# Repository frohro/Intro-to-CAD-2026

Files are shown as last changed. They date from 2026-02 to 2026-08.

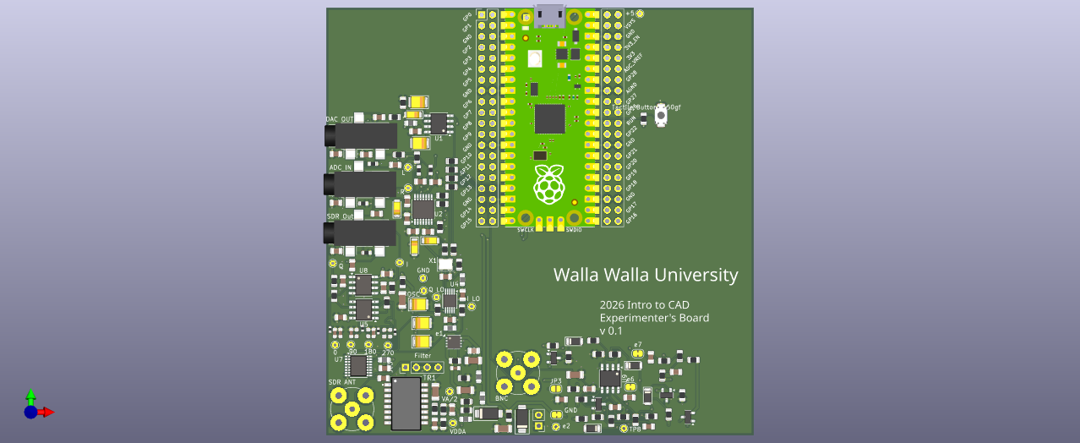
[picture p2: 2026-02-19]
v0.2/Hardware/Intro-to-CAD-2026_Feb_18.png

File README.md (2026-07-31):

# Intro-to-CAD-2026

QSD SDR receiver board (WWU Intro to CAD) with versioned hardware and software.

## Layout

```text
v0.1/                  # First board revision
  Hardware/            # KiCad project for v0.1
  Software/SDR/        # MicroPython, Soapy, firmware/
v0.2/                  # Second board revision (CJC5340 option, etc.)
  Hardware/            # KiCad project for v0.2
  Software/SDR/        # MicroPython, Soapy, firmware/
Docs/                  # Plans, credits, restore notes
```

Pick the **root folder that matches the PCB silkscreen / board revision** you have.

| Board | Open KiCad | Software |
|---|---|---|
| v0.1 | [v0.1/Hardware/Intro-to-CAD-2026.kicad_pro](v0.1/Hardware/Intro-to-CAD-2026.kicad_pro) | [v0.1/Software/SDR](v0.1/Software/SDR) |
| v0.2 | [v0.2/Hardware/Intro-to-CAD-2026.kicad_pro](v0.2/Hardware/Intro-to-CAD-2026.kicad_pro) | [v0.2/Software/SDR](v0.2/Software/SDR) |

Duplication between `v0.1` and `v0.2` is intentional so each board is self-contained.

## Firmware

Native Pico UAC1 projects live under each version's `Software/SDR/firmware/`.
Preferred v0.2 entry point: `v0.2/Software/SDR/firmware/2026_v0.2/`.
Re-sync notes: [Docs/FIRMWARE_RESTORE.md](Docs/FIRMWARE_RESTORE.md).

## History

- Tag `archive/pre-version-split` — layout before this reorg (student `Module_*` at repo root).
- Long-lived git branch `v0.2` held hardware work before the monorepo split; prefer paths under `v0.2/` on `master` going forward.
- Student module credits: [Docs/CREDITS.md](Docs/CREDITS.md).

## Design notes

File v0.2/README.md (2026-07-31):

# Board v0.2

## Hardware

Open [`Hardware/Intro-to-CAD-2026.kicad_pro`](Hardware/Intro-to-CAD-2026.kicad_pro).

Includes dual-ADC options (PCM1808 preferred; CJC5340 retained). Instructor
`Hardware/Frohne/` libs remain because the merged schematic references them.

## Software

| Path | Role |
|---|---|
| `Software/SDR/MicroPythonSDR/` | Pico MicroPython + Quisk helpers |
| `Software/SDR/Soapy-For-2026-Board/` | Soapy module |
| `Software/SDR/firmware/` | C UAC1 firmwares (PCM1808, CJC, Multi) — restore if empty |

Preferred firmware entry point once restored: `firmware/2026_v0.2/` (PCM1808 48/96).
CJC and Multi trees are kept for research even if PCM1808 is preferred on the bench.

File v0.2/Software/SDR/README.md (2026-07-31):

# v0.2 Software / SDR

- **MicroPythonSDR/** — board Python, Quisk configs/widgets (copy shared with v0.1 tree)
- **Soapy-For-2026-Board/** — SoapySDR support module
- **firmware/** — native Pico UAC1 projects

ADC preference: **PCM1808**. CJC5340 and Multi-ADC firmwares are retained under
`firmware/` for future investigation.

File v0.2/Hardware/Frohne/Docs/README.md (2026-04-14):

# Project Documentation: Parallel Summation QSD SDR 

## 1. System Architecture
This receiver is a high-performance Direct Conversion SDR utilizing a **Quadrature Sampling Detector (QSD)** architecture. The design is optimized for high conversion gain and low noise by prioritizing signal symmetry and high-impedance buffering.

## 2. RF Front-End & Mixer
*   **Parallel Summation Mixer:** A modified Tayloe mixer design using a center-tapped 1:1+1 transformer and a dual 1:4 bus switch (**SN74CBT3253**). 
*   **Sampling Logic:** Each I/Q channel samples the transformer secondary twice per LO cycle (I samples at 0° and 180°; Q samples at 90° and 270°). This architecture increases sampling efficiency compared to standard single-sample designs.
*   **Sampling Capacitors:** Utilizes **C0G/NP0** dielectrics (10nF) to ensure linear tracking of the RF signal and to minimize parasitic effects from the CMOS switches.

## 3. Analog Baseband (Instrumentation Amplifier)
*   **Topology:** Each channel (I and Q) utilizes one **OPA1612** dual op-amp package configured as a **2-Op-Amp Instrumentation Amplifier**.
*   **High-Z Buffering:** The sampling capacitors feed directly into non-inverting op-amp inputs. This high-impedance interface prevents "charge sharing" or coupling between phases, preserving the 90° quadrature relationship at high frequencies.
*   **Differential Summation:** The first op-amp acts as a buffer for the negative phase, while the second op-amp performs the subtraction and provides the primary system gain.
*   **Virtual Ground:** A 2.25V bias is provided to the transformer center-tap. Because of the balanced In-Amp design, current demand on this virtual ground is minimized, reducing crosstalk.

## 4. Clocking and Synchronization
*   **Synchronous Clocking:** A single **24.576 MHz CMOS oscillator** serves as the master reference for the entire system.
*   **Local Oscillator:** The clock drives an **MS5351M** (Si5351A) synthesizer to generate the quadrature LO signals.
*   **ADC Clocking:** The same 24.576 MHz source drives the **PCM1808 ADC** (SCKI). This frequency-locks the RF mixing to the digital sampling, eliminating relative frequency drift.

## 5. Power Management and Noise Isolation
*   **Dual Power Path:** A **PMOSFET-based "Ideal Diode"** circuit automatically switches between USB power and an external clean 12V supply. The PMOS prevents high-voltage back-feeding into the USB port while maintaining maximum headroom for the regulators when on USB power.
*   **Analog Regulation:** An **SGM2205** high-voltage LDO provides a quiet 4.5V rail. It features a large **Feed-Forward capacitor ($C_{ff}$)** and a **bulk tantalum reservoir** (isolated by 1$\Omega$) to suppress low-frequency supply noise.
*   **EMI Suppression:** Digital and analog zones are isolated using **ferrite beads** in a star configuration. I2C lines to the LO include series damping resistors to "soften" digital edges and reduce harmonic interference.

## 6. Digital Interface
*   **ADC:** **PCM1808** 24-bit Sigma-Delta converter operating in **Master Mode**.
*   **MCU:** **Raspberry Pi Pico** operating as an **I2S Slave**. Data is captured via PIO state machines and streamed over USB or WiFi (UDP) for processing.
*   **DAC:**  **CJC4334H** a 24 bit DAC with a line level output, and an amplified (suitable for headphones) output.

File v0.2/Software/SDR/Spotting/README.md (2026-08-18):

# WWU 2026 SDR Harvester and Spotting Pipeline

This directory contains a multi-radio receive pipeline for WWU 2026 SDR boards.

The C++ harvester opens one SoapySDR stream per configured radio, captures 96 kHz complex I/Q, translates each requested RF offset to a nonzero audio IF, removes DC, decimates to 12 kHz, and writes UTC-aligned mono WAV files.

The Python reporter watches completed WAV files, runs `jt9` or `wsprd`, parses spots, optionally submits them to PSKReporter, and removes processed or stale files from the capture directory.

The sample configuration enables FT8 and FT4. WSPR is supported but disabled in `config.json` because WSPR frames are 120 seconds long.

## Files

| File | Purpose |
|---|---|
| `config.json` | Capture directory, sample rates, radios, RF centers, mode offsets, and audio IFs |
| `harvester.cpp` | Capture, DSP, UTC framing, and WAV output |
| `CMakeLists.txt` | Builds the C++ harvester |
| `reporter.json` | Callsign/grid, decoder, cleanup, and PSKReporter settings |
| `reporter.py` | Decode, deduplicate, report, and cleanup daemon |
| `cleanup_capture.py` | Manual removal of old or abandoned capture files |
| `build/harvester` | Compiled executable produced by CMake |

The SoapySDR board driver is a separate project in `../Soapy-For-2026-Board` and must be installed first.

## Hardware prerequisites

Each board needs both interfaces available to Ubuntu:

1. USB CDC serial, normally `/dev/ttyACM0`, for firmware control and tuning.
2. USB ALSA capture audio for stereo I/Q.

Check the board with:

```sh
lsusb
ls -l /dev/ttyACM*
cat /proc/asound/cards
cat /proc/asound/cardN/stream0
SoapySDRUtil --find="driver=2026sdr"
```

The audio interface must list 96000 Hz. If it lists only 48000 Hz, set the board's MD1 jumper HIGH or install the 96 kHz firmware variant.

Verify the driver before running the harvester:

```sh
cd ../Soapy-For-2026-Board
python3 test_driver.py --rate 96000 --freq 14074000
```

The test should report `Actual rate: 96000 Hz` and `PASS`.

## Packages

On Ubuntu/Debian:

```sh
sudo apt update
sudo apt install \
  build-essential cmake pkg-config g++ \
  libsoapysdr-dev soapysdr-tools python3-soapysdr \
  libliquid-dev libsndfile1-dev nlohmann-json3-dev \
  libasound2-dev libusb-1.0-0-dev \
  wsjtx python3-watchdog
```

If `python3-watchdog` is unavailable:

```sh
python3 -m pip install --user watchdog
```

Check the required programs and Python import:

```sh
command -v cmake jt9 wsprd SoapySDRUtil
python3 -c 'import watchdog; print("watchdog OK")'
```

The current reporter uses Python's standard library plus `watchdog`. It does not require `requests`.

## Build

From this directory:

```sh
cmake -S . -B build
cmake --build build -j4
```

Re-run the build after changing `harvester.cpp` or `CMakeLists.txt`.

## Configure one radio

Example `config.json`:

```json
{
  "output_dir": "/home/frohro/Projects/Intro-to-CAD-2026/v0.2/Software/SDR/Spotting/captures",
  "sample_rate": 96000,
  "output_rate": 12000,
  "sdrs": [
    {
      "sdr_id": "Board_1",
      "serial_port": "/dev/ttyACM0",
      "audio_label": "S2026",
      "center_freq": 14074000,
      "modes": [
        { "mode": "FT8", "offset": 0, "audio_if": 1500 },
        { "mode": "FT4", "offset": 6000, "audio_if": 1500 }
      ]
    }
  ]
}
```

Meanings:

- `output_dir` is the directory used for temporary and completed WAV files. The current configuration uses persistent storage under the project directory.
- `sdr_id` is unique and becomes part of every WAV filename.
- `serial_port` selects the board's CDC port.
- `audio_label` is a case-insensitive ALSA-card search string.
- `center_freq` is the programmed RF center in Hz.
- A positive `offset` means the target RF signal is `center_freq + offset`.
- `audio_if` is the target frequency in the 12 kHz WAV. Use a nonzero value such as 1500 Hz to avoid DC and 1/f noise.
- The NCO frequency is `(audio_if - offset) / 96000`.

The current DSP chain includes a DC blocker, a 0.05 normalized anti-alias filter, decimation by 8, and monitoring gain in the WAV writer. Watch for clipping if changing gain.

Use `output_dir` in both JSON files whenever the capture location changes.

## Configure multiple radios

Add one object per board to the `sdrs` array. Each entry needs a unique `sdr_id`, serial port, and ALSA label:

```json
{
  "sdr_id": "Board_2",
  "serial_port": "/dev/ttyACM1",
  "audio_label": "S2026_1",
  "center_freq": 21107000,
  "modes": [
    { "mode": "FT8", "offset": -33000, "audio_if": 1500 },
    { "mode": "FT4", "offset": 33000, "audio_if": 1500 }
  ]
}
```

This example puts 15 m FT8 at 21.074 MHz and 15 m FT4 at 21.140 MHz in the same 96 kHz capture window. Use udev rules for stable serial names when possible. Inspect `/proc/asound/cards` after both boards are plugged in and replace `/dev/ttyACM1` and `S2026_1` with the actual second-board identifiers. Do not map two entries to the same serial device or ALSA card.

The harvester creates one thread and one SoapySDR stream per `sdrs` entry. Example output names:

```text
Board_1_FT8_20260813T001500Z.wav
Board_2_FT8_20260813T001500Z.wav
```

### Missing or mismatched radio behavior

Each radio worker is isolated. If a configured serial port, ALSA label, or Soapy stream cannot be opened, the harvester logs the radio ID and retries that radio every five seconds. Other radios continue capturing, and the missing radio can recover automatically when it is connected later. A failed or disconnected radio does not publish an incomplete WAV frame; any `.wav.part` file for that frame is discarded.

The `/dev/ttyACM0`, `/dev/ttyACM1`, and similar numbers are assigned by Ubuntu and can change when boards are unplugged or reconnected. A path that exists may still refer to the wrong physical board. For reliable multi-radio operation, create stable udev symlinks based on each board's USB identity and use those symlinks in `config.json`. Also verify that every board has a distinct ALSA `audio_label`.

## Manual Si5351 tuning

The planned JSON shape for manual PLL/register values is:

```json
"si5351": {
  "si5351_hz": 7074000,
  "N": 86,
  "a": 24,
  "b": 0,
  "c": 1,
  "p1": 2560,
  "p2": 0,
  "p3": 1
}
```

The current harvester does not yet pass this object to `setFrequency()`. Until the Soapy driver and harvester are updated together, the driver calculates Si5351 parameters automatically. Do not use the example values blindly.

## Configure reporter.json

Edit the receiver identity:

```json
{
  "output_dir": "/home/frohro/Projects/Intro-to-CAD-2026/v0.2/Software/SDR/Spotting/captures",
  "harvester_config": "config.json",
  "callsign": "KL7NA",
  "grid": "DN06",
  "decode_timeout": 180,
  "stale_file_seconds": 900,
  "cleanup_interval_seconds": 60,
  "pskreporter": {
    "enabled": true,
    "host": "report.pskreporter.info",
    "port": 4739,
    "identifier": 2026
  }
}
```

Keep PSKReporter disabled until local decoding works. When enabled, `reporter.py` sends UDP packets to `report.pskreporter.info:4739`.

The reporter reads `config.json` through `harvester_config`, so it can reconstruct RF frequency from each WAV:

```text
RF frequency = center_freq + offset + decoded_audio_frequency - audio_if
```

## Start the pipeline

Start the reporter first:

```sh
cd /home/frohro/Projects/Intro-to-CAD-2026/v0.2/Software/SDR/Spotting
python3 reporter.py --config reporter.json
```

In a second terminal, start the harvester:

```sh
cd /home/frohro/Projects/Intro-to-CAD-2026/v0.2/Software/SDR/Spotting
./build/harvester config.json
```

The harvester writes `.wav.part` while a frame is being written and atomically renames it to `.wav` when complete. The reporter handles both normal creation and atomic move events. It also processes existing WAV files when it starts.

Stop either daemon with `Ctrl-C`. The harvester does not publish incomplete frames.

## Capture storage

Each frame is a short, sequential 12 kHz WAV file, and the reporter normally deletes it immediately after decoding. A local SSD is the recommended default; an older spinning disk should also work because the data rate is low and decode latency is not critical.

The current configuration uses:

```text
/home/frohro/Projects/Intro-to-CAD-2026/v0.2/Software/SDR/Spotting/captures
```

Create it once if necessary:

```sh
mkdir -p /home/frohro/Projects/Intro-to-CAD-2026/v0.2/Software/SDR/Spotting/captures
```

If the storage location changes, update `output_dir` in both `config.json` and `reporter.json` to the same writable directory.

## Run automatically with systemd

The recommended setup uses per-user systemd services. This keeps the daemons running as your normal user, which is important for access to the USB serial and ALSA devices.

Create the user-service directory:

```sh
mkdir -p ~/.config/systemd/user
```

Create `~/.config/systemd/user/wwu2026-reporter.service`:

```ini
[Unit]
Description=WWU 2026 SDR spot reporter
After=network-online.target
Wants=network-online.target

[Service]
Type=simple
WorkingDirectory=/home/frohro/Projects/Intro-to-CAD-2026/v0.2/Software/SDR/Spotting
ExecStart=/usr/bin/python3 /home/frohro/Projects/Intro-to-CAD-2026/v0.2/Software/SDR/Spotting/reporter.py --config /home/frohro/Projects/Intro-to-CAD-2026/v0.2/Software/SDR/Spotting/reporter.json
Restart=on-failure
RestartSec=5

[Install]
WantedBy=default.target
```

Create `~/.config/systemd/user/wwu2026-harvester.service`:

```ini
[Unit]
Description=WWU 2026 SDR harvester
After=wwu2026-reporter.service
Wants=wwu2026-reporter.service

[Service]
Type=simple
WorkingDirectory=/home/frohro/Projects/Intro-to-CAD-2026/v0.2/Software/SDR/Spotting
ExecStart=/home/frohro/Projects/Intro-to-CAD-2026/v0.2/Software/SDR/Spotting/build/harvester /home/frohro/Projects/Intro-to-CAD-2026/v0.2/Software/SDR/Spotting/config.json
Restart=on-failure
RestartSec=5

[Install]
WantedBy=default.target
```

Reload, enable, and start both services:

```sh
systemctl --user daemon-reload
systemctl --user enable --now wwu2026-reporter.service
systemctl --user enable --now wwu2026-harvester.service
```

Check status and follow logs:

```sh
systemctl --user status wwu2026-reporter.service
systemctl --user status wwu2026-harvester.service
journalctl --user -u wwu2026-reporter.service -f
journalctl --user -u wwu2026-harvester.service -f
```

Stop or disable them:

```sh
systemctl --user disable --now wwu2026-harvester.service wwu2026-reporter.service
```

For services to start even when you are not logged into a graphical session, enable user lingering once:

```sh
sudo loginctl enable-linger frohro
```

If the harvester cannot open `/dev/ttyACM0` or the ALSA device under systemd, verify that your user has the required `dialout` and `audio` group membership, then log out and back in:

```sh
groups
sudo usermod -aG dialout,audio frohro
```

## What the scripts do

### `harvester.cpp`

For every configured radio it:

1. Creates a `2026sdr` Soapy device.
2. Sets 96 kHz capture and the configured RF center.
3. Creates an NCO and FIR decimator branch for every requested mode.
4. Removes DC and translates the requested RF offset to `audio_if`.
5. Decimates 96 kHz to 12 kHz.
6. Writes real-valued 16-bit mono WAV frames aligned to UTC boundaries.

FT8 frames are 15 seconds, FT4 frames are 7.5 seconds, and WSPR frames are 120 seconds.

### `reporter.py`

For each complete WAV it:

1. Identifies FT8, FT4, or WSPR from the filename.
2. Runs `jt9 -8`, `jt9 -5`, or `wsprd`.
3. Parses callsign, grid, SNR, and audio frequency.
4. Suppresses duplicate `(frame, mode, callsign, frequency)` spots.
5. Logs accepted spots.
6. Optionally sends them to PSKReporter.
7. Deletes the WAV after decoding.

If decoding fails or times out, the WAV remains until stale-file cleanup removes it.

### `cleanup_capture.py`

Remove only files older than 15 minutes:

```sh
python3 cleanup_capture.py --directory /home/frohro/Projects/Intro-to-CAD-2026/v0.2/Software/SDR/Spotting/captures --older-than 900
```

Remove all WAV and partial files after stopping both daemons:

```sh
python3 cleanup_capture.py --directory /home/frohro/Projects/Intro-to-CAD-2026/v0.2/Software/SDR/Spotting/captures --all
```

The reporter also performs automatic cleanup according to `stale_file_seconds` and `cleanup_interval_seconds`.

## Testing without an antenna

Do not run the reporter for this test if you want to keep the WAV files:

```sh
python3 cleanup_capture.py --directory /home/frohro/Projects/Intro-to-CAD-2026/v0.2/Software/SDR/Spotting/captures --all
timeout --signal=INT 40s ./build/harvester config.json
find /home/frohro/Projects/Intro-to-CAD-2026/v0.2/Software/SDR/Spotting/captures -maxdepth 1 -type f -name '*.wav' -printf '%f %s bytes\n' | sort
file /home/frohro/Projects/Intro-to-CAD-2026/v0.2/Software/SDR/Spotting/captures/*.wav
```

You can listen with:

```sh
aplay /home/frohro/Projects/Intro-to-CAD-2026/v0.2/Software/SDR/Spotting/captures/Board_1_FT8_*.wav
```

No antenna normally produces thermal noise and receiver artifacts rather than decodes.

## Troubleshooting

### No Soapy device

```sh
SoapySDRUtil --find="driver=2026sdr"
SoapySDRUtil --make="driver=2026sdr,serial_port=/dev/ttyACM0,audio_label=S2026"
```

Check udev permissions, `/dev/ttyACM*`, `/proc/asound/cards`, and `SoapySDRUtil --info`.

### 96 kHz fails

```sh
cat /proc/asound/cardN/stream0
```

The capture interface must list a 96000 Hz alternate setting. Check the MD1 jumper or board firmware.

### No WAV files

Run the harvester in the foreground and verify the capture directory:

```sh
mkdir -p /home/frohro/Projects/Intro-to-CAD-2026/v0.2/Software/SDR/Spotting/captures
test -w /home/frohro/Projects/Intro-to-CAD-2026/v0.2/Software/SDR/Spotting/captures && echo writable
```

### WAV files but no spots

Run a decoder manually:

```sh
jt9 -8 /home/frohro/Projects/Intro-to-CAD-2026/v0.2/Software/SDR/Spotting/captures/Board_1_FT8_YYYYMMDDTHHMMSSZ.wav
jt9 -5 /home/frohro/Projects/Intro-to-CAD-2026/v0.2/Software/SDR/Spotting/captures/Board_1_FT4_YYYYMMDDTHHMMSSZ.wav
```

Check mode duration, 12 kHz sample rate, UTC alignment, audio IF, antenna, and RF frequency.

### Local spots but no PSKReporter spots

Set `pskreporter.enabled` to `true`, verify callsign/grid, and check outbound UDP access to `report.pskreporter.info:4739`.

## Time alignment

Frame boundaries use the host system clock in UTC. Keep Ubuntu synchronized with chrony or systemd-timesyncd. The Soapy driver supplies no hardware timestamps, so host-clock timing cannot correct USB/audio-clock latency.

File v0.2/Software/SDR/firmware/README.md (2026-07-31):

# v0.2 SDR firmware

Sources imported from `cptr-480-2026-instructor/Research` (build trees excluded).

| Folder | Description |
|---|---|
| `2026_v0.2/` | PCM1808 48/96 kHz dual-rate UAC1 (**preferred starting point**) |
| `48_kHz_2026_v0.2/` | PCM1808 dual-rate / Johnson-mode variant |
| `96_kHz_2026_v0.2/` | PCM1808 96 kHz |
| `48_kHz_CJC_5340_2026_v0.2/` | CJC5340 48 kHz (research; PCM1808 preferred) |
| `96_kHz_CJC_5340_2026_v0.2/` | CJC5340 96 kHz |
| `192_kHz_CJC_5340_2026_v0.2/` | CJC5340 192 kHz (16-bit USB + dither) |
| `2026_v0.2_Multi/` | Multi-ADC experimental (PCM1808 + CJC5340) |

Build each project with the Pico SDK / CMake flow described in that folder's README.
Do not commit `build/` output.

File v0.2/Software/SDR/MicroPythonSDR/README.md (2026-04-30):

# MicroPythonSDR — Intro-to-CAD-2026 / Cadyn Pico SDR

MicroPython firmware that turns a Raspberry Pi Pico (RP2040) into the
local-oscillator (LO) controller for a Quadrature Sampling Detector (QSD)
SDR receiver.  The Pico tunes the Si5351/MS5351M clock generator to produce
two clocks 90° apart (CLK0 = I, CLK1 = Q) that drive the QSD mixer.  Analog
I/Q audio from the mixer goes to the left/right channels of an external
soundcard, and Quisk (or any compatible SDR program) demodulates it on the PC.

```
RF Antenna
    │
    ▼
H1102NLT (input balun)
    │
    ▼
QSD mixer ◄── CLK0 (0°)  ┐
          ◄── CLK1 (90°) ┘  MS5351M / Si5351A  ◄── I²C (SDA/SCL) ── Pico
    │
    ▼
OPA1612 (I/Q audio amp)
    │
    ▼
3.5 mm stereo jack  ──────► PC soundcard L (I) / R (Q)
                                │
                                ▼
                           Quisk SDR software
                                │
                         USB serial ──► Pico  (FREQ,<hz> commands)
```

---

## Hardware

### Intro-to-CAD-2026 board

| Item | Detail |
|---|---|
| MCU | Raspberry Pi Pico (RP2040) |
| Clock generator | MS5351M (Si5351A-compatible, LCSC C1509083), I²C addr `0x60` |
| I²C pins | **SDA = GPIO 12**, **SCL = GPIO 13** (I²C bus 0) |
| Reference oscillator | 24.576 MHz internal to MS5351M |
| Mixer / amp | OPA1612 dual op-amp in QSD configuration |
| RF input balun | H1102NLT Ethernet transformer |
| Audio output | 3.5 mm stereo jack → external soundcard |
| PCM1808 ADC | Present on board; *not used by this firmware* (future Phase 2) |
| 24.576 MHz CMOS osc | YC24.576MUBCE2O — feeds PCM1808 SCKI only |
| OLED display | SSD1306 on same I²C bus; displays frequency and PLL parameters when connected |

### Cadyn's Pico SDR (reference build)

| Item | Detail |
|---|---|
| Clock generator | Si5351A-B-GT, I²C addr `0x60` |
| I²C pins | **SDA = GPIO 4**, **SCL = GPIO 5** (I²C bus 0) |
| Reference oscillator | ~25 MHz internal crystal (calibrated value in `config.py`) |

---

## OLED Display

The firmware automatically detects and uses an SSD1306 OLED display (128x64 pixels) connected to the same I²C bus as the MS5351M clock generator. The display shows:

- Current frequency in MHz (e.g., "Freq: 7.074 MHz")
- PLL parameters: M (PLL multiplier) and N (output divider)

The display is only updated when the OLED is physically connected; if disconnected, the firmware continues to operate normally without errors.

---

## File layout

```
MicroPythonSDR/
├── 2026_Board/      MicroPython files for Intro-to-CAD-2026 board
│   ├── main.py      Entry point
│   ├── config.py    Board configuration (set to INTRO_CAD_2026)
│   ├── si5351.py    Si5351/MS5351M driver
│   └── radio.py     Radio class
├── Cadyn_Board/     MicroPython files for Cadyn's Pico SDR
│   ├── main.py      Entry point
│   ├── config.py    Board configuration (set to CADYN_PICO_SDR)
│   ├── si5351.py    Si5351/MS5351M driver
│   └── radio.py     Radio class
├── quisk_conf_2026.py     Quisk configuration for 2026 board
├── quisk_conf_cadyn.py    Quisk configuration for Cadyn's board
└── README.md              This file
```

---

## Deployment

### MicroPython Firmware for the Pico

#### 1. Install MicroPython on the Pico

Flash the latest MicroPython UF2 from <https://micropython.org/download/RPI_PICO/>.

#### 2. Choose your board version

- For the **Intro-to-CAD-2026 board**: Use files from `2026_Board/`
- For **Cadyn's Pico SDR**: Use files from `Cadyn_Board/`

#### 3. Copy MicroPython files to the Pico

Using **MicroPico** (VS Code extension) or **Thonny**:

Copy these four files from your chosen board directory to the root (`/`) of the Pico filesystem:

```
main.py
config.py
si5351.py
radio.py
```

The Pico runs `main.py` automatically on power-up.

### Quisk SDR Software Setup

#### 1. Install Quisk

Install Quisk on your computer (Linux recommended):

```bash
sudo apt install quisk  # Ubuntu/Debian
# or
pip install quisk       # from PyPI
```

#### 2. Install Quisk configurations

Copy the appropriate Quisk configuration file to your Quisk config directory:

```bash
# For 2026 board:
cp quisk_conf_2026.py ~/.quisk/

# For Cadyn's board:
cp quisk_conf_cadyn.py ~/.quisk/
```

#### 3. Run Quisk with hardware selection

Launch Quisk and select your radio from the menu:

```bash
quisk -a
```

This opens Quisk with a menu to choose between available hardware configurations. Select the appropriate one for your connected board.

The configurations are named to distinguish between the two radios, allowing you to switch between them easily.

### 4. Verify I²C connectivity

Before running the full firmware, run an I²C scan to confirm the MS5351M
responds at address `0x60`:

```python
from machine import I2C, Pin
i2c = I2C(0, freq=400_000, scl=Pin(13), sda=Pin(12))
print([hex(a) for a in i2c.scan()])   # should include 0x60
```

Paste this into the Pico REPL via Thonny or `mpremote`.

---

## Quisk setup (PC side)

1. Install Quisk: `pip install quisk` (or from <https://james.ahlstrom.name/quisk/>).

2. Run Quisk pointing at `quisk_conf_intro_cad.py` from this directory:
   ```
   quisk --conf /path/to/MicroPythonSDR/quisk_conf_intro_cad.py
   ```
   The file configures:
   - Serial port `/dev/ttyACM0` (or `ttyACM1`) at 115 200 baud
   - PulseAudio soundcard for I/Q capture at 48 kHz
   - `open()` queries `XTAL` to get the crystal reference frequency, sends `RATE,48000`
   - `ChangeFrequency()` searches for the best golden LO on the PC, sends `FREQ,<lo>` to the Pico

   If you change the soundcard sample rate, update `sample_rate` in
   `quisk_conf_intro_cad.py`.

3. Start Quisk.  It will open the serial port, confirm firmware version,
   read the crystal frequency, send the sample rate, and begin sending
   `FREQ,<lo>` commands as you tune.  The Pico responds with the frequency
   and an `OK,G/F/X,<value>` status line.

### Serial command reference

| Command | Response | Notes |
|---|---|---|
| `FREQ,<hz>\n` | `<hz>\nOK,G,<signed_offset>\n` | Tune; `G` = integer PLL, signed_offset = f_lo − f_requested (Hz) |
| `FREQ,<hz>\n` | `<hz>\nOK,F,0\n` | Tune; `F` = fractional PLL (exact frequency, score omitted) |
| `FREQ,<hz>\n` | `<hz>\nOK,X,0\n` | Tune; `X` = fallback, VCO out of spec |
| `FREQ,\n` | `<current hz>\nOK,...\n` | Query current frequency |
| `RATE,<hz>\n` | `OK\n` | Set soundcard sample rate (used for NeoPixel threshold) |
| `XTAL\n` | `<crystal_hz>\nOK\n` | Query reference crystal frequency (Hz, float) |
| `VER\n` | `SDR Pi Pico version 0.1\nOK\n` | Firmware identification |

**Signed offset** (`OK,G,<offset>`): positive means the LO is *above* the
requested frequency → the DC spike appears *below* the station in the audio
passband.  Negative means the LO is *below* → spike is *above* the station.
Quisk PC code uses this to track exactly where the DC spike lands.

---

## Frequency range

| Band segment | Output divider (N) | VCO range |
|---|---|---|
| 3.8 – 7.999 MHz | 100 | 380 – 800 MHz |
| 8.0 – 10.999 MHz | 80 | 640 – 880 MHz |
| 11.0 – 14.999 MHz | 50 | 550 – 750 MHz |
| 15.0 – 30.0 MHz | 30 | 450 – 900 MHz |

### Frequency selection algorithm

The firmware uses a two-priority ranked search over all valid output dividers N
to find the best LO setting for each requested frequency.

**Score metric**

For each candidate N, the PLL feedback multiplier is:

```
M_exact = freq × N / F_ref
```

Define `frac(M) = M_exact − floor(M_exact)`, then:

```
score = min(frac(M), 1 − frac(M))   # 0 = integer (best), 0.5 = worst
```

Score 0 means M is a pure integer → zero fractional spurs.  Score 0.5 means M
sits exactly halfway between integers → worst fractional spur energy.

**Search bounds**

- **N_min = ceil(600 MHz / freq)**, **N_max = min(127, floor(900 MHz / freq))**
  — keeps VCO in the Si5351 specified range of 600–900 MHz
- **N ≤ 127** — the PHOFF register is 7-bit; the 90° formula PHOFF = N only
  works when N fits in 7 bits

**LO selection is now on the Quisk PC side**

`quisk_conf_intro_cad.py::ChangeFrequency()` queries the crystal frequency
from the Pico on startup (`XTAL` command) and runs the full golden-search in
Python each time `tune` changes.  It then sends the exact LO frequency to the
Pico via `FREQ,<lo>`.  The Pico just programs what it is told.

**Sweet-spot placement (normal tune)**

Among all golden LOs within ±half_bw of `tune`, the Quisk code picks the one
where:
```
cost = | |lo_offset| − sample_rate/4 |
```
is minimised.  This places the DC spike near the passband *edge* (at ±12 kHz
for a 48 kHz card), away from both DC and the station of interest.

**Arrow-press hopping**

When an arrow button is pressed, the code detects the direction from
`sign(vfo_in − last_lo)` and hops to the nearest golden LO in that direction.
If none exists, a fractional ±quarter-bandwidth shift is used so the DC spike
always moves (it never stays on the station).

**Fallback (fractional PLL)**

When no golden LO exists within ±half_bw of `tune`, the Pico uses its
fractional PLL to hit the requested frequency exactly.  Score 0 = best (M is
very close to an integer), 0.5 = worst.  NeoPixel shows yellow (score < 0.10)
or red (score ≥ 0.10).

Example: 14.074 MHz (20 m FT8) — no golden within ±24 kHz → fractional,
N=49, M=28.061, score=0.061 (yellow).

This typically gives **10–50× better spur scores** vs. the original fixed four-N
scheme and provides a dense set of golden frequencies across the HF range.

### NeoPixel status LED

The YD-RP2040 V1.3 carries a WS2812B RGB NeoPixel on **GPIO 23**.  The
firmware updates its colour every time the LO frequency is set:

| Colour | Meaning |
|---|---|
| **Green** | Integer PLL — golden frequency, zero fractional spurs |
| **Yellow** | Fractional PLL, low spur score (score < 0.10) |
| **Red** | Fractional PLL, high spur score (score ≥ 0.10) |
| **Dim purple** | Fallback / VCO out of spec / initialising |

The Quisk status bar (bottom of the screen) also shows the same information
as text, updated via the `HeartBeat()` callback in `quisk_conf_intro_cad.py`.
Example messages:
- `GOLDEN  +3888 Hz  (integer PLL — no spurs)` — LO is 3888 Hz above tune
- `GOLDEN  -970 Hz  (integer PLL — no spurs)` — LO is 970 Hz below tune
- `frac  (exact freq)` — fractional PLL, LO = exact requested frequency
- `fallback  (VCO out of spec)` — below ~3.8 MHz or hardware limit hit

### Using the Quisk IF arrows for golden-frequency hopping

The two blue arrow buttons in Quisk (labelled **←** and **→** near the
passband display) now hop the LO to the *next* golden (integer-PLL) frequency
in the pressed direction, keeping the station you are listening to fixed
inside the audio passband:

- **→ (right arrow)**: hops to the next golden LO *above* the current one.
- **← (left arrow)**: hops to the next golden LO *below* the current one.
- If no golden exists in that direction within the passband, the LO shifts by
  `sample_rate / 4` (12 kHz for 48 kHz card) to push the DC spike away from
  centre.  NeoPixel shows yellow or red.
- The station's RF frequency (`tune`) never changes — only the LO moves.
  Quisk adjusts the audio IF offset automatically.

This lets you A/B compare integer-PLL (green, no spurs) against fractional
(yellow/red) while keeping the station centred in the passband.

### Key ham frequencies — PLL mode (F_ref = 24.576 MHz, half\_bw = 24 kHz)

Computed from the golden-search algorithm in `quisk_conf_intro_cad.py`.
INTEGER = pure integer PLL (NeoPixel green); fractional = best fractional PLL
(yellow or red).  **Signed offset** = f_lo − f_requested; positive means the
LO is above tune, raising the DC spike below the station in the audio passband.

| Frequency | Band / Mode | PLL | M | N | Signed LO offset | Score |
|---|---|---|---|---|---|---|
| 5.000 000 MHz | WWV 5 MHz | INTEGER | 25 | 123 | +4 878 Hz | — |
| 6.000 000 MHz | SW 6 MHz | INTEGER | 31 | 127 | +1 134 Hz | — |
| 7.074 000 MHz | 40 m FT8 | INTEGER | 36 | 125 | +3 888 Hz | — |
| 7.200 000 MHz | 40 m SSB | INTEGER | 29 | 99 | +970 Hz | — |
| 7.290 000 MHz | 40 m AM | INTEGER | 35 | 118 | +509 Hz | — |
| 9.500 000 MHz | SW 9.5 MHz | INTEGER | 29 | 75 | +2 720 Hz | — |
| 10.000 000 MHz | WWV 10 MHz | INTEGER | 35 | 86 | +1 861 Hz | — |
| 10.100 000 MHz | 30 m CW | INTEGER | 30 | 73 | +274 Hz | — |
| 10.140 000 MHz | 30 m FT8 | INTEGER | 33 | 80 | +2 400 Hz | — |
| 14.074 000 MHz | 20 m FT8 | fractional | 28.061 | 49 | 0 (exact) | 0.0610 |
| 14.225 000 MHz | 20 m SSB | INTEGER | 33 | 57 | +3 211 Hz | — |
| 15.000 000 MHz | WWV 15 MHz | INTEGER | 36 | 59 | +4 475 Hz | — |
| 18.100 000 MHz | 17 m FT8 | INTEGER | 28 | 38 | +8 632 Hz | — |
| 18.130 000 MHz | 17 m SSB | INTEGER | 31 | 42 | +9 429 Hz | — |
| 21.074 000 MHz | 15 m FT8 | INTEGER | 30 | 35 | +8 857 Hz | — |
| 21.300 000 MHz | 15 m SSB | INTEGER | 26 | 30 | +800 Hz | — |
| 24.915 000 MHz | 12 m FT8 | fractional | 25.345 | 25 | 0 (exact) | 0.3449 |
| 24.940 000 MHz | 12 m SSB | fractional | 25.370 | 25 | 0 (exact) | 0.3703 |
| 28.074 000 MHz | 10 m FT8 | INTEGER | 32 | 28 | +12 857 Hz | — |
| 28.400 000 MHz | 10 m SSB | fractional | 30.046 | 26 | 0 (exact) | 0.0456 |

**Note on 12 m (≈ 24.9 MHz):** With F_ref = 24.576 MHz, the available N range
for this band is very narrow (N = 25–36) and none produce an M close to an
integer.  The NeoPixel will show **red** on 12 m.

**Note on signed LO offsets:** The Quisk golden-search algorithm chooses the
golden LO closest to a \(|offset| = sample\_rate/4 = 12\,000\) Hz sweet spot.
The table above shows the best initial pick; arrow presses will hop to other
golden LOs in the same list.

---

## How quadrature generation works

The Si5351/MS5351M generates Fout using two stages:

```
Fout = F_ref × M / N
```

where  
**M** = PLL feedback multiplier (fractional: `a + b/c` encoded in p1/p2/p3)  
**N** = output Multisynth divider (**must be integer** for quadrature)

### Why N must be an integer

The PHOFF register (Reg 165/166) sets the phase delay in units of
¼ VCO period.  Setting `CLK1_PHOFF = N` produces:

```
delay = N × (1/4 VCO period) = 1/4 output period = 90°
```

This identity holds **only** when N is a whole number.
`radio.py` always passes an integer `mult` to `set_frequency()`, and
`si5351.py` uses `clock.configure_integer(pll, mult)` for the output stage,
so the quadrature condition is always satisfied.

### Why the PLL uses fractional M

With `F_ref = 24.576 MHz` and integer-only M, the minimum tuning step
would be `F_ref / N`.  With N = 100 that is **245.76 kHz per step** —
far larger than the ~48 kHz audio bandwidth of a soundcard SDR.
Fractional M lets the VCO be placed at any frequency with sub-Hz
resolution, which is what Quisk's `FREQ,<hz>` command requires.

---

## Crystal calibration

The MS5351M's internal oscillator frequency is not exactly 24.576 MHz.
To calibrate:

1. Tune to a known-accurate signal (WWV at 5, 10, or 15 MHz is convenient;
   a calibrated signal generator works too).

2. In Quisk, note the offset between the displayed frequency and the zero-beat
   or carrier tone.  At 10 MHz a 100 Hz error means the crystal is off by
   `100 / 10e6 = 10 ppm`.

3. Compute the corrected crystal frequency:
   ```
   crystal_corrected = 24_576_000 × (1 + error_Hz / nominal_Hz)
   ```

4. Update `CRYSTAL_FREQ` in `config.py` with the new value.

---

## Troubleshooting

| Symptom | Likely cause | Fix |
|---|---|---|
| I²C scan returns empty list | Wiring or pull-up resistors | Check SDA/SCL connections; the RP2040 has internal weak pull-ups but strong external pull-ups (4.7 kΩ) are recommended |
| `assert` error on startup | VCO out of range for requested frequency | Verify frequency is within 3.8 – 30 MHz |
| Quisk sees no serial port | Wrong `/dev/ttyACM*` | Check `quisk_conf_sdr_pi_pico.py`; try `ls /dev/ttyACM*` |
| Image rejection poor | Wrong phase offset | Confirm CLK0 and CLK1 are 90° apart with an oscilloscope |
| Frequency off by fixed amount | Crystal not calibrated | Follow crystal calibration procedure above |
| Startup hang (rare) | SYS_INIT poll | Power-cycle the board; if persistent, check 3.3 V rail |

---

## Future work (Phase 2)

The Intro-to-CAD-2026 board includes a **PCM1808 stereo I²S ADC** clocked
by the 24.576 MHz CMOS oscillator (48/96 kHz sample rates).  Once the LO
firmware is proven, a Phase 2 extension could:

- Read I²S data from the PCM1808 on the Pico's PIO state machines
- Stream audio over USB as a USB Audio Class device
- Eliminate the external soundcard entirely

---

## License

Driver code derived from the Adafruit CircuitPython Si5351 library
(Tony DiCola, MIT License).  All modifications and additions are also MIT.

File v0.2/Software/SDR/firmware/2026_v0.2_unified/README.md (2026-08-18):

# Unified Pico W SDR Firmware (v0.2)

High-performance, dual-mode SDR firmware for the **Intro-to-CAD-2026 v0.2 SDR Receiver** based on the **Raspberry Pi Pico W (RP2040 + CYW43439)**.

---

## 1. System Architecture

```
                       +-------------------------------------------------------------+
                       |                    Raspberry Pi Pico W                      |
                       |                                                             |
+-----------------+    |   +-------------------+              +------------------+   |    USB Type-C
| PCM1808 ADC     |--->|   | Core 1 (Audio VM) |              | Core 0 (Network) |   |===> UAC1 (24-bit 48/96k)
| (I2S Stereo 24b)|    |   | - PIO State Mach  |  FIFO Queue  | - lwIP / CYW43   |   |     USB CDC Control
+-----------------+    |   | - Ping-Pong DMA   |------------->| - TinyUSB UAC1   |   |
                       |   | - Dynamic 48k/96k |              | - On-Chip Si5351 |   |    WiFi (UDP 1024)
+-----------------+    |   +-------------------+              +------------------+   |~~~> OpenHPSDR Protocol 1
| Si5351a Synth   |<---|                                               |             |     (SDR++, Thetis, Quisk)
| (I2C QSD LO)    |----+-----------------------------------------------+             |
+-----------------+                                                                  |
                       +-------------------------------------------------------------+
```

### Dual-Core Threading Model
- **Core 1 (Real-Time Audio DSP)**:
  - Samples the **PCM1808 24-bit ADC** via custom RP2040 PIO microcode (`i2s_rx.pio`) on GPIO 9, 10, 11.
  - Alternates ping-pong DMA buffers with zero CPU jitter.
  - Pushes 32-bit aligned I/Q frames into the lock-free inter-core hardware FIFO.
- **Core 0 (Networking & Protocol Engine)**:
  - Runs the **CYW43439 WiFi driver** and **lwIP** network stack.
  - Encapsulates stereo I/Q frames into **OpenHPSDR Protocol 1** frames (1032 bytes, EP6).
  - Packs stereo `S24_3LE` audio frames into the TinyUSB isochronous audio endpoint (UAC1).
  - Listens on USB CDC (`/dev/ttyACM0`) and TCP port 5000 for frequency and mode commands.
  - Computes the **Golden Integer LO algorithm on-chip in ~8 µs** upon receiving any `FREQ,<hz>` command.

---

## 2. OpenHPSDR Protocol 1 Subset Implementation

The firmware implements the standard **OpenHPSDR Protocol 1** over UDP Port `1024`, allowing automatic detection and streaming with SDR++, LinHPSDR, Thetis, SparkSDR, and Quisk.

### A. Discovery Broadcast (`0xEFFE 0x02`)
The host broadcasts a 60-byte UDP packet to port `1024` with header `0xEF 0xFE 0x02`. The Pico W replies with:
- `payload[0..1] = 0xEF 0xFE`
- `payload[2] = 0x02` (Discovery reply)
- `payload[3..8] = [Pico W WiFi MAC Address]`
- `payload[9] = 0x21` (Firmware version v3.3)
- `payload[10] = 0x06` (Board ID: Hermes / Metis compatible)

### B. Stream Control (`0xEFFE 0x04`)
- **Start Stream**: Host sends `0xEF 0xFE 0x04 0x01` -> Pico W begins transmitting 1032-byte I/Q frames to host IP/port.
- **Stop Stream**: Host sends `0xEF 0xFE 0x04 0x00` -> Pico W halts UDP transmission.

### C. In-Band Command & Control (C&C Header `0x7F 0x7F 0x7F`)
Embedded within the 512-byte subframe sync headers:
- **Command 0x01 (Tune Frequency)**: `[0x02, (freq>>24), (freq>>16), (freq>>8), freq]`. When received, Core 0 invokes the on-chip Si5351 synthesizer engine immediately.
- **Command 0x00 (Sample Rate)**: Speed bits `0x00` = 48,000 SPS, `0x01` = 96,000 SPS.

### D. I/Q Frame Structure (EP6: 1032 Bytes)
Each packet contains a 4-byte big-endian sequence number and **two 512-byte subframes** (126 total stereo samples):
```
Byte 0..1:   0xEF 0xFE (Frame Sync)
Byte 2:      0x01 (EP6 I/Q Data identifier)
Byte 3..6:   Sequence Number (32-bit big endian)
Byte 7:      Reserved (0x00)

[Subframe 1: 512 Bytes]
Byte 8..10:  Sync (0x7F 0x7F 0x7F)
Byte 11..15: C&C Command / Control data
Byte 16..519: 63 stereo samples (8 bytes each):
              [I2, I1, I0] (24-bit Left/I, MSB first)
              [Q2, Q1, Q0] (24-bit Right/Q, MSB first)
              [Mic1, Mic0] (16-bit microphone/reserved)

[Subframe 2: 512 Bytes]
Byte 520..522: Sync (0x7F 0x7F 0x7F)
Byte 523..527: C&C Command / Control data
Byte 528..1031: 63 stereo samples (same format as Subframe 1)
```

---

## 3. Hardware Pinout (Intro-to-CAD-2026 v0.2)

| Signal | Pico W GPIO | Function |
| :--- | :--- | :--- |
| **I2S DATA** | GPIO 9 | PCM1808 SDOUT (PIO Input) |
| **I2S BCK** | GPIO 10 | PCM1808 Bit Clock (PIO Input) |
| **I2S WS** | GPIO 11 | PCM1808 Word Select / LRCK (PIO Input) |
| **I2C SDA** | GPIO 12 | Si5351a Synthesizer I2C Data |
| **I2C SCL** | GPIO 13 | Si5351a Synthesizer I2C Clock |
| **MODE M0** | GPIO 22 | PCM1808 MD0 (Held LOW for I2S format) |
| **MODE M1** | GPIO 26 | PCM1808 MD1 (0 = 48 kHz, 1 = 96 kHz) |
| **Si5351 CLK2** | SCKI | 24.576 MHz Master Clock to PCM1808 |
| **Si5351 CLK0/1** | LO I/Q | Direct Quadrature LO to QSD Mixer |

---

## 4. Configuring WiFi Credentials (`wifi_config.h`)

The Raspberry Pi Pico W uses the on-board CYW43439 radio to connect to your local 2.4 GHz WiFi network in Station (STA) mode and stream UDP I/Q data via OpenHPSDR Protocol 1.

### Setting Your Network Credentials
Open `firmware/wifi_config.h` in your editor before compiling:

```c
#ifndef WIFI_CONFIG_H
#define WIFI_CONFIG_H

// Replace with your 2.4 GHz WiFi network name and password:
#define DEFAULT_WIFI_SSID       "YourWiFiNetworkName"
#define DEFAULT_WIFI_PASSWORD   "YourWiFiPassword"

// Optional TCP headless control port (default: 5000)
#define TCP_CONTROL_PORT        5000

#endif // WIFI_CONFIG_H
```

> **Note on Open Networks (No Password)**: If connecting to an open / unencrypted network, leave `DEFAULT_WIFI_PASSWORD` as `""`.
>
> **Dynamic Fallback**: If WiFi is disconnected or credentials are not yet configured, the Pico W **still operates fully via USB** (UAC1 24-bit audio device + USB CDC serial port `/dev/ttyACM0`).

---

## 5. How to Build & Flash `.uf2`

### Prerequisites (Ubuntu/Debian)
```bash
sudo apt update
sudo apt install -y gcc-arm-none-eabi libnewlib-arm-none-eabi libstdc++-arm-none-eabi-newlib build-essential cmake git
```

### Build Commands
```bash
# 1. Clone TinyUSB if needed
if [ ! -d "$HOME/tinyusb" ]; then
    git clone https://github.com/hathach/tinyusb "$HOME/tinyusb"
fi

# 2. Edit WiFi credentials in firmware/wifi_config.h (see Section 4 above)

# 3. Build the UF2 binary
cd firmware
mkdir -p build && cd build
export PICO_SDK_PATH=/path/to/pico-sdk
export PICO_TINYUSB_PATH=$HOME/tinyusb

cmake -DPICO_BOARD=pico_w ..
make -j$(nproc)
```

Flash `sdr_pico_w_unified.uf2` by holding the **BOOTSEL** button on the Pico W while connecting the USB cable, then drag-and-drop the file into the `RPI-RP2` drive.

---

## 6. Verification Test Program (`test_pico_w_openhpsdr.py`)

A standalone Python verification script is included to test the network link without needing full SDR software open.

### Running the Test
```bash
# 1. Automatic network discovery and test:
python3 test_pico_w_openhpsdr.py

# 2. Or specify frequency and IP explicitly:
python3 test_pico_w_openhpsdr.py --ip 192.168.1.150 --freq 7050000 --rate 48000 --seconds 10
```

### Expected Output
```
[*] Sending OpenHPSDR discovery probe to 255.255.255.255:1024...
[+] Discovery Successful from 192.168.1.150:1024!
    - Board:    Hermes (Pico W)
    - MAC:      28:CD:C1:XX:XX:XX
    - Firmware: v3.3
[*] Sending C&C tune command: 7.050000 MHz (7050000 Hz, 48000 SPS)...
[*] Sending START streaming command (0xEFFE 0x04 0x01)...
[*] Streaming live 24-bit I/Q audio for 10.0 seconds...

  Elapsed |  Packets |  Lost | Rate (KB/s) |   Max Ampl | RMS (dBFS)
--------------------------------------------------------------------
    1.00s |      380 |     0 |     384.2 KB/s |     124800 |   -36.4 dB
    2.00s |      760 |     0 |     384.1 KB/s |     189200 |   -34.8 dB
    ...

==================================================
VERIFICATION TEST SUMMARY
==================================================
Target Pico W IP:      192.168.1.150
Tuned Frequency:       7.050000 MHz
Packets Received:      3800
Packets Dropped:       0 (0.00%)
Total Samples (I/Q):   478800
Throughput:            384.1 KB/s

[SUCCESS] OpenHPSDR Protocol 1 link on Pico W is verified and operational!
```

---

## 7. Using with Client Software

### SDR++ (WiFi)
1. Open **SDR++**.
2. Set **Source** to `OpenHPSDR`.
3. Click **Discover** (the Pico W appears).
4. Select `48000` or `96000` and click **Play**.

### Quisk (USB or WiFi)
- **USB Mode**: Set configuration file to `quisk_conf_unified.py` (captures ALSA `hw:S2026,0` and sends `FREQ,<hz>` commands over `/dev/ttyACM0`).
- **WiFi Mode**: Select the `OpenHPSDR` hardware module in Quisk.

---

## 8. Serial & TCP Command Reference

The firmware accepts ASCII commands over both the **USB CDC Serial Port** (`/dev/ttyACM0` at any baud rate) and the **Headless TCP Control Server** (Port 5000):

| Command | Response | Description |
| :--- | :--- | :--- |
| `WIFI?` | `WIFI,<STATUS>,IP:<ip>,SSID:<ssid>\r\nOK\r\n` | Queries WiFi link state (`CONNECTED`, `JOINING`, `NO_IP`, `DOWN`) and current IP |
| `WIFI,<ssid>,<pass>` | `WIFI,CONNECTING,<ssid>\r\nOK\r\n` | Dynamically updates WiFi credentials and initiates live connection |
| `FREQ,<hz>` | `<actual_hz>\r\nOK,<type>,<offset>\r\n` | Tunes LO using on-chip Golden Integer algorithm (e.g. `FREQ,7050000`) |
| `FREQ,` | `<last_hz>\r\nOK,<type>,0\r\n` | Queries the currently tuned LO frequency |
| `RATE,<48000\|96000>` | `RATE,<rate>\r\nOK\r\n` | Reconfigures PCM1808 hardware pins & PIO sample rate |
| `LOMODE,<BEST\|MID\|WORST\|FRAC>` | `OK\r\n` | Selects LO integer vs fractional spur-rejection tier |
| `VER` | `VER,SDR PCM1808 WiFi/USB 3.3\r\nOK\r\n` | Returns firmware identifier and version |
| `XTAL` | `XTAL,25000000\r\nOK\r\n` | Returns Si5351 reference crystal frequency (25 MHz) |
| `MODE` | `MODE,DIRECT\r\nOK\r\n` | Reports QSD direct quadrature vs Johnson counter mode |

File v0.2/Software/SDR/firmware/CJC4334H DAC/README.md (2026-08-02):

# CJC4334H DAC & PAM8908 Headphone Amplifier Firmware Test

Firmware test suite written with the Raspberry Pi Pico SDK for testing the **CJC4334H I2S Audio DAC** and **PAM8908 Headphone Amplifier** circuit on the Intro-to-CAD-2026 board (YD-RP2040).

---

## Hardware Configuration & Pinout

| Signal | RP2040 Pin | Hardware Connection / Notes |
| :--- | :--- | :--- |
| **I2S SCK (BCLK)** | `GP16` | Bit Clock input to CJC4334H (JP34 bridged) |
| **I2S WS (LRCK)** | `GP17` | Word Select / Frame Clock to CJC4334H (JP33 bridged) |
| **I2S SD (DOUT)** | `GP18` | Serial Data input to CJC4334H (JP32 bridged) |
| **MCLK** | `24.576 MHz` | **Default**: Onboard 24.576 MHz crystal oscillator via JP6 (Pins 1-2 bridged) |
| **Optional MCLK** | `GP15` | Software PWM MCLK generator if jumper swapped to `GP15` (JP6 Pins 2-3) |
| **Audio Output** | `J9 Jack` | 3.5mm Headphone Jack driven by PAM8908 stereo amplifier |

---

## Technical Features

1. **Strict 64fs I2S Timing (`i2s_tx.pio`)**:
   - Zero-overhead 128-cycle PIO state machine (64 cycles Left, 64 cycles Right).
   - 100% symmetric 50.0% duty cycle SCLK ($t_{\text{high}} = t_{\text{low}}$).
   - 1-bit I2S frame delay per standard I2S protocol.

2. **Continuous Zero-Gap Hardware DMA Ping-Pong Streaming**:
   - Dual-channel chained DMA buffers (`dma_chan_a` and `dma_chan_b`).
   - Hardware IRQ refilling background buffer during active playback (**0 nanoseconds gap**).
   - Continuous phase Direct Digital Synthesis (DDS) preventing pops, clicks, or 0.5ms buffer dropouts.

3. **Cubic Perceptual Volume Control**:
   - Master volume scaled via $(\text{Volume \%})^3$ to provide fine, comfortable listening levels on the capless PAM8908 headphone amplifier.
   - Default volume set to a clean, comfortable **5%**.

---

## Building the Firmware

Ensure the Raspberry Pi Pico SDK is installed and `PICO_SDK_PATH` is set in your environment.

```bash
cd "v0.2/Software/SDR/firmware/CJC4334H DAC"
mkdir -p build
cd build
cmake ..
make -j8
```

This generates `cjc4334h_dac_test.uf2` in the `build/` directory.

---

## Flashing to YD-RP2040

1. Hold down the **BOOTSEL** button on the YD-RP2040 board while connecting it via USB.
2. Copy `cjc4334h_dac_test.uf2` to the `RPI-RP2` drive.
3. The board will automatically reboot and execute the firmware (onboard LED will blink a 500ms heartbeat).

---

## Interactive USB Terminal Controls

Open a serial terminal connected to the YD-RP2040 USB port (e.g. `minicom -D /dev/ttyACM0` or VSCode Serial Monitor at 115200 baud).

### Interactive Menu Commands:
- `1` : Select **1 kHz Stereo Sine Wave** (Default test tone).
- `2` : Select **Stereo L/R Channel Separation Test** (440 Hz Left / 880 Hz Right alternating every second).
- `3` : Select **Logarithmic Frequency Sweep** (20 Hz to 20 kHz continuous sweep).
- `4` : Select **Polyphonic A-Major Chord** (440 Hz + 554.37 Hz + 659.25 Hz triad).
- `5` : **Mute / Silence** output.
- `+` / `-` : Fine volume adjustment (**+1% / -1%**).
- `*` / `/` : Coarse volume adjustment (**+5% / -5%**).
- `f` / `F` : Increase / Decrease base sine wave frequency (**+50 Hz / -50 Hz**).
- `m` : Toggle GP15 MCLK PWM output ON / OFF.
- `h` : Redisplay interactive menu.

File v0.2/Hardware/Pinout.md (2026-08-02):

### Intro-to-CAD-2026 (v0.2) - Pico/YD-RP2040 Pinout

| Pin | RP2040 Pin Name | Signal (Net Name) | Target Peripheral (Deduced) |
|:---:|:---|:---|:---|
| **1** | GP0 | `/MISO` | MicroSD Card Slot (SPI MISO) |
| **2** | GP1 | `/CS` | MicroSD Card Slot (SPI Chip Select) |
| **3** | GND | `GND` | Ground |
| **4** | GP2 | `/SPI_CK` | MicroSD Card Slot (SPI Clock) |
| **5** | GP3 | `/MOSI` | MicroSD Card Slot (SPI MOSI) |
| **6** | GP4 | `/SD_CD` | MicroSD Card Slot (Card Detect) |
| **7** | GP5 | `/SW_C` | Rotary Encoder (Push Button Switch) |
| **8** | GND | `GND` | Ground |
| **9** | GP6 | `/SD2` | Audio ADC/DAC (I2S Data 2) |
| **10** | GP7 | `/BCK2` | Audio ADC/DAC (I2S Bit Clock 2) |
| **11** | GP8 | `/WS2` | Audio ADC/DAC (I2S Word Select 2) |
| **12** | GP9 | `/DATA` | Audio ADC/DAC (I2S Data) |
| **13** | GND | `GND` | Ground |
| **14** | GP10 | `/BCK` | Audio ADC/DAC (I2S Bit Clock) |
| **15** | GP11 | `/WS` | Audio ADC/DAC (I2S Word Select) |
| **16** | GP12 | `/OSC_SDA` | Si5351a Clock Generator (I2C SDA) |
| **17** | GP13 | `/OSC_SCL` | Si5351a Clock Generator (I2C SCL) |
| **18** | GND | `GND` | Ground |
| **19** | GP14 | `/BTN` | Tactile Push Button (S2) |
| **20** | GP15 | `/PICO_MCLK` | Master Clock (I2S/Audio Clock) |
| **21** | GP16 | `/SCLK` | Audio DAC U1 (I2S Serial Clock) |
| **22** | GP17 | `/LRCK` | Audio DAC U1 (I2S Left/Right Clock) |
| **23** | GND | `GND` | Ground |
| **24** | GP18 | `/SDIN` | Audio DAC U1 (I2S Data In) |
| **25** | GP19 | `/RGB_DIN` | WS2812/SK6812 RGB LEDs (Data In) |
| **26** | GP20 | `/ANG_B` | Rotary Encoder (Channel B) |
| **27** | GP21 | `/ANG_A` | Rotary Encoder (Channel A) |
| **28** | GND | `GND` | Ground |
| **29** | GP22 | `/TRIG` | Ultrasonic Sensor J6 (Trigger) |
| **30** | RUN | `/Raspberry_Pi_Pico/RST` | Reset Switch (S1) |
| **31** | GP26 (A0) | `/ECHO` | Ultrasonic Sensor J6 (Echo) |
| **32** | GP27 (A1) | `/INA` | Motor Driver U10 (Input A) |
| **33** | GND (AGND)| `GND` | Ground |
| **34** | GP28 (A2) | `/INB` | Motor Driver U10 (Input B) |
| **35** | ADC_VREF | *Unconnected (NC)* | *(Routed to header J3 but no active signal)* |
| **36** | 3V3_OUT | `+3.3V` | 3.3V Board Power Bus |
| **37** | 3V3_EN | *Unconnected (NC)* | *(Routed to header J3 but no active signal)* |
| **38** | GND | `GND` | Ground |
| **39** | VSYS | `+4.7V` | Main Input / VSYS Power Bus |
| **40** | VBUS | `+4.7V` | Tied to 4.7V Bus |

### A Few Notes For Your Code:
* **MicroSD SPI Bus**: Uses `SPI0` on the Pico (GP0, GP2, GP3) with GP1 as the CS pin.
* **I2C Bus**: The Si5351a generator sits on `I2C0` (GP12 = SDA, GP13 = SCL).
* **Audio (I2S)**: You have a few different I2S devices split across the pins. A main I2S DAC uses pins GP16 (SCK), GP17 (WS/LRCK), and GP18 (SD). Other ADCs/DACs use the GP6-GP11 block. 
* **Rotary Encoder**: Make sure to enable internal pull-ups in your code for `/SW_C` (GP5), `/ANG_A` (GP21), and `/ANG_B` (GP20) unless they are hardwired on the board.

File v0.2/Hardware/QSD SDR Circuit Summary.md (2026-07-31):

# Technical Design Summary: High-Sensitivity Parallel Summation QSD SDR

## 1. Project Overview
This design is a high-performance Direct Conversion Software Defined Radio (SDR) front-end optimized for the HF spectrum (3.5 MHz – 30 MHz). The primary design goal was to achieve a sensitivity of **0.1 µV** while maintaining superior image rejection and a ultra-low noise floor, suitable for weak-signal reception in crowded amateur radio bands.

## 2. RF Front-End & Mixing
### Architecture: Balanced Parallel Summation
*   **Transformer:** A center-tapped 1:1+1 (or 1:2 depending on jumper configurations) transformer (**H1102NLT**) provides galvanic isolation and produces balanced anti-phase signals ($0^\circ$ and $180^\circ$).
*   **Mixer:** The **SN74CBT3253** high-speed bus switch acts as a Tayloe Mixer. Unlike standard designs that use *separate* capacitors, this design employs a **Parallel Current Summation** technique. Each I/Q channel samples the transformer twice per cycle, effectively doubling the sampling duty cycle to 50%. This increases the conversion gain and energy collection efficiency.
*   **Sampling Capacitors:** **10 nF C0G (NP0)** capacitors were selected. While simulation showed 1 nF allowed for faster tracking, 10 nF was chosen for the final design to provide:
    1.  **Superior Image Rejection:** 10 nF "swamps" out tiny parasitic PCB and switch capacitances.
    2.  **Built-in Anti-Aliasing:** In combination with the $100\Omega$ effective source resistance, it creates a hardware cutoff at **159 kHz**, perfectly protecting the 96 kHz sample rate.
    3.  **Linearity:** C0G material is mandatory to prevent the voltage-coefficient distortion inherent in X7R types, which would otherwise destroy quadrature balance.

## 3. Analog Baseband (The "Buffer-First" Strategy)
### Topology: 2-Op-Amp Instrumentation Amplifier
To solve the "coupling" issue found in standard inverting-amplifier SDRs (where sampling capacitors drain into the gain resistors), this design uses two **OPA1612** dual packages.
*   **High-Impedance Buffering:** Each of the four mixer outputs ($0^\circ, 90^\circ, 180^\circ, 270^\circ$) feeds directly into a non-inverting op-amp input. This ensures the sampling capacitors "hold" their peak voltage without being loaded, preserving perfect 90° phase separation even at 30 MHz.
*   **Symmetry:** Signal Path A is buffered at unity gain, while Path B performs the subtraction and provides the primary system gain (**~ 430x**). This gain was intentionally reduced from the original 1300x to provide an extra **10 dB of dynamic range headroom**, preventing the ADC from clipping on strong nearby signals.
*   **Stability:** $10\Omega$ resistors are placed at the op-amp inputs to prevent parasitic VHF oscillations, while $100\text{ pF}$ feedback capacitors provide a secondary $150\text{ kHz}$ low-pass filter.

## 4. Clocking and Frequency Control
*   **Unified Reference:** A single **24.576 MHz CMOS Oscillator** drives the entire system.
*   **Synchronization:** The oscillator feeds both the **MS5351M** Local Oscillator and the **PCM1808 ADC** (Master Mode). This ensures that the RF mixing and digital sampling are frequency-locked, eliminating the "frequency crawl" seen in dual-clock designs.
*   **Signal Integrity:** **33$\Omega$ star-termination resistors** are used at the oscillator and the Si5351 outputs. These resistors dampen reflections and "soften" square-wave edges, reducing harmonic RFI that could desensitize the 0.1 µV front-end.

## 5. Power and Grounding
*   **Dual-Rail Supply:** The system runs on a bipolar **+/- 2.25V** rail. This allows the signal path to be centered at **0V (GNDA)**, maximizing headroom and simplifying the interface between the mixer and the ADC.
*   **SGM2205 Analog Regulator:** A 20V-rated LDO steps down the input to a clean 4.5V. It utilizes a **100 nF Feed-Forward capacitor ($C_{ff}$)** to achieve a near-silent noise floor at audio frequencies.
*   **Filtering Bank:** The analog supply features a **1$\Omega$ series resistor** followed by **300 µF to 500 µF of Tantalum capacitance**. This "Brute Force" filter acts as a local battery, swallowing switching noise from the Pi Pico.
*   **Power Protection:** A **PMOSFET-based "Ideal Diode"** circuit automatically detects the external 12V supply. It prioritizes the clean 12V rail when plugged in but falls back to USB power with **zero voltage drop**, ensuring the 4.5V regulator always has enough headroom to function.

## 6. Layout Philosophy
*   **Star Grounding:** Analog and Digital grounds are kept distinct on the schematic, but the PCB (a 4-layer stackup) is a solid plane on layer two, as was advised by the AI, where is said this was the most recent best practice.
*   **RF Isolation:** The high-speed 24 MHz clock traces are kept strictly on the top layer, away from the OPA1612 inputs, and are routed with matched lengths for the I and Q paths to preserve quadrature.
*   **DC Blocking:** 100 nF input capacitors protect the mixer, while **1 µF - 10 µF Tantalum** capacitors provide snappy DC-settling times at the output, preventing the "waterfall thump" during frequency changes.
*   The I and Q channels are kept as symmetrical and identical as possible, with trace length matching on the PCB.

## Further Information
* There are LTSpice simulations in the Frohne/Docs/ folder, and a README.md with a different description of this receiver.

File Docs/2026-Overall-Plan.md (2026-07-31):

# Overall Plan for the Intro-to-CAD-2026 Board
The 2026 board is a prototype receiver and we would like this to enable a new version of the SDR-TRX.
## Things We Have Now
* USB Commands
* SDR appears as a sound card for 48 kHz and 96 kHz
* A good hardware design
* A platform that allows us to figure out what frequencies for the Si5351a have spurs, noise, etc.

## Possible Things to Add and Figure Out
* What to do when?
* Does it make sense to have them all available at once?
* Commands to switch between different modes 
* WiFi Connection so we don't need a USB connection but we are using a PC SDR software
	- What protocol for WiFi?
	- What SDR Software?
		- Quisk
		- SDR++
		- Soapy
		- OpenWebRX+
			+ Does OpenWebRX+ allow transmitting?
	* What new commands are needed for WiFi?
	* We need to make WiFi work and run it on clean DC and compare spurs to USB.
* Local Only
	* OLED interference
	* DSP
	* What to display
	* Digital Decoding
		- FT8
		- FT4
		- WSPR
		- etc.
	* Use the DAC?
+ Phasing Multiple Receivers using one Si5351a
	* Using the JLCPCB 5 board order
	* All on one board
+ Creating a receiver that could monitor multiple bands at once
	* Using the JLCPCB 5 board order
	* All on one board

## Specific Questions to Answer
* Does SoapySDR have a Protocol for UDP transfer we could easily use for WiFi?
* What are the advantages and disadvantages of using a SoapySDR protocol for WiFi as opposed to a custom one or whatever our other options are?
	- What are our other options for the I/Q protocol?
* What embedded software is there:
	* For DSP?
	* Which would allow sending and sending/receiving FT8 and other digital protocols?
	* Should we use the DAC?

## Paper on the Image Rejection and Spur Reduction of the QSD SDR
* What theories can we come up with to explain the image rejection improvements?
	* It seems that it is a second order effect caused by the non-ideal op amps and the low impedance of the inverting inputs.  It seems that matched components does not guarantee us perfect image rejection without ideal op amps.
		- Why?
	* What simulations can we do to verify the theories?
* Do we do one or two papers?
* Where do we publish them
## Assymmetry with the Softrock Tayloe Detector
When the impedance is low, the second switch (90 degrees late) has an unsymmetry that ruins the image rejection when you only use two of the four outputs (regardless of the transformer recharging the capacitors).  If the switches were perfect this would be okay, but they probably are not.  If I change Vt to 0.5 the results are bad.  If I change it to 0.99 it looks pretty good.  If I change the amplifiers to high input impedance all is okay too.  Look at the softrock to see what it looks like.  Then look at the switches to see if the switch model is realistic.  Using both sides of the transformer and high Z gives 2.99 mV vs using only one side of the tronsformer and inverting inputs gives 1.16 mV peak to peak.

## Ideas for QSD SDR Receiver Hints Paper
* Use buffer amplifiers for good sampling voltage waveforms and image rejection.
* Be careful of cutoff frequencies anywhere in your passband.  The high frequencies near the cutoff will show more disturbance to the image rejection.
* Program the Si5351a using integer dividers.
* Use 1% components (probably less important)
* Use low noise op amps
* Don't use large resistors that add noise
* Make sure your switches can switch quickly enough
* Match the length of I_LO and Q_LO
* How to calculate cutoff frequencies
* Design filter for high Z output impedance and 50 Ohm input impedance
* Could you figure out a way to sum voltages on the sampling capacitors?
	- Maybe use transformers on the outputs?  Check this out in LTspice.
* Use 4:1 switches for BPF.
* Use PCM1808 instead of cheap sound card or CJC5340
	- Measure R-L vs R+L to characterize sound card
	- Look at the noise output of the sound card or ADC as a function of frequency to make sure spectral display looks good.
* Be careful to eliminate ground loops.
* Be very careful to make sure USB power is well filtered for both 4.5V and 3.3 clean voltage.
	- Put an option for running on a clean 12V power supply.
* Bypass all ICs and VA/2 well.
* Use a switched 3.5 mm jack so when you connect to it, you disconnect the SDR.
* Use a separate 24.576 MHz crystal for the PCM1808 and Si5351a.
* Use AI to review your design and to discuss it with an "expert"
* Think about the mechanical issues.  
* Include datasheets in Kicad schematic.
* Use CDFER JLCPCB library if you are getting it built.
* Put in the 3D parts and make the silkscreen perfect.
* If in doubt, make it so you can try both ways using jumpers.

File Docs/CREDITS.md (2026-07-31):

# Credits — Intro to CAD 2026 board modules

The final board was assembled by merging student (and instructor) KiCad modules
from the Intro to CAD course. Those module projects are **historical**; the
merged design lives under `v0.1/Hardware` and `v0.2/Hardware`.

Full module trees are preserved in git history at tag `archive/pre-version-split`
(paths `Module_*` and `Frohne/` at the repository root on that tag).

| Module folder | Notes |
|---|---|
| `Module_Andre` | Student module (Andre) |
| `Module_Andre_old` | Earlier revision of Andre's module |
| `Module_JaronGarbi` | Student module (Jaron Garbi) |
| `Module_Joshua` | Student module (Joshua) |
| `Module_KyleS` | Student module (Kyle S); SD-card footprints retained under `Hardware/libs/Sd-card` |
| `Module_Micah` | Student module (Micah) |
| `Module_Template` | Starter template for student modules |
| `Frohne` | Instructor module (Rob Frohne); library pieces remain under each version's `Hardware/Frohne/` because the merged board still references those symbols/footprints |

To restore a full historical module tree:

```bash
git checkout archive/pre-version-split -- Module_Andre
```

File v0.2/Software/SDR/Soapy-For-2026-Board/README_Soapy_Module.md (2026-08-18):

# WWU 2026 SDR - SoapySDR Module

This repository contains the SoapySDR driver for the **WWU 2026 SDR Board** (v0.1 and v0.2). 

The WWU 2026 SDR is a custom hardware design utilizing an RP2040 (Raspberry Pi Pico) for control, a Si5351a for the Local Oscillator (LO), and a PCM1808 stereo 24-bit ADC for I/Q audio capture.

This driver bridges the USB CDC (Serial) control protocol and the UAC1 (USB Audio Class 1) data stream into a unified `SoapySDR::Device`, allowing the hardware to be used with standard SDR applications like SDR++, GNU Radio, and custom C++/Python scripts.

## Features

* **Si5351a Phase Noise Optimization:** The driver automatically searches for Integer (Golden) PLL multipliers to ensure the cleanest possible LO signal with minimal spurious emissions (see below).
* **Direct ALSA Capture:** Uses `miniaudio` to bypass the Linux PipeWire/PulseAudio servers, ensuring direct access to the `hw:` ALSA device. This prevents unauthorized OS-level resampling and guarantees a bit-perfect 24-bit stream.
* **Dual Mixer Modes:** Supports both `DIRECT` (1x LO) and `JOHNSON` (4x LO) mixer modes, with auto-switching based on frequency (v0.2 firmware).
* **Multi-Platform:** Built-in serial port enumeration supports Linux (`ttyACM*`), macOS (`cu.usbmodem*`), and Windows (`COM*`).
* **High-Speed Ring Buffer:** Internal thread-safe float32 ring buffer prevents sample drops during heavy CPU loads.
* **Optional Manual Si5351 Tuning:** Applications can pass a complete PLL/register solution through `setFrequency()` keyword arguments. This enables a higher-level frequency plan to select known-good integer or low-spur solutions while preserving automatic tuning as the fallback.

## Si5351a Phase Noise Optimization (Integer vs. Fractional)

The Si5351a clock generator uses a PLL multiplier ($M = a + b/c$) to generate the VCO frequency. Using a fractional multiplier ($b > 0$) introduces phase noise and spurious emissions (spurs) into the radio spectrum. Using a pure integer multiplier ($b = 0$) results in a vastly superior, cleaner signal.

When you tune the SDR, the C++ driver host-side performs a mathematical search:
1. **The Integer Search:** It sweeps through all valid output dividers ($N$) to see if the requested frequency can be achieved using a pure integer multiplier ($M = a$). 
2. **The Fractional Fallback:** If an integer match is impossible for the exact requested frequency, the driver calculates the closest rational approximation using a fractional multiplier to guarantee tuning accuracy.

The driver sends the calculated parameters to the RP2040, which configures the Si5351a and responds with a status code indicating which mode was achieved:
* `OK,G,<offset>`: **Golden (Integer)** mode achieved. The LO is operating with minimum phase noise.
* `OK,F,<offset>`: **Fractional** mode used. 

The `offset` indicates any microscopic rounding error (in Hz) between the requested frequency and the actual hardware output.

## Manual Si5351 parameters from applications

The normal path remains automatic: `_computeSi5351()` selects a valid solution for the requested RF frequency. For hardware characterization or a coordinated multi-mode frequency plan, callers may pass all of these keyword arguments to `setFrequency()`:

| Key | Meaning |
|---|---|
| `si5351_hz` | Si5351 output frequency sent to firmware, in Hz |
| `N` | Output divider |
| `a` | Integer PLL multiplier component |
| `b` | Fractional PLL numerator |
| `c` | Fractional PLL denominator |
| `p1`, `p2`, `p3` | Calculated Si5351 register values |

The override is all-or-nothing. If any field is missing, the driver ignores the partial override and uses `_computeSi5351()`. The driver must validate ranges before sending the command: `N`, `a`, `b`, `c`, and the register values must be valid for the active DIRECT or JOHNSON mode, and the resulting VCO must remain within the Si5351 operating range. Invalid values should produce a clear error rather than programming the board.

The Soapy driver implementation requires the following interface change:

```cpp
void _programSi5351(double rfHz, const SoapySDR::Kwargs &args);
```

`setFrequency()` passes its `args` parameter to `_programSi5351()`. `_programSi5351()` checks for the complete key set, converts values with checked integer parsing, and either constructs the `FREQ,...` command from the supplied values or calls `_computeSi5351(rfHz)`.

The harvester's JSON-to-Soapy mapping should be:

```cpp
SoapySDR::Kwargs tuneArgs;
for (const auto &[key, value] : sdr.si5351.items())
    tuneArgs[key] = value.dump();
device->setFrequency(SOAPY_SDR_RX, 0, sdr.centerFreq, tuneArgs);
```

This keeps the JSON frequency plan independent of the driver while allowing the driver to remain the final authority on safety validation. A future frequency-planning tool can populate this block by searching for integer-multiplier (`b = 0`) solutions, checking mixer-mode constraints, and selecting the solution that leaves every requested mode inside the 96 kHz capture window.

## Prerequisites

To compile this driver, you will need the SoapySDR development libraries and a standard C++ build chain.

**On Ubuntu / Debian:**
```bash
sudo apt update
sudo apt install cmake g++ libsoapysdr-dev python3-soapysdr
```

## Building and Installing

1. Clone the repository and navigate to the module directory.
2. Create a build directory and compile using CMake:
```bash
mkdir build
cd build
cmake ..
make -j4
sudo make install
```
3. Update the system library cache (Linux only):
```bash
sudo ldconfig
```

## Verifying the Installation

Plug in your WWU 2026 SDR board. Run the SoapySDR utility command to probe the USB bus:

```bash
SoapySDRUtil --find="driver=2026sdr"
```
You should see output similar to this:
```
Found device 0
  driver = 2026sdr
  label = WWU 2026 SDR (/dev/ttyACM0)
  serial_port = /dev/ttyACM0
  version = 0.2
```

## Running the Test Script

A Python test script is included to verify both the serial LO tuning and the audio data stream. From the root directory, run:

```bash
python3 test_driver.py --freq 7100000 --rate 48000
```
This script will configure the board to 7.1 MHz, capture 0.2 seconds of I/Q data, and calculate the mean power (dBFS) and DC offset. It will also print the `PLL status` so you can verify if the Si5351a achieved a Golden (Integer) lock. A `PASS ✓` at the end indicates the driver is fully functional.

## Advanced Usage (Device Arguments)

When instantiating the device in code (or via applications like SDR++), you can pass optional key-value arguments (`Kwargs`) to override default behaviors. This is particularly useful when using **multiple boards simultaneously**.

| Argument | Description | Default |
| :--- | :--- | :--- |
| `serial_port` | Forces the driver to use a specific serial port (e.g., `/dev/ttyACM1`), skipping auto-discovery. | Auto-discovered |
| `audio_label` | The ALSA card label used to select the correct audio card in `/proc/asound/cards`. Crucial when running multiple boards to ensure the audio stream matches the serial port. When supplied explicitly, a missing label is an error; the driver will not silently fall back to another board. | `"WWU SDR"` |

**Example of explicitly mapping a specific board:**
```cpp
SoapySDR::Kwargs args;
args["driver"] = "2026sdr";
args["serial_port"] = "/dev/ttyACM1";
args["audio_label"] = "S2026_1"; // Maps to ALSA hw:CARD=S2026_1,DEV=0
SoapySDR::Device *sdr = SoapySDR::Device::make(args);
```

## Under the Hood: Firmware Protocol

The driver communicates with the RP2040 firmware via a simple human-readable CDC serial protocol (115200 baud, 8N1):
* `VER` -> returns `VER,<version>`
* `XTAL` -> returns `XTAL,<hz>`
* `RATE,<48000|96000>` -> returns `OK`
* `MODE,<DIRECT|JOHNSON>` -> returns `OK`
* `FREQ,<si5351_hz>,<N>,<a>,<b>,<c>,<P1>,<P2>,<P3>` -> returns `OK,[G|F],<offset>`

The complex Si5351a register math (rational approximation) is handled entirely by the C++ driver host-side, keeping the microcontroller firmware lightweight and highly responsive.
```

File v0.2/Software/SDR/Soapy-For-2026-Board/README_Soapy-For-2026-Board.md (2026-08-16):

# Soapy2026SDR

A native [SoapySDR](https://github.com/pothosware/SoapySDR) module and hardware driver for the **WWU 2026 SDR** (RP2040 / Pico-based Software Defined Radio board).

This driver exposes the board as a standard SoapySDR receiver device, making it compatible with SDR software such as **SDR++**, **GQRX**, **GNU Radio**, and **CubicSDR**.

---

## Hardware Architecture & How It Works

```
                       ┌────────────────────────────────────────┐
                       │           WWU 2026 SDR Board           │
                       │                                        │
[ Antenna ] ──> [ Front End / Mixer ] <── [ Si5351a Clock Gen ] │
                        │                         ▲             │
                     I / Q                        │ I2C         │
                        ▼                         │             │
                [ PCM1808 ADC ]           [ RP2040 MCU ]        │
                        │ (I2S)                   │             │
                        └────────────┬────────────┘             │
                                     │ USB                      │
                       ┌─────────────┴────────────┐             │
                       │  USB Audio   │  USB CDC  │             │
                       └──────┬───────┴─────┬─────┘             │
                              │             │                   │
══════════════════════════════╪═════════════╪═══════════════════╪══════════════════
 HOST COMPUTER                │             │
                              ▼             ▼
                       [ miniaudio ]   [ SerialPort ]
                        (Direct ALSA)   (115200 baud)
                              │             │
                              └──────┬──────┘
                                     ▼
                              [ Soapy2026SDR ]
                                     │
                                     ▼
                              [ SDR++ / GQRX ]
```

### 1. Control Protocol (USB CDC Serial)
* **Discovery:** Scans available serial ports for the RP2040 USB Vendor/Product ID (`0xCAFE:0x4011` or `0xCAFE:0x4010`) and queries the firmware version via `VER`.
* **LO Tuning:** When you change frequency in your SDR software, the driver computes exact PLL MultiSynth parameters ($N, a, b, c, P_1, P_2, P_3$) using rational approximations to match the reference crystal frequency (`XTAL`).
* **Mixer Modes:**
  * **DIRECT Mode (3.8 MHz – 30 MHz):** Si5351a outputs $f_{LO} = f_{RF}$ ($N$ is even, $6 \le N \le 126$).
  * **JOHNSON Counter Mode (500 kHz – 30 MHz, v0.2 firmware):** Si5351a outputs $f_{LO} = 4 \times f_{RF}$ to drive a quadrature Johnson counter ($4 \le N \le 127$). The driver automatically selects this mode below 3.8 MHz.

### 2. Audio & I/Q Baseband Capture (USB Audio)
* **ADC:** The onboard Texas Instruments **PCM1808** captures quadrature baseband signals (Left = I, Right = Q) at 24-bit resolution (`S24_3LE`).
* **ALSA Direct Bypass:** On Linux systems running PipeWire or PulseAudio, standard audio capture can be unintentionally resampled to 48 kHz. `Soapy2026SDR` scans `/proc/asound/cards` to find the hardware card ID (`hw:CARD=...`) and binds directly using `miniaudio` with `noAutoResample = true`.
* **Buffering & Format Conversion:** Unpacks 24-bit PCM samples, normalizes them to float32 values in $[-1.0, +1.0]$, and places them into an internal lock-protected ring buffer (`RING_FRAMES = 131072`) ready for SoapySDR consumption (`SOAPY_SDR_CF32` or `SOAPY_SDR_CS16`).

---

## Dependencies & Prerequisites

### Linux (Ubuntu / Debian / Raspberry Pi OS)
```bash
sudo apt update
sudo apt install -y \
    build-essential \
    cmake \
    git \
    libsoapysdr-dev \
    soapysdr-tools \
    libasound2-dev \
    libudev-dev \
    python3-soapysdr \
    python3-numpy
```

### macOS
```bash
brew install cmake soapysdr
```

---

## Building and Installing

0.  **You can just run the build script, but here is how you do it by hand if you prefer.**

1. **Clone the repository:**
   ```bash
   git clone https://github.com/frohro/Intro-to-CAD-2026
   cd Intro-to-CAD-2026/v0.2/Software/SDR/Soapy-For-2026-Board
   ```

2. **Create a build directory and compile:**
   ```bash
   mkdir build && cd build
   cmake .. -DCMAKE_BUILD_TYPE=Release
   make -j$(nproc)
   ```

3. **Install the SoapySDR module:**
   ```bash
   sudo make install
   sudo ldconfig
   ```

4. **Verify the installation:**
   Ensure the board is plugged into USB, then run:
   ```bash
   SoapySDRUtil --find="driver=2026sdr"
   ```
   You should see output similar to:
   ```text
   ######################################################
   ## Soapy SDR -- Device probe
   ######################################################
   Found WWU 2026 SDR on /dev/ttyACM0 (fw: v0.2-2026)
   ```

5. **Run the functional test:**
   From the project root directory:
   ```bash
   python3 test_driver.py --freq 7100000 --rate 48000
   ```

---

## Using with SDR++

[SDR++](https://github.com/AlexandreRouma/SDRPlusPlus) is a cross-platform SDR receiver application that natively supports SoapySDR input sources.

### Step-by-Step Setup

1. **Launch SDR++:**
   ```bash
   sdrpp
   ```

2. **Select Source:**
   * In the top-left **Source** panel, open the source drop-down menu and select **SoapySDR**.

3. **Select the Device:**
   * In the **Device** drop-down, select **WWU 2026 SDR** (or choose `2026sdr` if manually entering arguments).
   * If it doesn't appear, click the **Refresh** button next to the device list.

4. **Configure Parameters:**
   * **Sample Rate:** Select `48000` (48 kHz) or `96000` (96 kHz).
   * **Antenna:** Keep at `RX`.
   * **Gain:** Fixed (the PCM1808 ADC uses a hardware analog front-end).

5. **Start Receiving:**
   * Click the **Play (▶)** button in the top left.
   * Tune to your desired HF frequency (e.g., `7.100 MHz` for 40m amateur radio band).
   * Choose demodulation (AM, LSB, USB, CW, etc.) and adjust the bandwidth filter in the Radio panel.

---

## Device Settings Reference

The driver exposes hardware parameters accessible through SoapySDR APIs or settings panels:

| Setting Key | Description | Values / Examples |
| :--- | :--- | :--- |
| `firmware_version` | Firmware revision reported by Pico | `v0.1`, `v0.2-2026` |
| `crystal_freq_hz` | Si5351a reference crystal frequency | `24576000.0` |
| `mixer_mode` | Active RF mixing mode | `DIRECT`, `JOHNSON` |
| `pll_status` | Return code of last frequency change | `OK,G,0` (Integer/Golden), `OK,F,0` (Fractional) |

---

## Troubleshooting

* **Permission denied on `/dev/ttyACM*`:**
  Add your Linux user to the `dialout` (or `uucp`) group:
  ```bash
  sudo usermod -a -G dialout $USER
  ```
  *(Log out and back in for changes to apply).*

* **Device not detected by `SoapySDRUtil`:**
  * Check USB connection: `lsusb` should list `16c0:05dc` or `cafe:4011`/`cafe:4010`.
  * Make sure the module was installed to the correct SoapySDR directory (usually `/usr/local/lib/SoapySDR/modules0.8/` or `/usr/lib/x86_64-linux-gnu/SoapySDR/modules0.8/`). You can inspect module search paths using `SoapySDRUtil --info`.

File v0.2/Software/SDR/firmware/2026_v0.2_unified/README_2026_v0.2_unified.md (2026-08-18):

# Intro-to-CAD-2026 v0.2 Unified Pico W SDR Receiver

**Repository**: `Intro-to-CAD-2026`  
**Target Hardware**: Raspberry Pi Pico W (RP2040 + CYW43439), PCM1808 24-bit I2S Stereo ADC, Si5351A Clock Generator / Quadrature LO Synthesizer, Tayloe QSD Mixer.

---

## 1. Project Overview

The **Intro-to-CAD-2026 v0.2 Unified Firmware** is a high-performance, dual-mode Software Defined Radio (SDR) receiver firmware and companion software suite. It supports simultaneous or selectable operation over **High-Speed USB** and **2.4 GHz 802.11n Wi-Fi**:

1. **Wi-Fi Mode (OpenHPSDR Protocol 1 / Hermes)**:
   - Connects to your local Wi-Fi network in Station (STA) mode.
   - Streams 24-bit stereo I/Q audio via standard **OpenHPSDR Protocol 1** over UDP port `1024` at **48,000 SPS** or **96,000 SPS** (1032-byte EP6 frames).
   - Compatible out-of-the-box with **Quisk**, **SDR++**, **Thetis**, **LinHPSDR**, **SparkSDR**, and **GNU Radio**.
   - Supports network Discovery (`0xEFFE 0x02`), Run/Stop (`0xEFFE 0x04`), and In-Band Command & Control (C&C) for RX 0 frequency tuning (Command `0x02`), VFO tuning (Command `0x01`), and sample rate switching (Command `0x00`).
   - Dedicated TCP headless command server on port `5000`.

2. **USB Mode (UAC1 24-bit Audio + CDC Serial Control)**:
   - Enumerates as a standard USB Audio Class 1.0 (UAC1) 24-bit stereo capture device (`S24_3LE`, 48 kHz / 96 kHz).
   - Exposes a USB CDC serial port (`/dev/ttyACM0` on Linux, `COMx` on Windows) for interactive frequency tuning (`FREQ,<hz>`), sample rate control (`RATE,<48000|96000>`), and hardware diagnostics.

---

## 2. System Architecture

```
                       +-------------------------------------------------------------+
                       |                    Raspberry Pi Pico W                      |
                       |                                                             |
+-----------------+    |   +-------------------+              +------------------+   |    USB Type-C
| PCM1808 ADC     |--->|   | Core 1 (Audio VM) |              | Core 0 (Network) |   |===> UAC1 (24-bit 48/96k)
| (I2S Stereo 24b)|    |   | - PIO State Mach  |  FIFO Queue  | - lwIP / CYW43   |   |     USB CDC Control
+-----------------+    |   | - Ping-Pong DMA   |------------->| - TinyUSB UAC1   |   |
                       |   | - Dynamic 48k/96k |              | - On-Chip Si5351 |   |    WiFi (UDP 1024)
+-----------------+    |   +-------------------+              +------------------+   |~~~> OpenHPSDR Protocol 1
| Si5351a Synth   |<---|                                               |             |     (SDR++, Quisk, Thetis)
| (I2C QSD LO)    |----+-----------------------------------------------+             |
+-----------------+                                                                  |
                       +-------------------------------------------------------------+
```

### Dual-Core Allocation
- **Core 1 (Real-Time Audio DSP Pipeline)**:
  - Samples the PCM1808 24-bit ADC via custom RP2040 PIO microcode (`i2s_rx.pio`) on GPIO 9, 10, and 11.
  - Alternates ping-pong DMA buffers with zero CPU jitter.
  - Pushes 32-bit aligned I/Q frames into the lock-free inter-core hardware FIFO.
- **Core 0 (Networking & Protocol Engine)**:
  - Runs the CYW43439 Wi-Fi driver and lwIP network stack in non-blocking event-driven mode.
  - Encapsulates stereo I/Q frames into OpenHPSDR Protocol 1 frames (1032 bytes, EP6).
  - Packs stereo `S24_3LE` audio frames into the TinyUSB isochronous audio endpoint (UAC1).
  - Listens on USB CDC (`/dev/ttyACM0`) and TCP port 5000 for frequency and mode commands.
  - Computes the Golden Integer LO synthesizer algorithm on-chip in ~8 µs upon receiving any frequency command.

---

## 3. Hardware Pinout (Intro-to-CAD-2026 v0.2)

| Signal | Pico W GPIO | Function | Description |
| :--- | :--- | :--- | :--- |
| **I2S DATA** | GPIO 9 | PCM1808 SDOUT (PIO RX) | 24-bit I2S audio stream from ADC |
| **I2S BCK** | GPIO 10 | PCM1808 Bit Clock (PIO Input) | 64 × $F_s$ I2S Bit Clock |
| **I2S WS** | GPIO 11 | PCM1808 Word Select (PIO Input) | $F_s$ Left/Right Frame Clock |
| **I2C SDA** | GPIO 12 | Si5351A I2C Data | Frequency synthesizer control |
| **I2C SCL** | GPIO 13 | Si5351A I2C Clock | Frequency synthesizer control |
| **MODE M0** | GPIO 22 | PCM1808 MD0 | Held LOW for standard I2S format |
| **MODE M1** | GPIO 26 | PCM1808 MD1 | 0 = 48 kHz (256 $F_s$), 1 = 96 kHz (256 $F_s$) |
| **Si5351 CLK2** | SCKI Pin | Master Clock (24.576 MHz) | Master clock fed to PCM1808 ADC |
| **Si5351 CLK0/1** | LO I/Q | Direct Quadrature LO | 0° / 90° LO clocks to QSD mixer |

---

## 4. Directory & File Structure

```
2026_v0.2_unified/
├── CMakeLists.txt              # Pico SDK CMake build configuration
├── pico_sdk_import.cmake       # Pico SDK import helper
├── lwipopts.h                  # lwIP TCP/IP stack configuration for Pico W
├── tusb_config.h               # TinyUSB configuration (UAC1 + CDC)
├── wifi_config.h               # Default Wi-Fi SSID, password, and port settings
├── i2s_rx.pio                  # RP2040 PIO microcode for 24-bit I2S stereo capture
├── main.c                      # Dual-core firmware entry point & system orchestration
├── openhpsdr.c / .h            # OpenHPSDR Protocol 1 network engine (UDP 1024)
├── si5351.c / .h               # Si5351A synthesizer driver & Golden Integer LO engine
├── usb_descriptors.c           # USB descriptors (UAC1 24-bit stereo audio + CDC serial)
├── test_pico_w_openhpsdr.py    # Standalone command-line Wi-Fi OpenHPSDR tester & benchmark
├── debug_hpsdr_tap.py          # Real-time UDP network traffic & C&C packet sniffer
├── quisk_conf_openhpsdr.py     # Quisk configuration for Wi-Fi OpenHPSDR operation
├── quisk_conf_unified.py       # Quisk configuration for USB UAC1 + CDC operation
├── quisk_widgets.py            # Custom Quisk toolbar widgets & band-switch buttons
├── quisk_widgets_picow.py      # Extended Quisk toolbar widgets with status display
└── README_v0.2_unified.md      # Comprehensive technical documentation & user guide
```

---

## 5. Wi-Fi Configuration (`wifi_config.h`)

Edit `wifi_config.h` before building if you want to hardcode your network:

```c
#ifndef WIFI_CONFIG_H
#define WIFI_CONFIG_H

#define DEFAULT_WIFI_SSID       "YourNetworkSSID"
#define DEFAULT_WIFI_PASSWORD   "YourPassword"   // Leave as "" for open networks
#define TCP_CONTROL_PORT        5000

#endif // WIFI_CONFIG_H
```

> **Dynamic Configuration**: Wi-Fi credentials can also be changed dynamically without reflashing by sending `WIFI,<ssid>,<pass>` over the USB CDC serial terminal (`/dev/ttyACM0`) or TCP port 5000.

---

## 6. How to Build and Flash

### Build Requirements
- Raspberry Pi Pico SDK (v1.5.0 or later)
- ARM GNU Toolchain (`arm-none-eabi-gcc`, `arm-none-eabi-newlib`)
- CMake (>= 3.13) & Make
- Hathach TinyUSB submodule

### Compilation
```bash
# Set environment paths
export PICO_SDK_PATH=/path/to/pico-sdk
export PICO_TINYUSB_PATH=/path/to/tinyusb

# Build UF2 binary
mkdir -p build && cd build
cmake -DPICO_BOARD=pico_w ..
make -j$(nproc)
```

### Flashing
1. Hold down the **BOOTSEL** button on the Pico W while plugging it into USB.
2. The board will mount as a mass-storage drive named `RPI-RP2`.
3. Copy `pico_w_sdr.uf2` into `RPI-RP2`.
4. The Pico W will reboot automatically and begin operation.

---

## 7. Client Software Setup & Quick Start

### A. Wi-Fi Mode with Quisk
Run Quisk using the included OpenHPSDR configuration:
```bash
quisk -c quisk_conf_openhpsdr.py
```
- In Quisk, the radio will connect automatically to the Pico W IP address.
- Click the ham band buttons on the custom toolbar to tune directly to 160m, 80m, 40m, 30m, 20m, 17m, 15m, 12m, or 10m.

### B. USB Mode with Quisk
Run Quisk using the unified USB configuration:
```bash
quisk -c quisk_conf_unified.py
```
- Quisk captures 24-bit audio directly from the Pico W ALSA sound card (`hw:S2026,0`) and controls the hardware LO over USB CDC (`/dev/ttyACM0`).

### C. Wi-Fi Mode with SDR++
1. Open **SDR++**.
2. Select **Source** -> `OpenHPSDR / Hermes`.
3. Click **Discover** (the Pico W will appear with its IP address and Hermes board ID).
4. Select `48000` or `96000` sample rate and click **Play**.

### D. Standalone Command-Line Verification (`test_pico_w_openhpsdr.py`)
To test network discovery, LO tuning, packet reception, throughput, and RMS signal levels without opening full SDR software:
```bash
python3 test_pico_w_openhpsdr.py --ip 192.168.1.186 --freq 7050000 --rate 48000 --seconds 10
```

---

## 8. Serial & TCP Command Reference

Commands can be sent via USB CDC (`/dev/ttyACM0`) or TCP port `5000`:

| Command | Response | Description |
| :--- | :--- | :--- |
| `FREQ,<hz>` | `<actual_hz>\r\nOK,DIRECT,0\r\n` | Tunes Si5351 LO (e.g. `FREQ,7050000`) |
| `FREQ,` | `<last_hz>\r\nOK,DIRECT,0\r\n` | Returns current tuned frequency in Hz |
| `RATE,<48000\|96000>` | `RATE,<rate>\r\nOK\r\n` | Switches PCM1808 hardware pins & PIO sample rate |
| `WIFI?` | `WIFI,<STATUS>,IP:<ip>,SSID:<ssid>\r\nOK\r\n` | Queries Wi-Fi connection status and IP address |
| `WIFI,<ssid>,<pass>` | `WIFI,CONNECTING,<ssid>\r\nOK\r\n` | Connects dynamically to specified Wi-Fi network |
| `VER` | `VER,SDR PCM1808 WiFi/USB 3.3\r\nOK\r\n` | Returns firmware identifier and version |
| `XTAL` | `XTAL,24576000\r\nOK\r\n` | Returns nominal Si5351 master crystal frequency |
| `MODE` | `MODE,DIRECT\r\nOK\r\n` | Reports QSD direct quadrature mode |

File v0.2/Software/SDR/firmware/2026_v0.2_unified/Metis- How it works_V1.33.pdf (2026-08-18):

Metis - How it works

Revisions

Rev | Date | Changes | By
1.0 | 23 Aug 2010 | First draft | VK6APH
1.1 | 13 Sep 2010 | Added Boot loader text | VK6APH
1.2 | 3 Nov 2010 | Changed to current discovery data format | VK6APH
1.3 | 14 Nov 2010 | Added data Start/Stop commands. Replaced ‘Ozy’ with ‘Metis’. | VK6APH
1.4 | 16 Nov 2010 | Added new Discovery data format | VK6APH
1.5 | 18 Nov 2010 | Added DHCP retries | VK6APH
1.6 | 19 Nov 2010 | Added Assign IP data format | VK6APH
1.7 | 22 Nov 2010 | Moved Assign IP to Bootloader. Added read MAC and IP to Bootloader. Updated Bootloader menu. Added static IP indication to LED[6]. | VK6APH
1.8 | 30 Nov 2010 | Added LED[x] to PCB silkscreen layout | VK6APH
1.9 | 6 Dec 2010 | Added Destination Unreachable function. Documented DHCP IP lease renewal process. Added fast/slow flash of LED[0] if not full duplex. | VK6APH
1.10 | 9 Dec 2010 | Added description of inline FPGA code update | VK6APH
1.11 | 12 Dec 2010 | Updated description of LED[6] | VK6APH
1.12 | 13 Dec 2010 | Updated description of inline FPGA code update | VK6APH
1.13 | 14 Dec 2010 | More updated to inline FPGA code update | VK6APH
1.14 | 18 Dec 2010 | Added draft description of JTAG loader | VK6APH
1.15 | 2 Jan 2011 | Added description of JTAG load of HPSDR boards | VK6APH
1.16 | 12 Jan 2011 | Replaced *.pof with *.rbf when programming Metis flash or flash on Penelope, PennyLane or Mercury boards. Updated JTAG file format to *.rbf and operations on file needed before file is sent. Changed protocol so that Metis responds to ‘from port’ of originating PC. | VK6APH
1.17 | 16 Jan 2011 | Metis now always listens on port 1024. Updated protocol. | VK6APH
1.18 | 16 Jan 2011 | Added LED[11] -indicates EPCS16 being erased or programmed. Added warning not to have USB Blaster connected whilst programming. | VK6APH
1.19 | 24 Jan 2011 | Added Bootloader and Metis file merge instructions. | VK6APH
1.20 | 25 Jan 2011 | Corrections to JTAG protocol | VK6APH
1.21 | 1 Feb 2011 | Corrected SVN URL | VK6APH
1.22 | 10 Mar 2011 | Replaced programmer.exe reference with HPSDRProgrammer | VK6APH
1.23 | 26 Mar 2011 | Corrected data format for Bootloader. Clarified that LEDs refer to Mercury board in Bootloader programming example and corrected LED 4 not 7 flashes. | VK6APH
1.24 | 9 April 2011 | Reset sequence number sent by Metis if board idle or Stop received. Do not reset sequence number if a Discovery received. IP address of PC that is to receive data is preserved during Discovery – this enables multiple Metis boards on the same network to be used. Discovery reply indicates if Metis board is running and current software version loaded. Added IP address of DHCP server that provides IP address to DHCP_request. Added raw ADC data for wide bandscope and on/off control. | VK6APH
1.25 | 13 May 2011 | Added independent sequence number to wide bandscope data | VK6APH
1.26 | 1 June 2011 | Added support for Hermes and other hardware to Discovery response. | VK6APH
1.27 | 17 Mar 2012 | Added select EEPROM when combining Bootloader and Metis files | VK6APH
1.28 | 3 Dec 2012 | Corrected starting address of Metis code in EEPROM | VK6APH
1.29 | 31 Dec 2012 | From Metis V2.3 - Added set/read IP address in other than Bootloader mode and wide bandscope data is now 16k words. Added ID for Angelia hardware. | VK6APH
1.30 | 27 Sep 2013 | Corrected set/read IP address protocol in normal mode. | VK6PH
1.31 | 24 May 2014 | Added ID for Orion hardware. | VK6PH
1.32 | 31 Jan 2015 | Corrected broadcast requirements | VK6PH

1.33 | 28 Feb 2015 | Added Hermes Lite hardware designation | VK6PH

LEDS

LED[0] is located at the top of the board and LED[12] at the bottom

D14 = LED[0] - Displays state of PHY negotiations - fast flash if no Ethernet connection, slow flash if 100T, on if 1000T and swap between fast and slow flash if not full duplex
D15 = LED[1] | - Lights when the PHY receives Ethernet traffic
D16 = LED[2] | - Lights when the PHY transmits Ethernet traffic
D17 = LED[3] | - Lights when an Ethernet broadcast is detected
D22 = LED[4] | - Lights when traffic to the boards MAC address is detected
D12 = LED[5] | - Lights when an ARP request is received
LED[6] | - Displays state of DHCP negotiations or static IP - on if DHCP ACK, slow
flash if DHCP NAK, fast flash if DHCP time out and long then short flash if static IP. If DHCP NAK, or time, out an IPIPA IP address will be used.
D13 = LED[7] | - Lights when a ping request is received
D21 = LED[8] | - Lights when an Metis discovery packet is received
D20 = LED[9] | - Lights when an Metis discovery packet reply is sent
D19 = LED[10] | - Lights when 0x7F7F7F received from PC
D18 = LED[11] | - Lights when a receive sequence error is detected or the EPCS16 flash
memory is being erased or programmed. D23 = LED[12] - HEART_BEAT - Flashes once per second

FPGA loaded successfully indicator

A Heartbeat counter, running off the 125MHz clock from the PHY, continually flashes the HEART_BEAT LED once per second. This indicates that the FPGA has code loaded and that the PHY is providing the necessary master clock.

Master Reset

At power on, Tx reset signal (Tx_reset) is set high. This prevents all other code from running other than the Reset and Initialization code. The MAC address of the board is then read from its EEPROM.

The EEPROM is then read to see if a valid IP address is available. If the IP address is 0.0.0.0 or 255.255.255.255 then the Valid_IP flag is not set.

The reset code then reads from PHY Register 31, via the MDIO module, and looks for a 100/1000T, full duplex, connection to a PC or Ethernet Switch. Once found, LED[0] indicates the connect speed and status as follows:

1000T | Steady
100T | Slow flash
Error or no connection | Fast flash
Half duplex connection | Alternate between Fast & Slow flash

Once a valid network connection has been found a delay of one second is applied to allow the network to stabilize.

Main Code

If the Valid_IP flag is set then the board will use this IP address and is ready for further commands. LED[6] will give a long flash followed by a short flash to indicate a static IP address is in use.

If the Valid_IP flag is not set the code then attempts to obtain an IP address via DHCP.

Once an IP address is obtained LED[6] is steady on. If an NAK occurs whilst trying to obtain an IP address then LED[6] flashes slowly.

If a DHCP request is not responded to within 2 second then LED[6] flashes rapidly.

Metis will attempt to obtain an IP address via DHCP for four more times with a two second delay between retries.

If a DHCP provided IP address is successfully received then Metis will use this.

Metis will attempt to renew its DHCP assigned IP address at time equal to the DHCP provided lease time/2. Metis will request a lease renewal directly to the IP address of the DHCP server that issued the original IP address.

If a lease renewal is not received then Metis will try again at lease time * 0.75. The request is sent to the IP address of the original DHCP server. If unsuccessful Metis will broadcast a DHCP Discovery request in an attempt to locate an alternative DHCP server.

At power on, if an IP address is not obtained using DHCP then an APIPA address in the range 169.254.x.x will be assigned. At present the last two bytes are obtained from the last two bytes of the boards MAC address.

ToDo: Change this to a random address in the future and check it’s unique via ARP.

Note: the APIPA IP address is not stored in Flash Memory.

Once an IP address has been obtained, either static, via DHCP or an APIPA address assigned, then the board will respond to Discovery, ARP and ping packets etc.

Metis Discover Packet format

A Metis Discovery packet is sent from a PC in order to determine if Metis boards are present on the network, and if so, how many.

The Discovery packet is a UDP/IP frame sent to MAC address FF:FF:FF:FF:FF:FF and port 1024 of the broadcast address of the local subnets¹
with the following payload:

<0xEFFE><0x02><60 bytes of 0x00>

1
See http://en.wikipedia.org/wiki/Broadcast_address for an explanation as to how to calculate broadcast addresses.

IMPORTANT: This has not currently been implemented. For now Discovery should be sent to an IP address of 255.255.255.255 and port 1024.

Metis Discovery reply format

Upon receipt of this broadcast a Metis board will reply with a UDP/IP frame sent to the ‘from port’ on the IP Address and MAC Address of the PC originating the Discovery broadcast.

The payload of the UDP/IP reply frame is as follows:

<0xEFFE><Status>< Metis MAC Address><Code Version><Board_ID><49 bytes of 0x00>

where

Status | = 1 byte, 0x02 if Metis is not sending data and 0x03 if it is
Metis MAC Address = 6 bytes (MAC Address of the Metis responding to the Discovery Broadcast)
Code Version | = 1 byte, version number of code currently loaded into Metis
Board_ID | = 1 byte, 0x00 = Metis, 0x01 = Hermes, 0x02 = Griffin, 0x04 = Angelia,
| 0x05 = Orion, 0x6 = Hermes_Lite
Note1: The IP address of the Metis board(s) responding can be obtained from the IP header.

Note2: A Metis board will NOT respond to UDP/IP data from a PC SDR program until a valid response to a Discovery Broadcast has been sent to the PC by the Metis board AND a Start command has been received by Metis.

Note3: Metis will respond to the ‘from port’ of the PC that does the Discovery request.

Note4: A Discovery request will be received by multiple Metis boards on the same network. All Metis boards will respond. The Discovery reply Status byte can be read to determine if a Metis board is already sending data to a PC.

Metis will use port 1024 as it’s ‘from port’.

Once a Discovery exchange has taken place the PC may communicate with the Metis board(s) using Start and Stop commands as follows.

Start Command

Metis will start sending UDP/IP data to the ‘from port’, IP address and MAC address of a PC that sends a Start Command. The Start Command is a UDP/IP frame sent to the Ethernet address assigned to the Metis card and port 1024. The command has the following format:

<0xEFFE><0x04><Command>< 60 bytes of 0x00>

where

Command = 1 byte (bit [0] set starts I&Q + Mic data and bit [1] set starts the wide bandscope data)

The ‘from port’, IP address and MAC address of the PC sending the Start Command may be different to that of the PC that sent the Discovery request.

Stop Command

Metis will continue sending data following a Start Command until a Stop Command is received. The Stop Command is a UDP/IP frame sent to the Ethernet address assigned to the Metis card and port 1024. The command has the following format:

<0xEFFE><0x04><Command>< 60 bytes of 0x00>

where

Command = 1 byte (bit [0] clear stops I&Q + Mic data and bit [1] clear stops the wide bandscope data)

Sequence Numbers will be set to zero upon receipt of a Stop Command.
Note: Metis will stop sending if it receives a ‘Destination Unreachable’ packet.

Set IP address

The IP address may be set as follows. First use Discovery to determine the MAC address of the Metis you wish to set the IP address.

Send a Broadcast UDP/IP frame to Port 1024 containing the following:

<0xEFFE>< 0x03>< MAC Address><IP Address to set><60 bytes of 0x00>

Where <MAC Address > is the address of the Metis you wish to set the IP Address, 6 bytes and <IP Address> is the IP address to store in the EEPROM, 4 bytes.

After the Address has been written to EEPROM, which may take a few seconds, Metis will respond to the IP address of the PC that set the IP address and using the set IP address as follows:
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

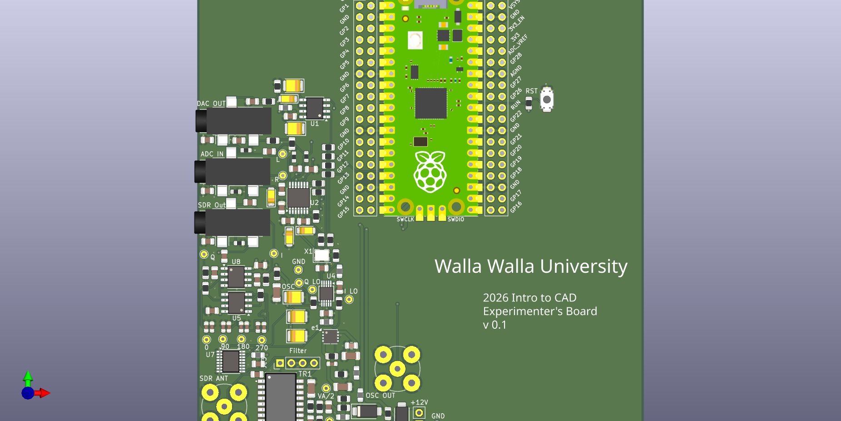
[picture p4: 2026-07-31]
v0.2/Hardware/Intro-to-CAD-2026_floorplan_start.png

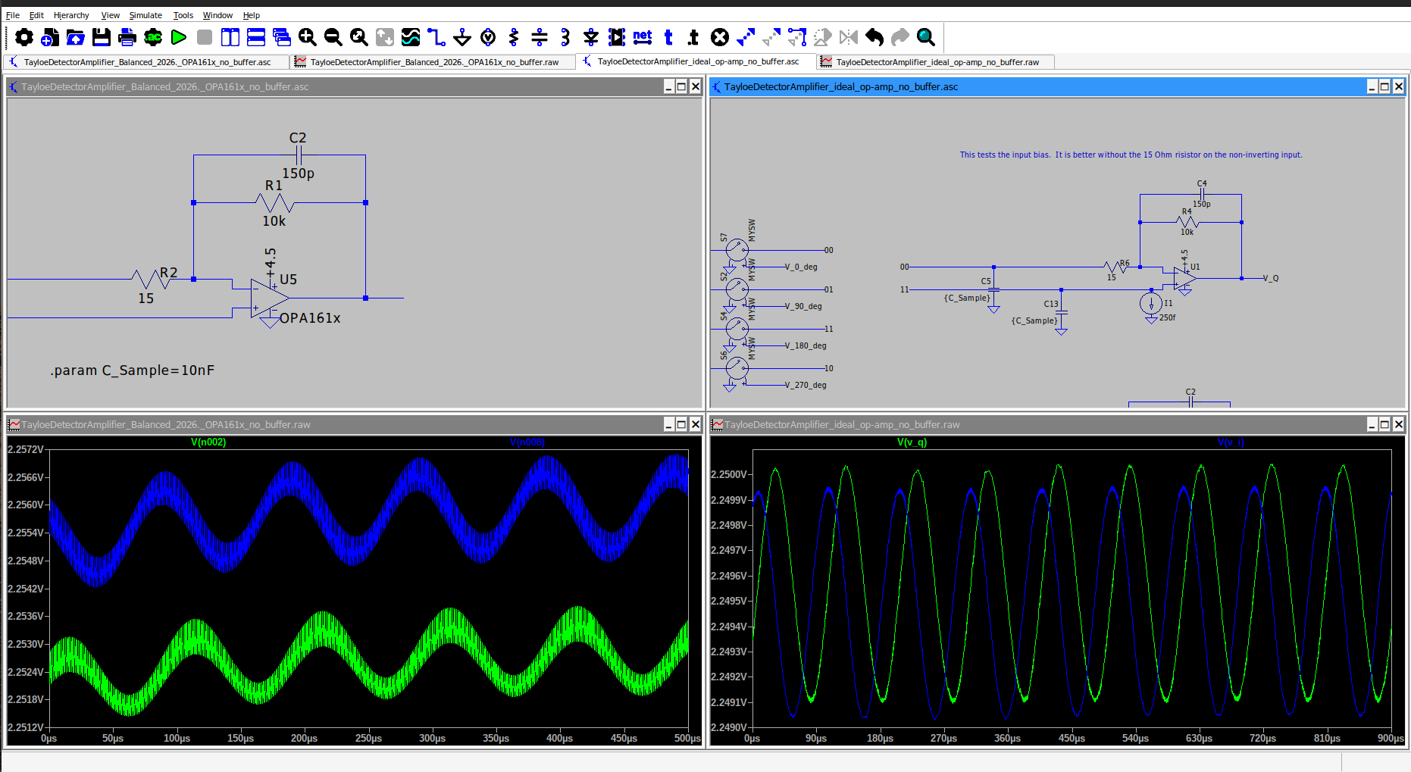
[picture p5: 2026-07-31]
Docs/Ideal-vs-non-ideal_op-amp9.png

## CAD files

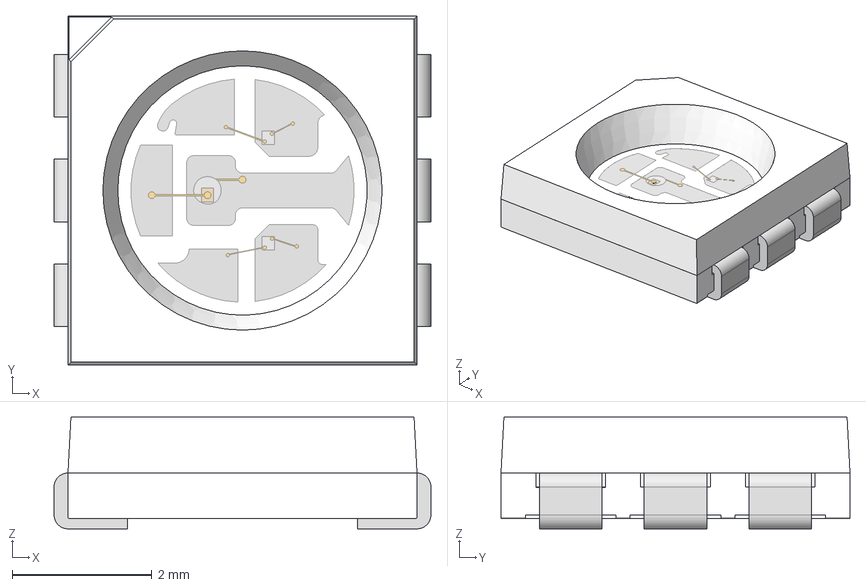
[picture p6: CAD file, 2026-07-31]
v0.2/Hardware/Download_STEP_150505M173300_rev1.stp
5.40 x 5.00 x 1.60 mm
cover
housing
base x 2

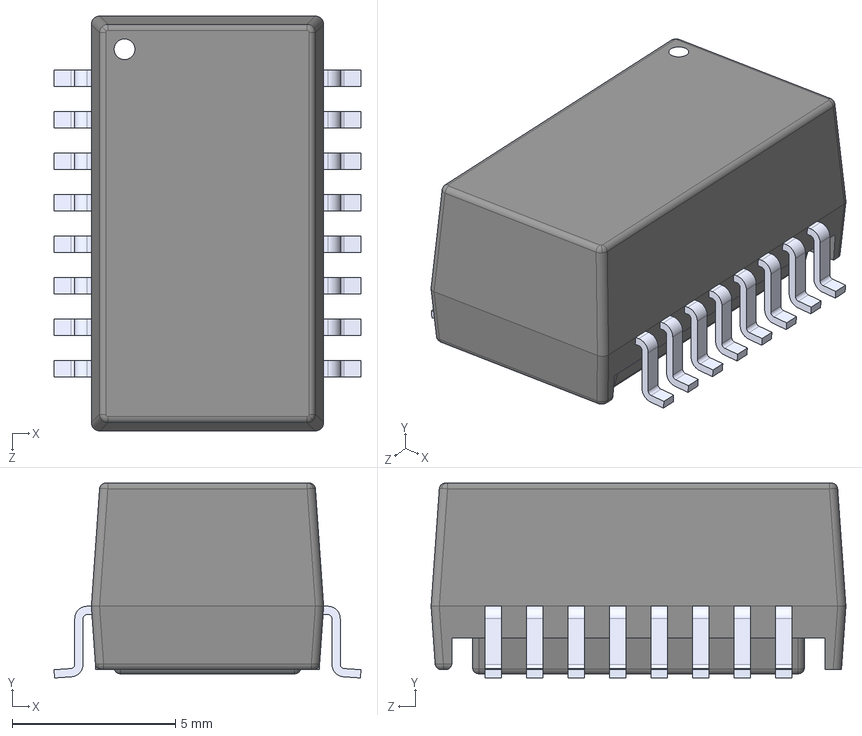
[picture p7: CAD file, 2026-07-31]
v0.2/Hardware/H1102NLT.step
9.40 x 5.97 x 12.7 mm

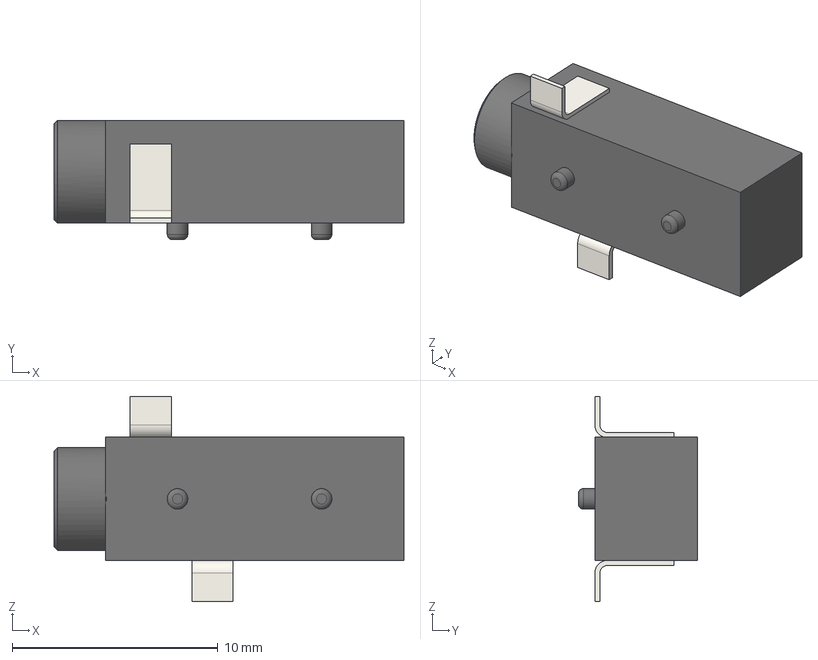
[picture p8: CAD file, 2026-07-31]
v0.2/Hardware/SJ-3523-sj-3524-smt-tr-pi v005.step
17.0 x 5.80 x 9.96 mm
sj-3524-smt-tr-pi v1
sj-3524-smt-tr-pi v002
sj-3524-smt-tr-pi v004

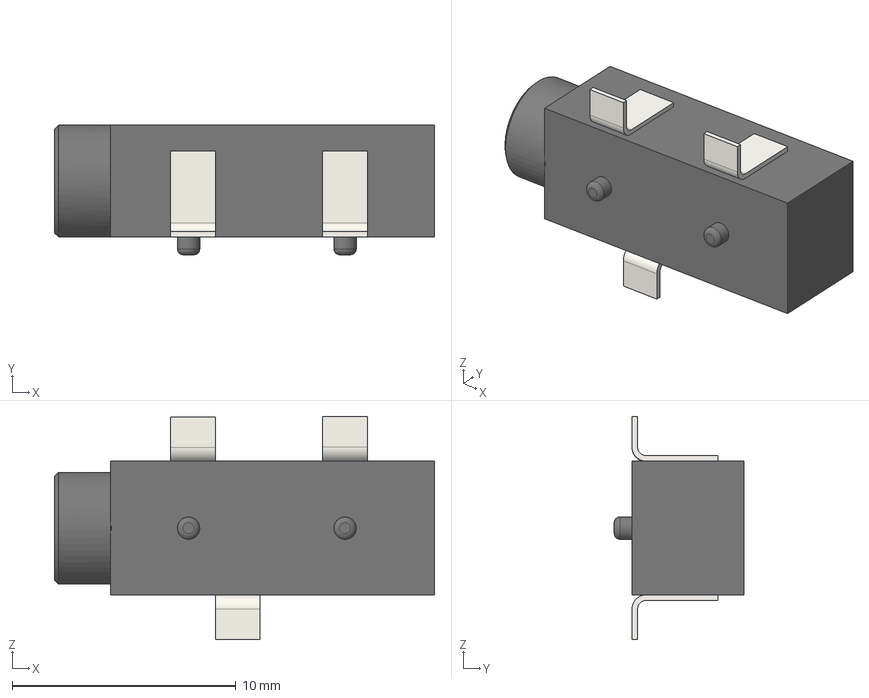
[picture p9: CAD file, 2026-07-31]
v0.2/Hardware/audio_jack.step
17.0 x 5.80 x 9.98 mm
sj-3524-smt-tr-pi v1 x 2
BB x 2
sj-3524-smt-tr-pi v003
sj-3524-smt-tr-pi v004 x 2

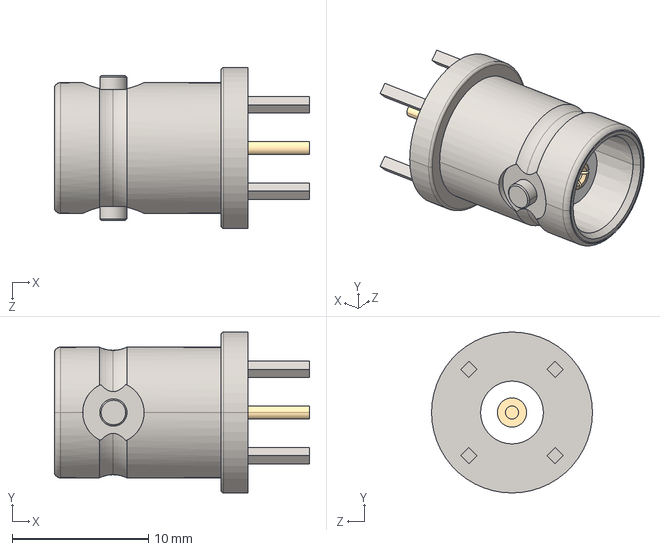
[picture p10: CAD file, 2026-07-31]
v0.2/Hardware/Amphenol RF 122404.STEP
18.7 x 11.8 x 11.8 mm

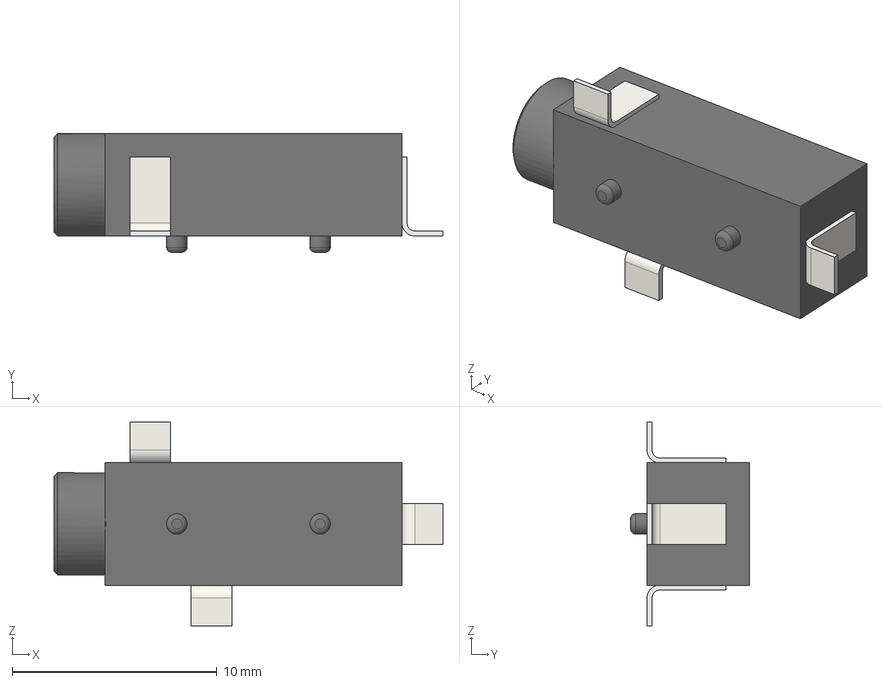
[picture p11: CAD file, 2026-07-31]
v0.2/Hardware/PJ-326.step
19.0 x 5.80 x 9.96 mm

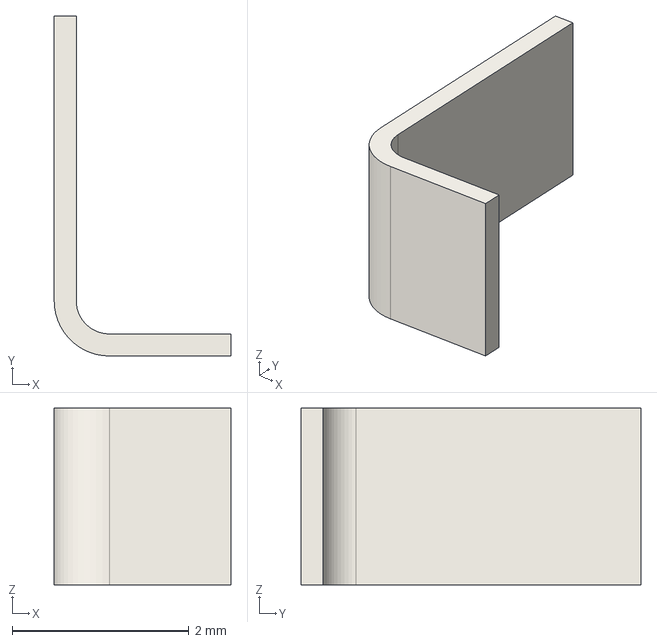
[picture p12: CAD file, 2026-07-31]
v0.2/Hardware/SJ-3523-sj-3524-smt-tr-pi v005sj-3524-smt-tr-pi v003.step
2.00 x 3.85 x 2.00 mm

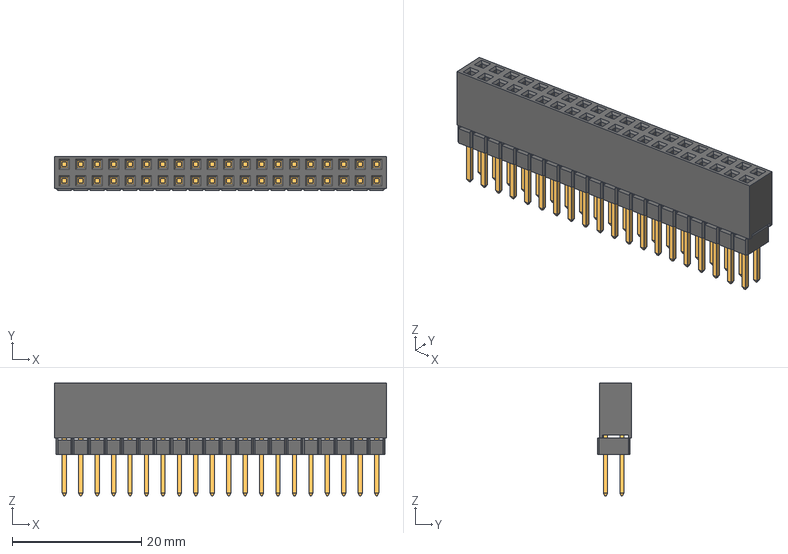
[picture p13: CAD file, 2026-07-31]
v0.2/Hardware/Pin Header - RaspberryPi - Stacking - 2.54mm_V2.step
51.3 x 5.33 x 17.4 mm

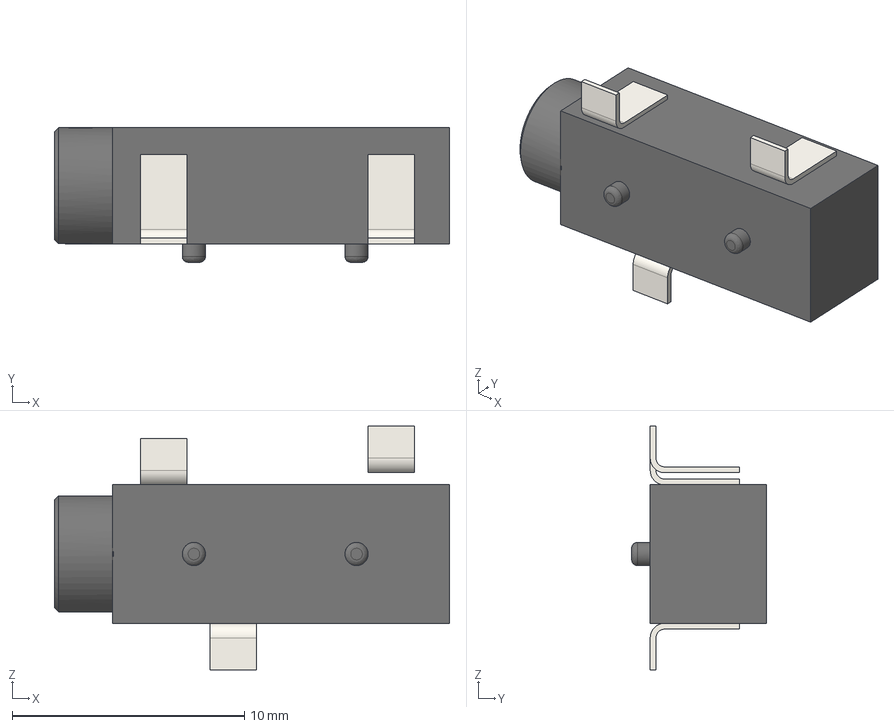
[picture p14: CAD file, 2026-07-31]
v0.2/Hardware/SJ-3523.step
17.0 x 5.80 x 10.5 mm
sj-3524-smt-tr-pi v1 x 2
sj-3524-smt-tr-pi v002 x 2
sj-3524-smt-tr-pi v003 x 2
sj-3524-smt-tr-pi v004 x 2

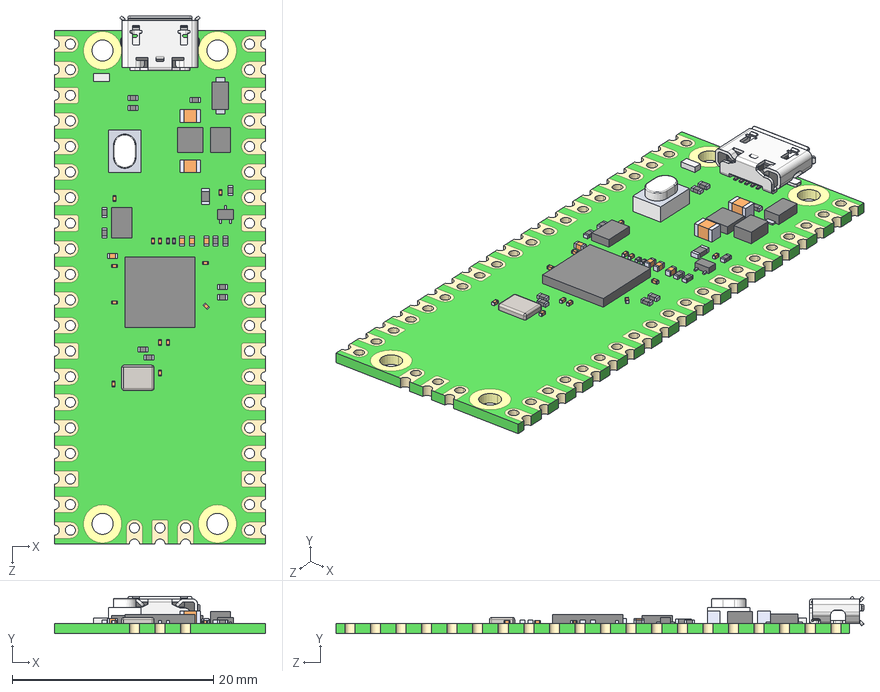
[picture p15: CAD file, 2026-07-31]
v0.2/Hardware/Raspberry Pi Pico-R3.STEP
21.0 x 3.69 x 52.4 mm
PCB, Raspberry Pi Pico-R3
MicroUSB Port, Raspberry Pi Pico-R3
RP2040 Microcontroller, Raspberry Pi Pico-R3
SW1, Tact Switch, Raspberry Pi Pico-R3
D1, Diode, Schottky, Raspberry Pi Pico-R3
D2, QSME-C194, LED, Raspberry Pi Pico-R3
L1, Inductor, Raspberry Pi Pico-R3
U2, RT6150B-33GQW, Buck Boost Converter, Raspberry Pi Pico-R3
U3, W25Q16JVUXIQ, Serial NOR Flash 16 Mbit, Raspberry Pi Pico-R3
Q1, MOSFET, DMG1012T, Raspberry Pi Pico-R3
X1, X12M000000S096, 12 Mhz Crystal Resonator, Raspberry Pi Pico-R3
SMD Resistor, Configurable, Raspberry Pi Pico-R3_R1
SMD Resistor, Configurable, Raspberry Pi Pico-R3_R2
SMD Resistor, Configurable, Raspberry Pi Pico-R3_R3
SMD Resistor, Configurable, Raspberry Pi Pico-R3_R4
SMD Resistor, Configurable, Raspberry Pi Pico-R3_R5
SMD Resistor, Configurable, Raspberry Pi Pico-R3_R6
SMD Resistor, Configurable, Raspberry Pi Pico-R3_R7
SMD Resistor, Configurable, Raspberry Pi Pico-R3_R8
SMD Resistor, Configurable, Raspberry Pi Pico-R3_R9
SMD Resistor, Configurable, Raspberry Pi Pico-R3_R10
SMD Resistor, Configurable, Raspberry Pi Pico-R3_R11
SMD Resistor, Configurable, Raspberry Pi Pico-R3_R12
SMD Resistor, Configurable, Raspberry Pi Pico-R3_R13
SMD Resistor, Configurable, Raspberry Pi Pico-R3_R14
SMD Resistor, Configurable, Raspberry Pi Pico-R3_R15
SMD Capacitor, Configurable, Raspberry Pi Pico-R3_C1
SMD Capacitor, Configurable, Raspberry Pi Pico-R3_C2
SMD Capacitor, Configurable, Raspberry Pi Pico-R3_C3
SMD Capacitor, Configurable, Raspberry Pi Pico-R3_C4
SMD Capacitor, Configurable, Raspberry Pi Pico-R3_C5
SMD Capacitor, Configurable, Raspberry Pi Pico-R3_C6
SMD Capacitor, Configurable, Raspberry Pi Pico-R3_C7
SMD Capacitor, Configurable, Raspberry Pi Pico-R3_C8
SMD Capacitor, Configurable, Raspberry Pi Pico-R3_C9
SMD Capacitor, Configurable, Raspberry Pi Pico-R3_C10
SMD Capacitor, Configurable, Raspberry Pi Pico-R3_C11
SMD Capacitor, Configurable, Raspberry Pi Pico-R3_C12
SMD Capacitor, Configurable, Raspberry Pi Pico-R3_C13
SMD Capacitor, Configurable, Raspberry Pi Pico-R3_C14
SMD Capacitor, Configurable, Raspberry Pi Pico-R3_C15
SMD Capacitor, Configurable, Raspberry Pi Pico-R3_C16
SMD Capacitor, Configurable, Raspberry Pi Pico-R3_C17
SMD Capacitor, Configurable, Raspberry Pi Pico-R3_C18

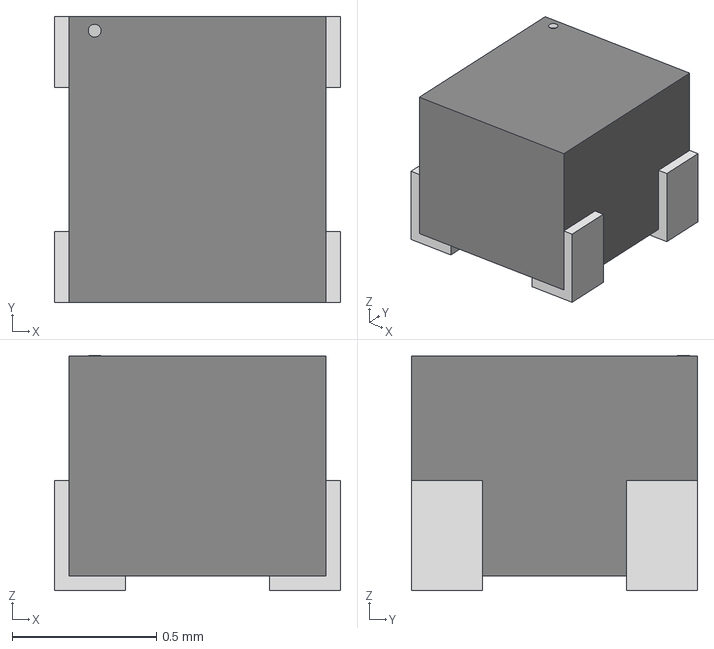
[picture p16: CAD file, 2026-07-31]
v0.2/Hardware/XL-0807RGBC-WS2812B_XLG.step
0.99 x 0.99 x 0.815 mm

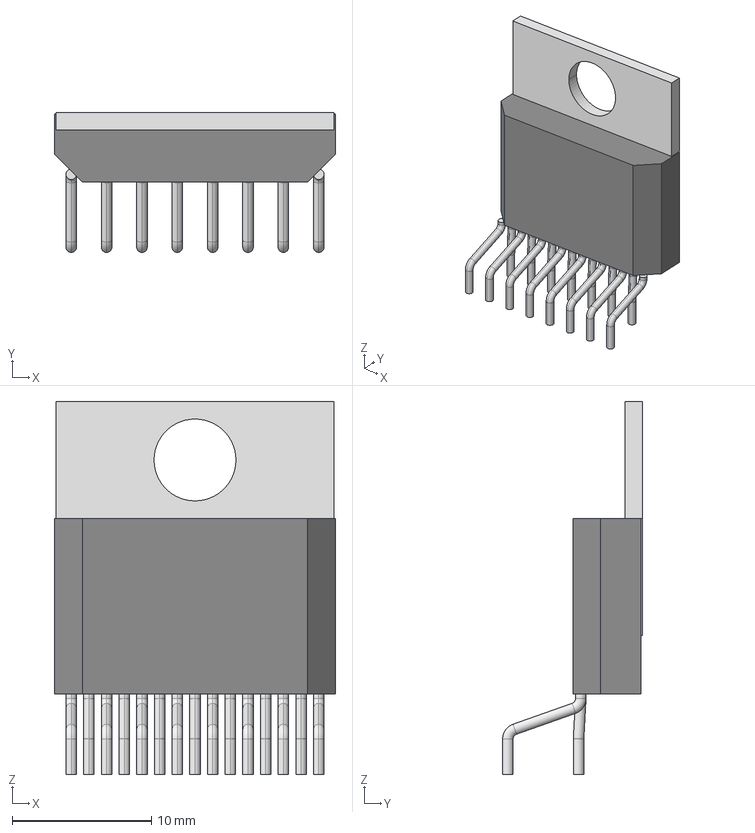
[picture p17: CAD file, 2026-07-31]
v0.2/Hardware/Multiwatt15_V_STM.step
20.2 x 10.1 x 26.8 mm

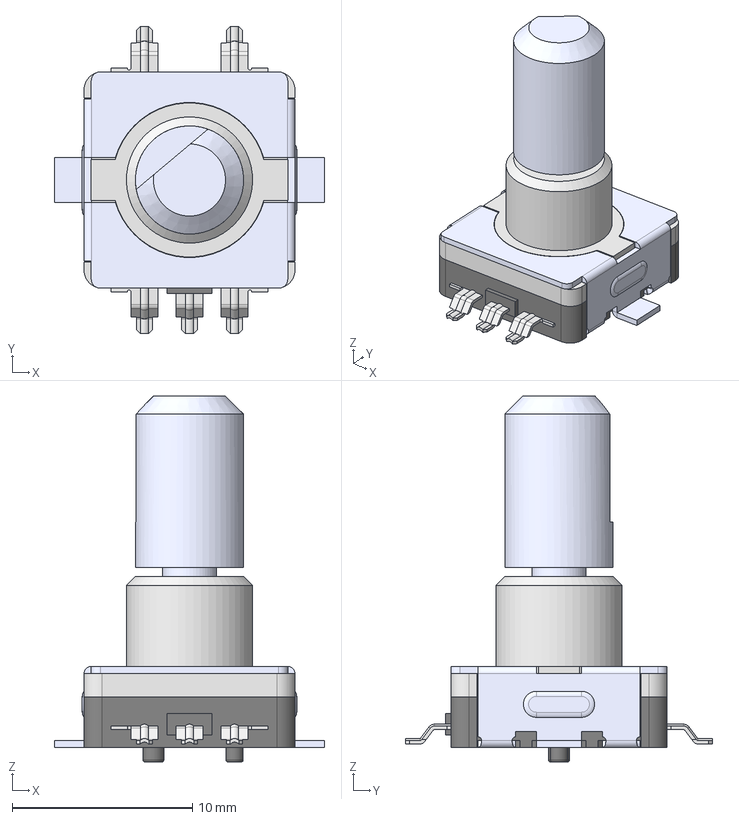
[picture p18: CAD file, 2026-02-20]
v0.2/Hardware/EC11-SMD-15F-black.step
15.0 x 17.0 x 20.3 mm
Lb5
15F
EC11-Housing-SMD

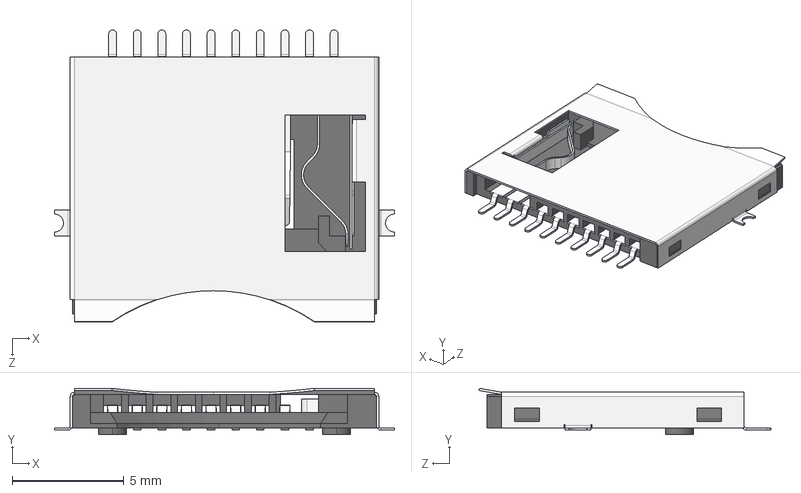
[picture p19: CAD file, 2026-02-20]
v0.2/Hardware/Socket Micro SD.STEP
15.2 x 2.07 x 13.1 mm
Base
Terminal 01 x 8
Terminal 02
Terminal 03
Socket Cover

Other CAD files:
v0.2/Hardware/C18594.step
v0.1/Hardware/EC11-SMD-15F-black.step
v0.1/Hardware/C18594.step
v0.1/Hardware/H1102NLT.step
v0.1/Hardware/Socket Micro SD.STEP

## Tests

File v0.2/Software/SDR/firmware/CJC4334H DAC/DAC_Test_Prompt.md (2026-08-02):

# Test the CJC4334H DAC
I want to use the Raspberry Pi Pico SDK to test the CJC4334H DAC.  It is connected tho the YD-RP2040 I2S using the following pins:

 GP16 (SCK), GP17 (WS/LRCK), and GP18 (SD).
 The MCLK can be connected to a 24.576 MHz oscillator or GP15 (selected by jumper).

 I need to test the DAC by outputing a sine wave to the audio output jack, or something more interesting if you like.  The output of the DAC feeds a PAM8908 headphone amplifier.  I need to test this too, because I have another board that I wish to use this circuit on, and it has not yet been tested.  The DAC has been tested, but to drive the PAM8908 I need it to work, and it has not been tested using the Pico SDK.

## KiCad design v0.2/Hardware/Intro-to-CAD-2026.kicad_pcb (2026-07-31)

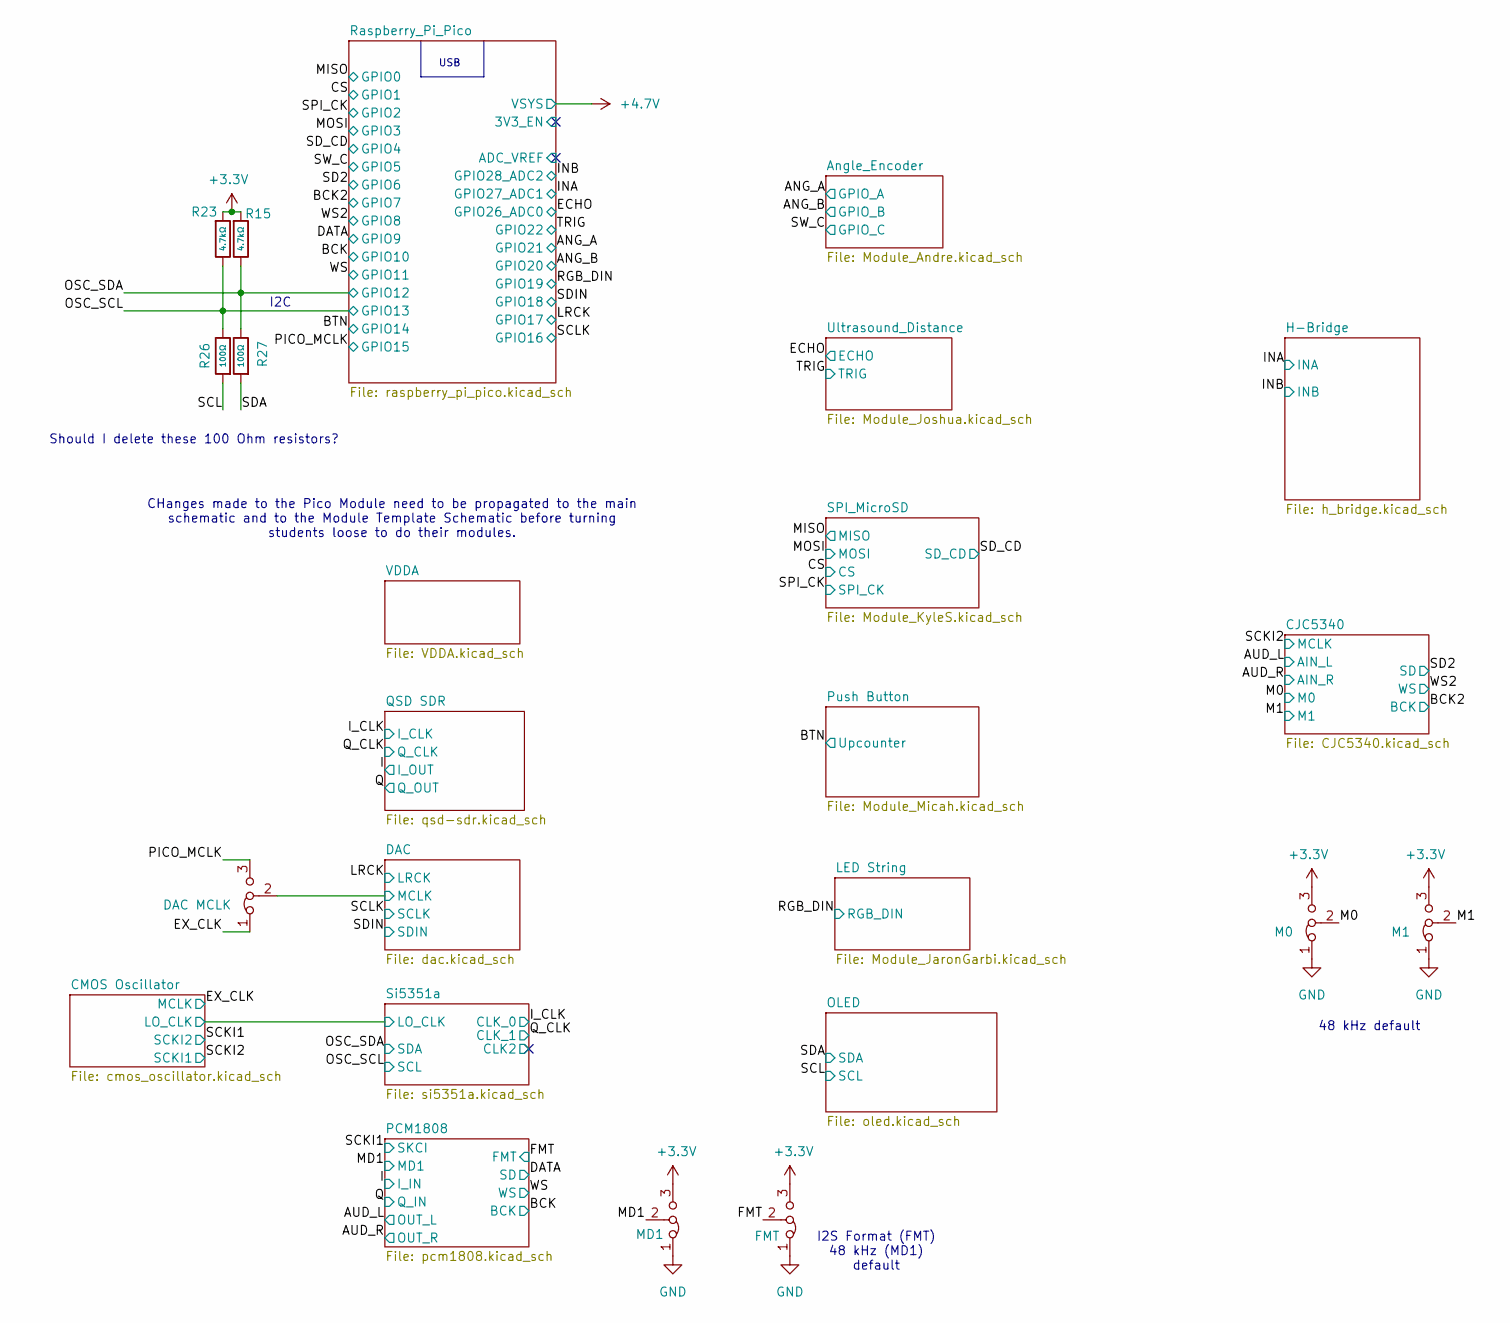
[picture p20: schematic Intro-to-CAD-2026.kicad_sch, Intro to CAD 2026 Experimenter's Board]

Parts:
JP6: DAC MCLK; SolderJumper-3_P1.3mm_Bridged12_RoundedPad1.0x1.5mm_NumberL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
JP11: M0; SolderJumper-3_P1.3mm_Bridged12_RoundedPad1.0x1.5mm_NumberL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
JP12: M1; SolderJumper-3_P1.3mm_Bridged12_RoundedPad1.0x1.5mm_NumberL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
JP13: FMT; SolderJumper-3_P1.3mm_Bridged12_RoundedPad1.0x1.5mm_NumberL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
JP14: MD1; SolderJumper-3_P1.3mm_Bridged12_RoundedPad1.0x1.5mm_NumberL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
R15, R23: 4.7kΩ; R_0805; Overload Voltage (Max) 150V; Tolerance ±1%; Part 0805W8F4701T5E; LCSC C17673
R26, R27: 100Ω; R_0805; Overload Voltage (Max) 150V; Tolerance ±1%; Part 0805W8F1000T5E; LCSC C17408

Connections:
+3.3V: JP11.3 (B), JP12.3 (B), JP13.3 (B), JP14.3 (B), R15.1, R23.1; also elsewhere on the board
/DAC/MCLK: JP6.2 (C); also elsewhere on the board
/EX_CLK: JP6.1 (A); also elsewhere on the board
/FMT: JP13.2 (C); also elsewhere on the board
/M0: JP11.2 (C); also elsewhere on the board
/M1: JP12.2 (C); also elsewhere on the board
/MD1: JP14.2 (C); also elsewhere on the board
/OSC_SCL: R23.2, R26.2; also elsewhere on the board
/OSC_SDA: R15.2, R27.2; also elsewhere on the board
/PICO_MCLK: JP6.3 (B); also elsewhere on the board
/SCL: R26.1; also elsewhere on the board
/SDA: R27.1; also elsewhere on the board
GND: JP11.1 (A), JP12.1 (A), JP13.1 (A), JP14.1 (A); also elsewhere on the board

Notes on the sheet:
CHanges made to the Pico Module need to be propagated to the main schematic and to the Module Template Schematic before turning students loose to do their modules.
Should I delete these 100 Ohm resistors?
I2S Format (FMT) 48 kHz (MD1) default
I2C
USB
48 kHz default

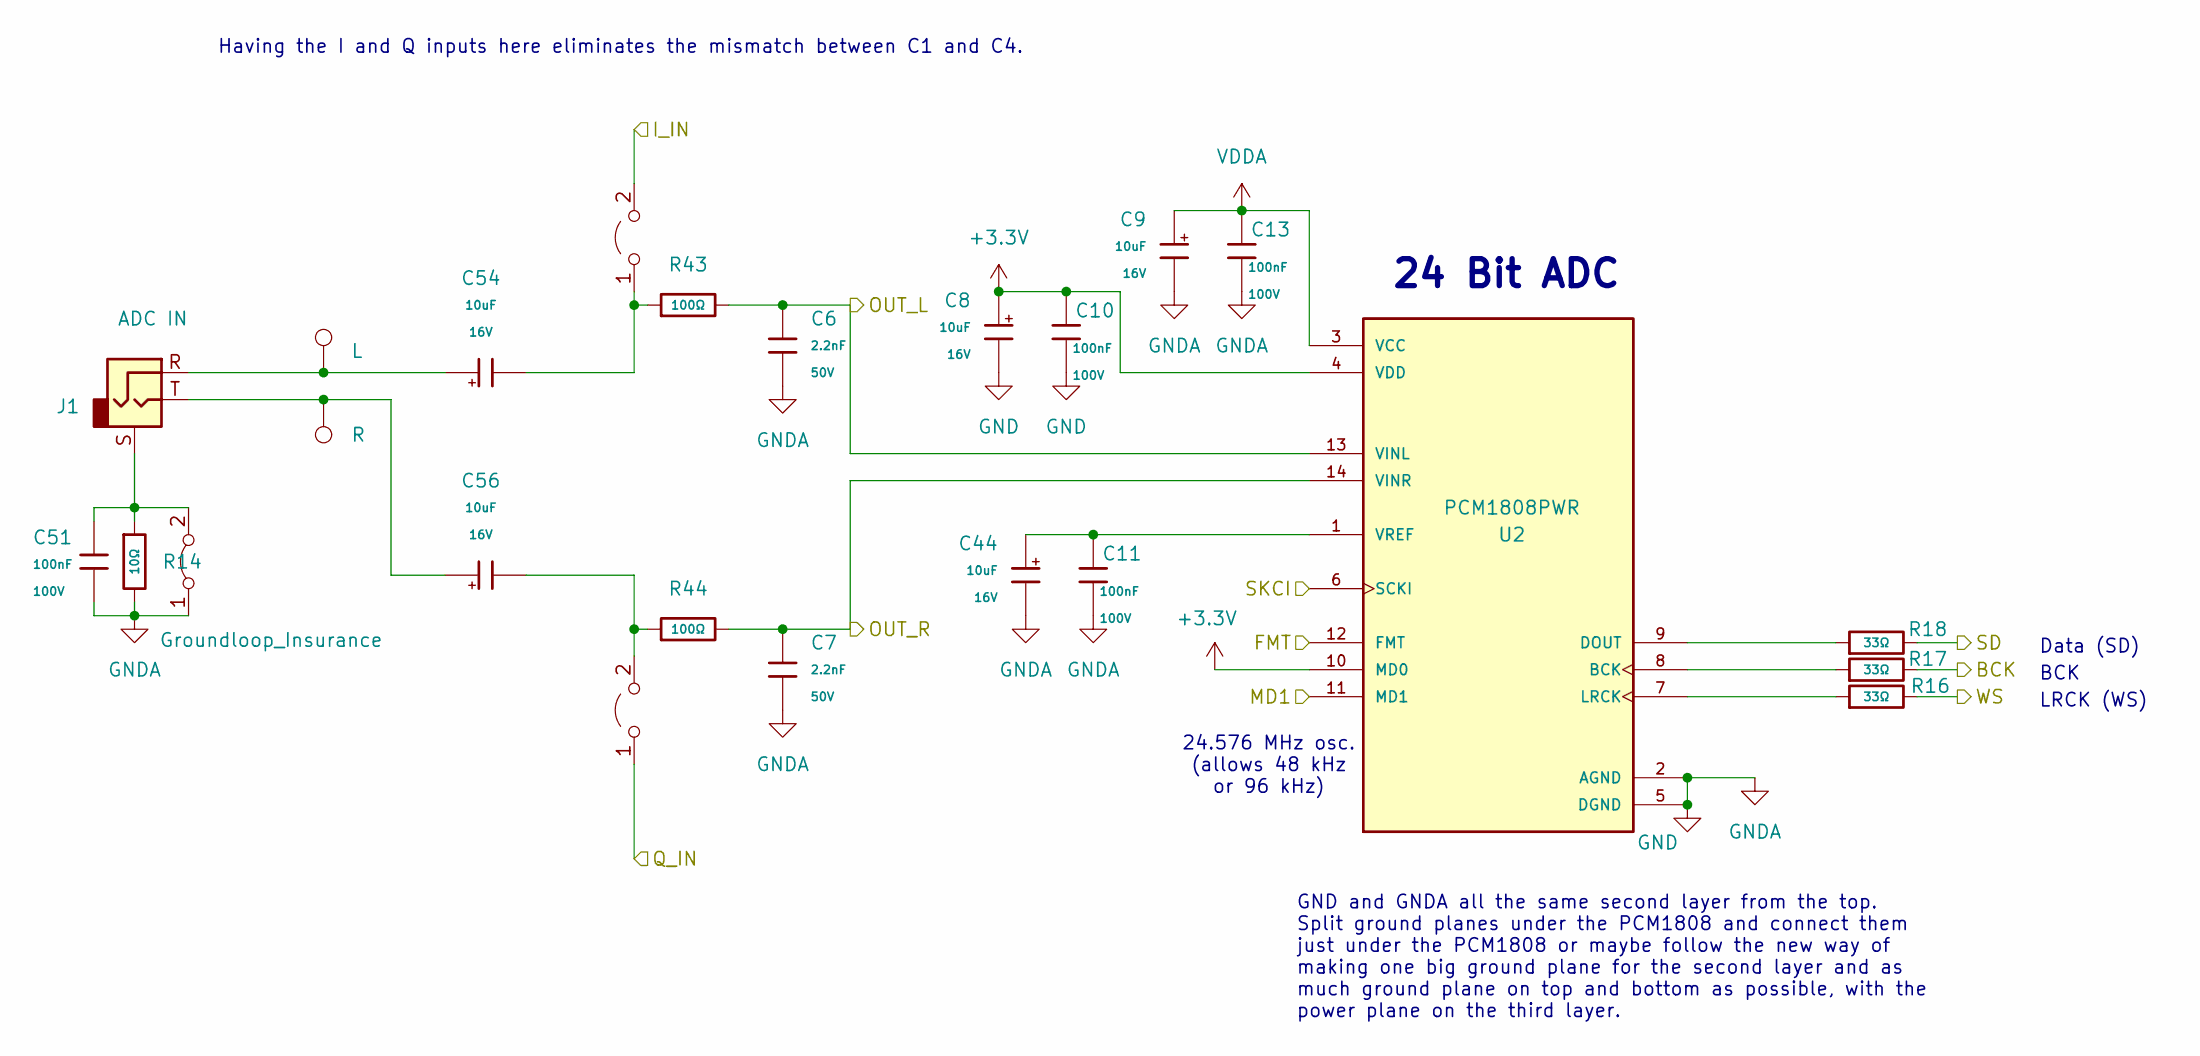
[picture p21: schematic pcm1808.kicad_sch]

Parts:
C6, C7: 2.2nF; C_0805; Voltage Rated 50V; Tolerance ±5%; Part CL21C222JBFNNNE; LCSC C28260
C8, C9, C44, C54, C56: 10uF; C_CASE-A-3216-18(mm); Tolerance ±10%; Rated Voltage 16V; Part TAJA106K016RNJ; LCSC C7171
C10, C11, C13, C51: 100nF; C_0805; Voltage Rated 100V; Tolerance ±10%; Part CL21B104KCFNNNE; LCSC C28233
J1: ADC IN; Jack_3.5mm_CUI_SJ-3523-SMT_Horizontal; LCSC C18594
JP18: I->ADC; SolderJumper-2_P1.3mm_Open_RoundedPad1.0x1.5mm
JP19: Q->ADC; SolderJumper-2_P1.3mm_Open_RoundedPad1.0x1.5mm
R14: 10Ω; R_0603; Overload Voltage (Max) 75V; Tolerance ±1%; Part 0603WAF100JT5E; LCSC C22859
R16, R17, R18: 33Ω; R_0805; Overload Voltage (Max) 150V; Tolerance ±1%; Part 0805W8F330JT5E; LCSC C17634
R43, R44: 100Ω; R_0603; Overload Voltage (Max) 75V; Tolerance ±1%; Part 0603WAF1000T5E; LCSC C22775
TP1: L; TestPoint_THTPad_D2.0mm_Drill1.0mm
TP2: R; TestPoint_THTPad_D2.0mm_Drill1.0mm
U2: PCM1808PWR; TSSOP-14_4.4x5mm_P0.65mm; PARTREV B; LCSC C55513
e4: Groundloop_Insurance; SolderJumper-2_P1.3mm_Bridged_RoundedPad1.0x1.5mm

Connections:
+3.3V: C8.1, C10.2, U2.4 (VDD), U2.10 (MD0); also elsewhere on the board
/AUD_L: C6.1, R43.2, U2.13 (VINL); also elsewhere on the board
/AUD_R: C7.1, R44.2, U2.14 (VINR); also elsewhere on the board
/BCK: R17.2; also elsewhere on the board
/DATA: R18.2; also elsewhere on the board
/FMT: U2.12 (FMT); also elsewhere on the board
/I: JP18.2 (B); also elsewhere on the board
/MD1: U2.11 (MD1); also elsewhere on the board
/Q: JP19.1 (A); also elsewhere on the board
/SCKI1: U2.6 (SCKI); also elsewhere on the board
/WS: R16.2; also elsewhere on the board
GND: C6.2, C7.2, C8.2, C9.2, C10.1, C11.1, C13.1, C44.2, C51.1, R14.2, U2.2 (AGND), U2.5 (DGND), e4.1 (A); also elsewhere on the board
unnamed: C54.1, J1.R, TP1.1 (1_1)
unnamed: C56.1, J1.T, TP2.1 (1_1)
unnamed: C54.2, JP18.1 (A), R43.1
unnamed: C56.2, JP19.2 (B), R44.1
unnamed: R17.1, U2.8 (BCK)
unnamed: R18.1, U2.9 (DOUT)
unnamed: R16.1, U2.7 (LRCK)
unnamed: C11.2, C44.1, U2.1 (VREF)
unnamed: C51.2, J1.S, R14.1, e4.2 (B)
VDDA: C9.1, C13.2, U2.3 (VCC); also elsewhere on the board

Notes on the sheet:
24 Bit ADC
Data (SD)
24.576 MHz osc. (allows 48 kHz or 96 kHz)
BCK
GND and GNDA all the same second layer from the top. Split ground planes under the PCM1808 and connect them just under the PCM1808 or maybe follow the new way of making one big ground plane for the second layer and as much ground plane on top and bottom as possible, with the power plane on the thir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
Having the I and Q inputs here eliminates the mismatch between C1 and C4.
LRCK (WS)

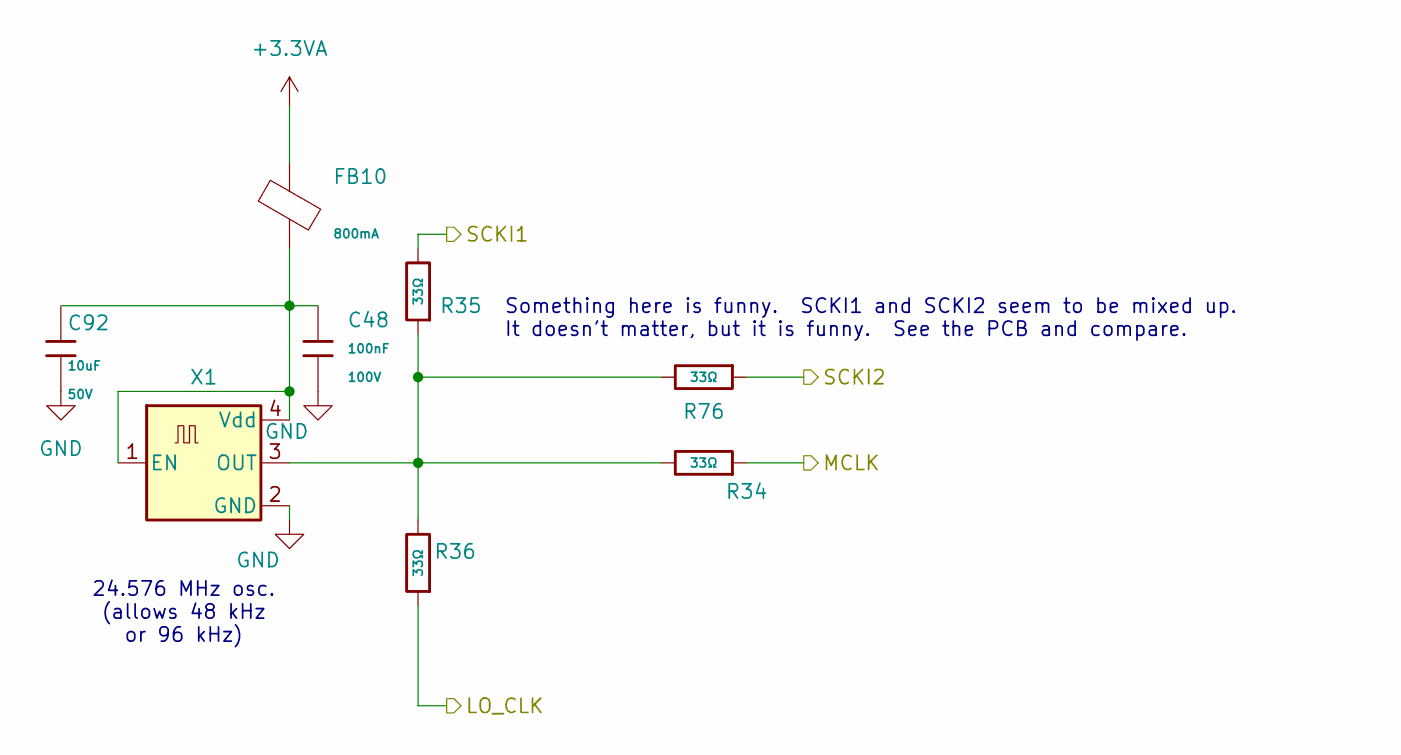
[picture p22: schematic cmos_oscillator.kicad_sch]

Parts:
C48: 100nF; C_0805; Voltage Rated 100V; Tolerance ±10%; Part CL21B104KCFNNNE; LCSC C28233
C92: 10uF; C_1206; Voltage Rated 50V; Tolerance ±10%; Part CL31A106KBHNNNE; LCSC C13585
FB10: FB_0805; Current Rating 800mA; Tolerance ±25%; Part GZ2012D101TF; LCSC C1015
R34, R35, R36, R76: 33Ω; R_0805; Overload Voltage (Max) 150V; Tolerance ±1%; Part 0805W8F330JT5E; LCSC C17634
X1: YC24.576MUBCE2O; Oscillator_SMD_Abracon_ASE-4Pin_3.2x2.5mm; LCSC C52204801

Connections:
+3.3VA: FB10.1; also elsewhere on the board
/CMOS Oscillator/LO_CLK: R36.1; also elsewhere on the board
/EX_CLK: R34.1; also elsewhere on the board
/SCKI1: R76.1; also elsewhere on the board
/SCKI2: R35.2; also elsewhere on the board
GND: C48.2, C92.2, X1.2 (GND); also elsewhere on the board
unnamed: C48.1, C92.1, FB10.2, X1.1 (EN), X1.4 (Vdd)
unnamed: R34.2, R35.1, R36.2, R76.2, X1.3 (OUT)

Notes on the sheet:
Something here is funny. SCKI1 and SCKI2 seem to be mixed up. It doesn't matter, but it is funny. See the PCB and compare.
24.576 MHz osc. (allows 48 kHz or 96 kHz)

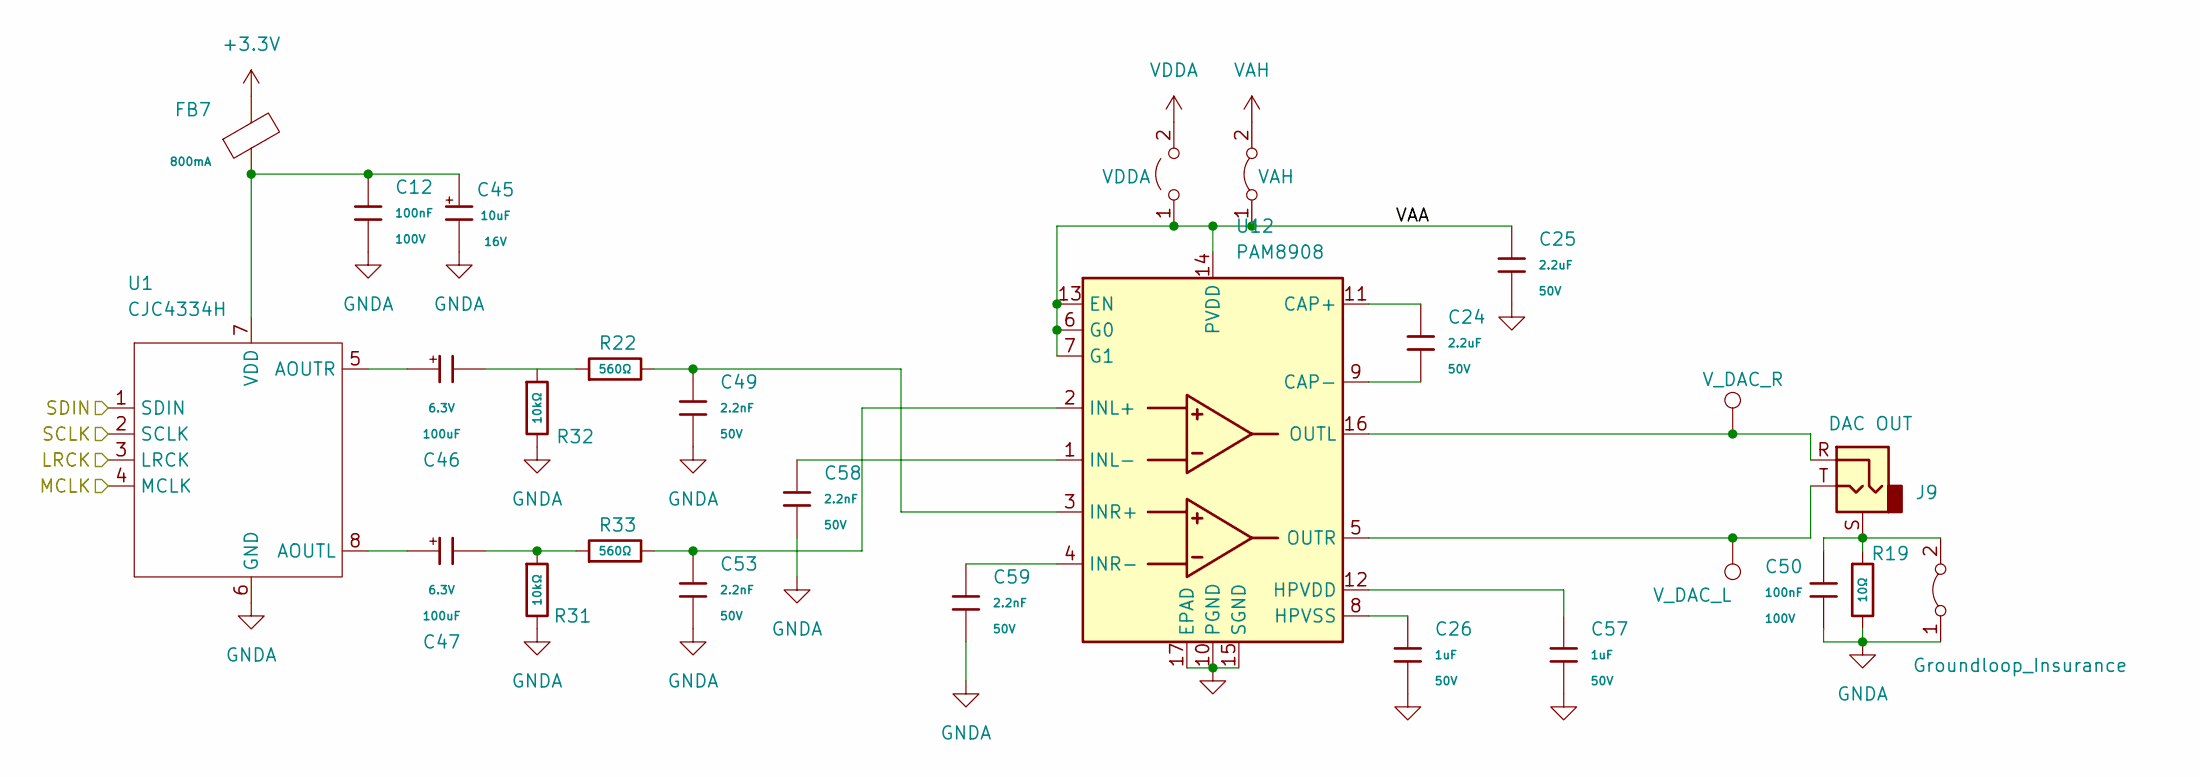
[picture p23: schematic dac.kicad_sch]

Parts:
C12, C50: 100nF; C_0805; Voltage Rated 100V; Tolerance ±10%; Part CL21B104KCFNNNE; LCSC C28233
C24, C25: 2.2uF; C_0805; Voltage Rated 50V; Tolerance ±10%; Part CL21A225KBQNNNE; LCSC C377773
C26, C57: 1uF; C_0805; Voltage Rated 50V; Tolerance ±10%; Part CL21B105KBFNNNE; LCSC C28323
C45: 10uF; C_CASE-A-3216-18(mm); Tolerance ±10%; Rated Voltage 16V; Part TAJA106K016RNJ; LCSC C7171
C46, C47: 100uF; C_CASE-B-3528-21(mm); Tolerance ±10%; Rated Voltage 6.3V; Part TAJB107K006RNJ; LCSC C16133
C49, C53, C58, C59: 2.2nF; C_0805; Voltage Rated 50V; Tolerance ±5%; Part CL21C222JBFNNNE; LCSC C28260
FB7: FB_0805; Current Rating 800mA; Tolerance ±25%; Part GZ2012D101TF; LCSC C1015
J9: 3.5mm_Jack; Jack_3.5mm_CUI_SJ-3523-SMT_Horizontal; LCSC C18594
JP3: VDDA; SolderJumper-2_P1.3mm_Open_RoundedPad1.0x1.5mm
R19: 10Ω; R_0603; Overload Voltage (Max) 75V; Tolerance ±1%; Part 0603WAF100JT5E; LCSC C22859
R22, R33: 560Ω; R_0805; Overload Voltage (Max) 150V; Tolerance ±1%; Part 0805W8F5600T5E; LCSC C28636
R31, R32: 10kΩ; R_0805; Overload Voltage (Max) 150V; Tolerance ±1%; Part 0805W8F1002T5E; LCSC C17414
TP8: V_DAC_R; TestPoint_THTPad_D2.0mm_Drill1.0mm
TP9: V_DAC_L; TestPoint_THTPad_D2.0mm_Drill1.0mm
U1: CJC4334H; SOIC-8_3.9x4.9mm_P1.27mm; LCSC C41417670
U12: PAM8908; QFN-16-1EP_3x3mm_P0.5mm_EP1.7x1.7mm; LCSC C33233
e2: VAH; SolderJumper-2_P1.3mm_Bridged_RoundedPad1.0x1.5mm
e3: Groundloop_Insurance; SolderJumper-2_P1.3mm_Bridged_RoundedPad1.0x1.5mm

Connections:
+3.3V: FB7.2; also elsewhere on the board
+4.7V: e2.2 (B); also elsewhere on the board
/DAC/MCLK: U1.4 (MCLK); also elsewhere on the board
/DAC/VAA: C25.1, JP3.1 (A), U12.6 (G0), U12.7 (G1), U12.13 (EN), U12.14 (PVDD), e2.1 (A)
/LRCK: U1.3 (LRCK); also elsewhere on the board
/SCLK: U1.2 (SCLK); also elsewhere on the board
/SDIN: U1.1 (SDIN); also elsewhere on the board
GND: C12.2, C25.2, C26.2, C45.2, C49.2, C50.1, C53.2, C57.2, C58.2, C59.2, R19.2, R31.2, R32.2, U1.6 (GND), U12.10 (PGND), U12.15 (SGND), U12.17 (EPAD), e3.1 (A); also elsewhere on the board
unnamed: C46.2, R22.1
unnamed: C47.2, R31.1, R33.1
unnamed: C47.1, U1.8 (AOUTL)
unnamed: C46.1, U1.5 (AOUTR)
unnamed: C12.1, C45.1, FB7.1, U1.7 (VDD)
unnamed: C24.1, U12.11 (CAP+)
unnamed: C24.2, U12.9 (CAP-)
unnamed: C57.1, U12.12 (HPVDD)
unnamed: C26.1, U12.8 (HPVSS)
unnamed: C53.1, R33.2, U12.2 (INL+)
unnamed: C58.1, U12.1 (INL-)
unnamed: C49.1, R22.2, U12.3 (INR+)
unnamed: C59.1, U12.4 (INR-)
unnamed: J9.R, TP8.1 (1_1), U12.16 (OUTL)
unnamed: J9.T, TP9.1 (1_1), U12.5 (OUTR)
unnamed: C50.2, J9.S, R19.1, e3.2 (B)
VDDA: JP3.2 (B); also elsewhere on the board

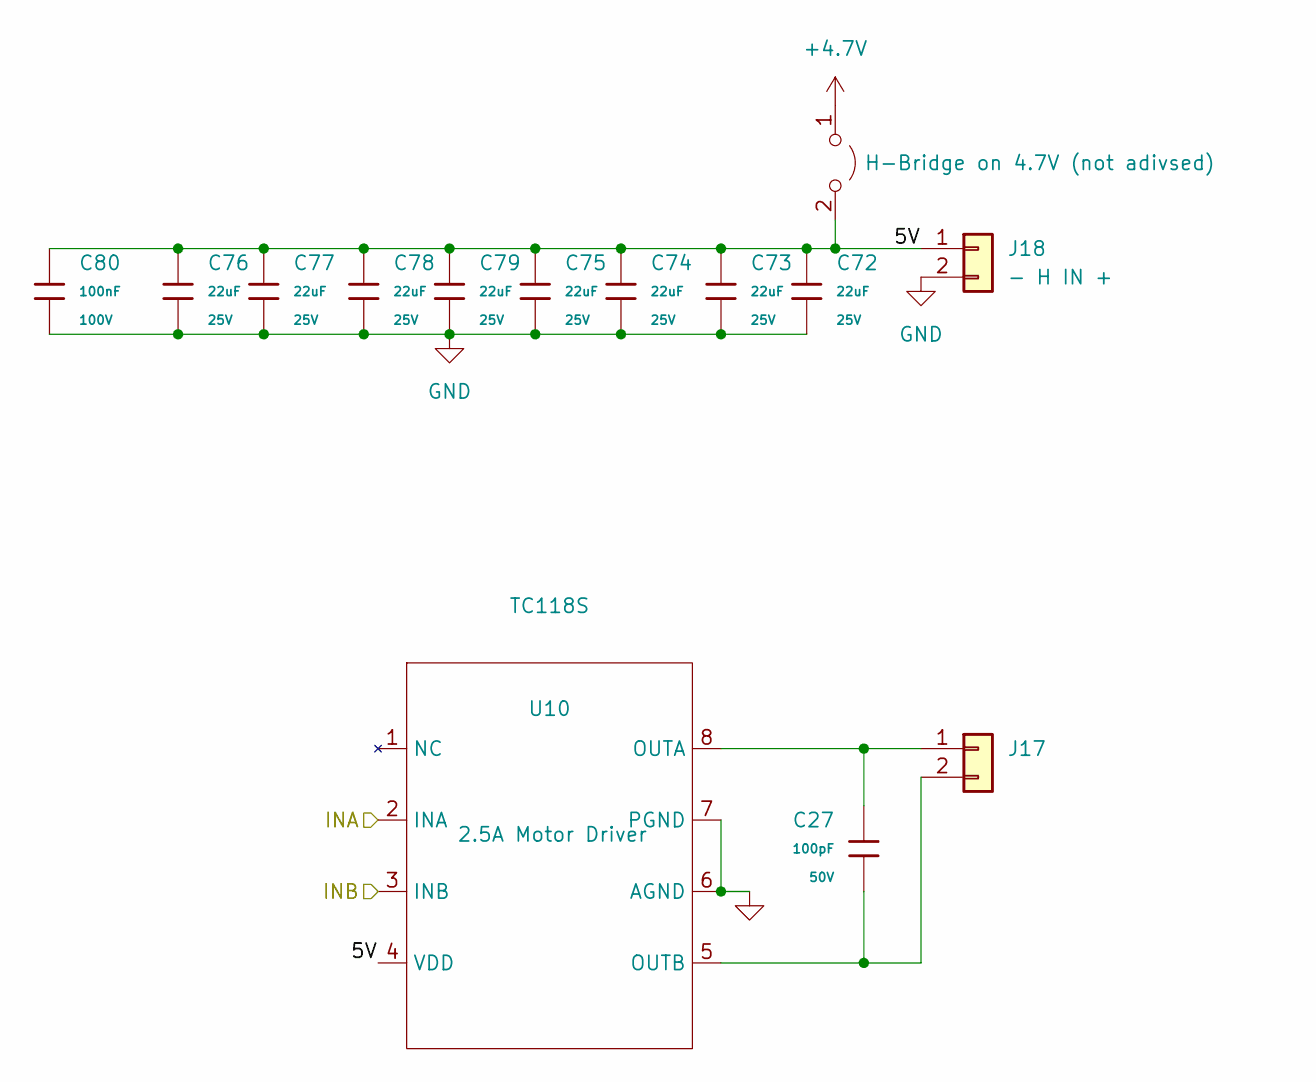
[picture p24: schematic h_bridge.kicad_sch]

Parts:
C27: 100pF; C_0402; Voltage Rated 50V; Tolerance ±5%; Part 0402CG101J500NT; LCSC C1546
C72, C73, C74, C75, C76, C77, C78, C79: 22uF; C_0805; Voltage Rated 25V; Tolerance ±20%; Part CL21A226MAQNNNE; LCSC C45783
C80: 100nF; C_0805; Voltage Rated 100V; Tolerance ±10%; Part CL21B104KCFNNNE; LCSC C28233
J17: H OUT; TerminalBlock_Phoenix_MKDS-1,5-2-5.08_1x02_P5.08mm_Horizont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; LCSC C8465
J18: - H IN +; TerminalBlock_Phoenix_MKDS-1,5-2-5.08_1x02_P5.08mm_Horizont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; LCSC C8465
JP4: H-Bridge on 4.7V (not adivsed); SolderJumper-2_P1.3mm_Open_RoundedPad1.0x1.5mm
U10: TC118S; SOP-8_3.76x4.96mm_P1.27mm; LCSC C88308

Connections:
+4.7V: JP4.1 (A); also elsewhere on the board
/H-Bridge/5V: C72.1, C73.1, C74.1, C75.1, C76.1, C77.1, C78.1, C79.1, C80.1, J18.1, JP4.2 (B), U10.4 (VDD)
/INA: U10.2 (INA); also elsewhere on the board
/INB: U10.3 (INB); also elsewhere on the board
GND: C72.2, C73.2, C74.2, C75.2, C76.2, C77.2, C78.2, C79.2, C80.2, J18.2, U10.6 (AGND), U10.7 (PGND); also elsewhere on the board
unnamed: C27.1, J17.1, U10.8 (OUTA)
unnamed: C27.2, J17.2, U10.5 (OUTB)

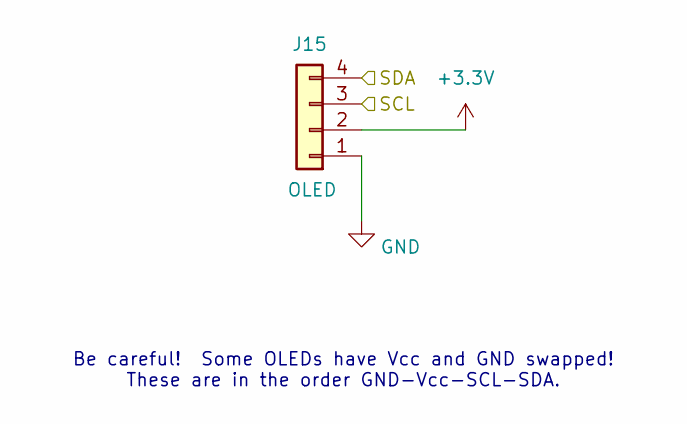
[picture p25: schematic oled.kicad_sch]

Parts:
J15: OLED; PinSocket_1x04_P2.54mm_Vertical; LCSC C2718488

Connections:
+3.3V: J15.2; also elsewhere on the board
/SCL: J15.3; also elsewhere on the board
/SDA: J15.4; also elsewhere on the board
GND: J15.1; also elsewhere on the board

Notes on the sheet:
Be careful! Some OLEDs have Vcc and GND swapped! These are in the order GND-Vcc-SCL-SDA.

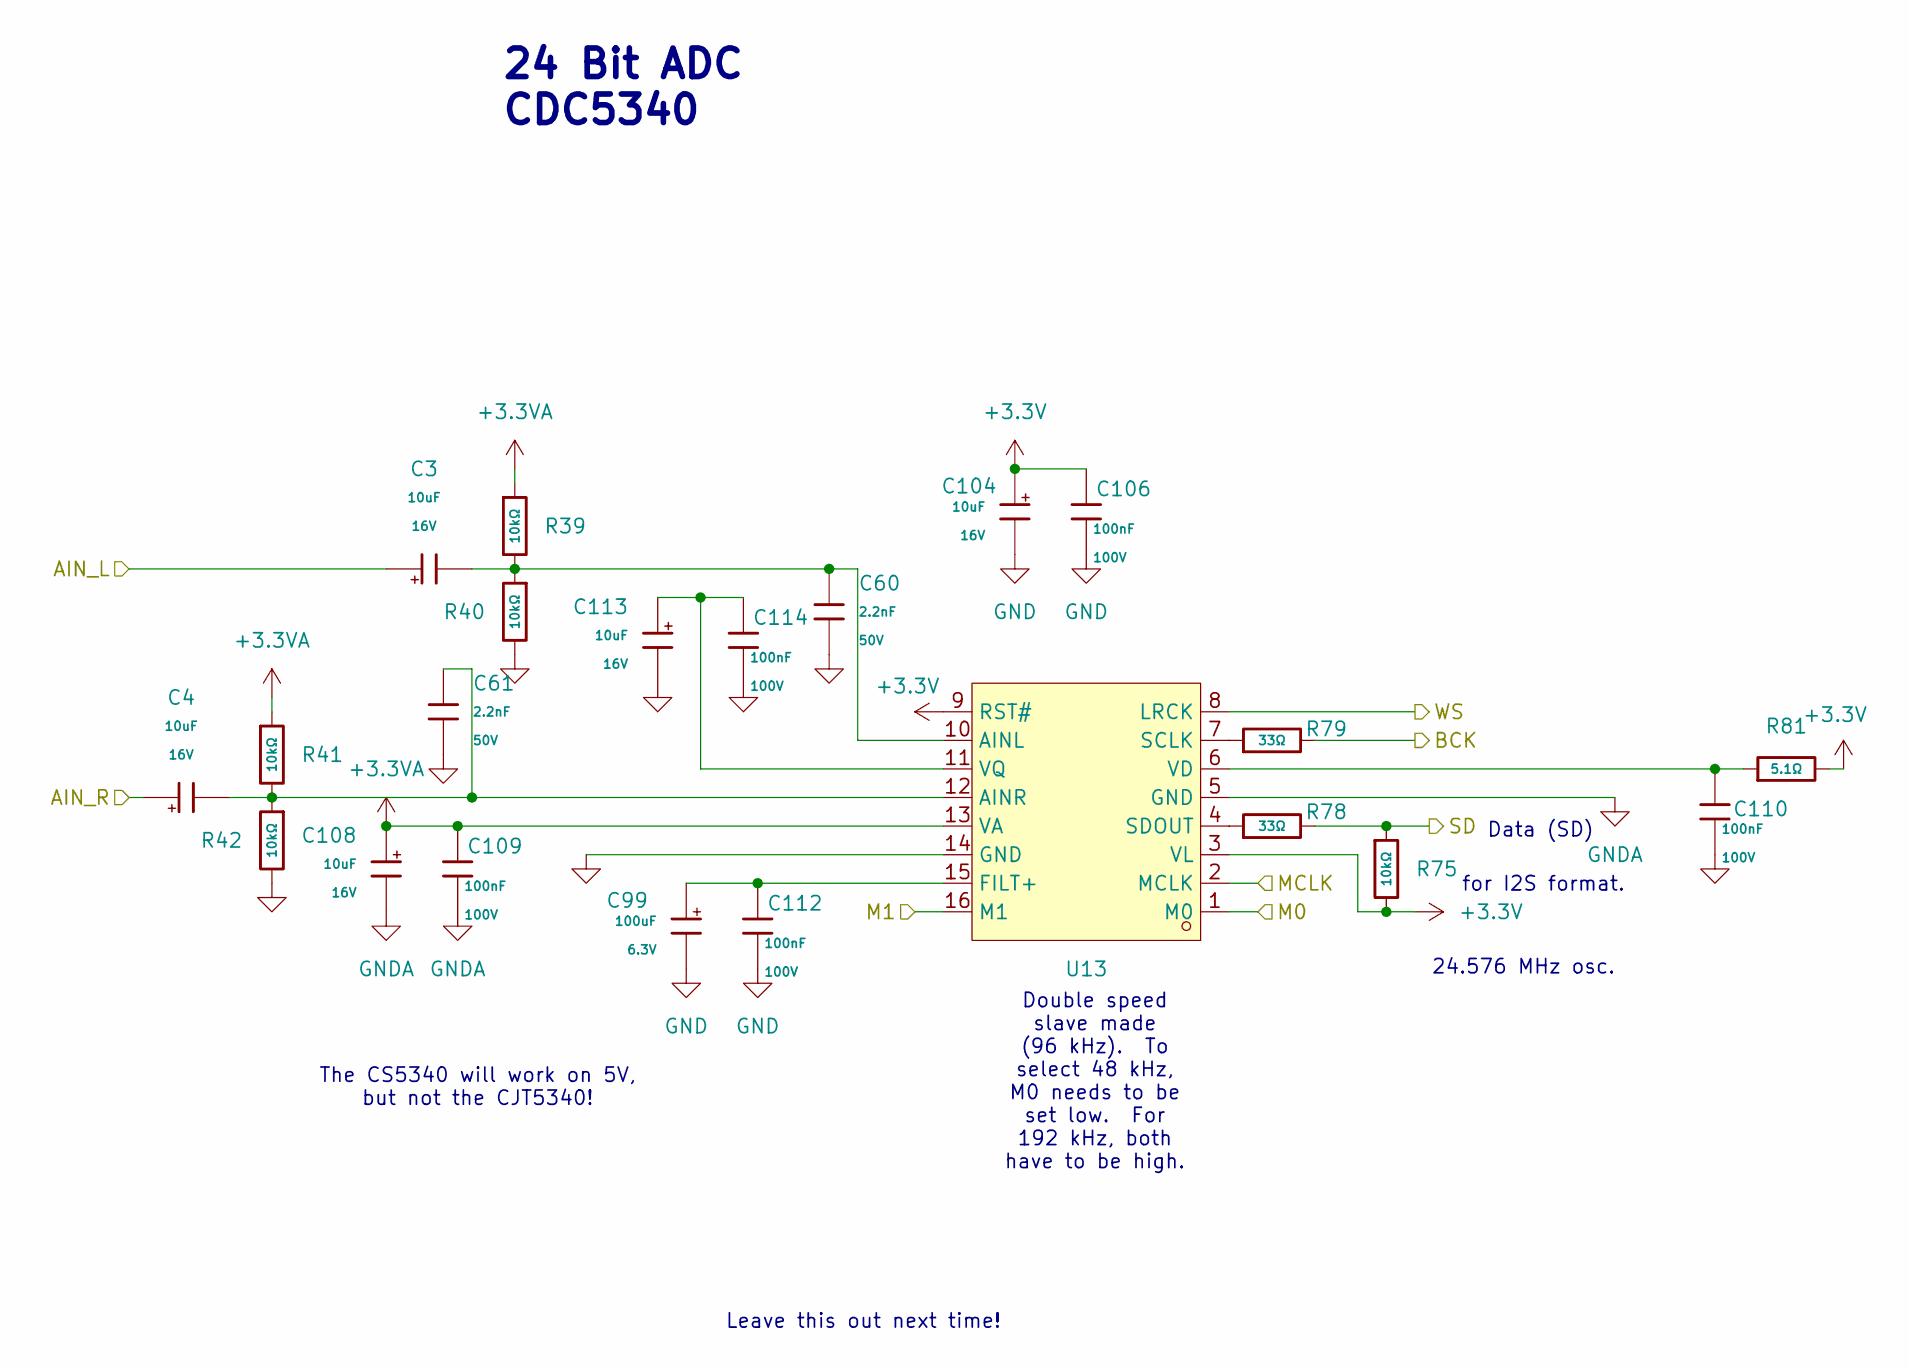
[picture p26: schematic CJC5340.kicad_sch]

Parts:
C3, C4, C104, C108, C113: 10uF; C_CASE-A-3216-18(mm); Tolerance ±10%; Rated Voltage 16V; Part TAJA106K016RNJ; LCSC C7171
C60, C61: 2.2nF; C_0805; Voltage Rated 50V; Tolerance ±5%; Part CL21C222JBFNNNE; LCSC C28260
C99: 100uF; C_CASE-B-3528-21(mm); Tolerance ±10%; Rated Voltage 6.3V; Part TAJB107K006RNJ; LCSC C16133
C106, C109, C110, C112, C114: 100nF; C_0805; Voltage Rated 100V; Tolerance ±10%; Part CL21B104KCFNNNE; LCSC C28233
R39, R40, R41, R42: 10kΩ; R_0402; Overload Voltage (Max) 50V; Tolerance ±1%; Part 0402WGF1002TCE; LCSC C25744
R75: 10kΩ; R_0805; Overload Voltage (Max) 150V; Tolerance ±1%; Part 0805W8F1002T5E; LCSC C17414
R78, R79: 33Ω; R_0805; Overload Voltage (Max) 150V; Tolerance ±1%; Part 0805W8F330JT5E; LCSC C17634
R81: 5.1Ω; R_0805; Overload Voltage (Max) 150V; Tolerance ±1%; Part 0805W8F510KT5E; LCSC C17724
U13: TSSOP-16_4.4x5mm_P0.65mm; Manufacturer Part CJC5340; LCSC Part Name 100dB、192kHz多bit 音频A/D转换器

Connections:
+3.3V: C104.1, C106.2, R75.2, R81.2, U13.3 (VL), U13.9 (RST#); also elsewhere on the board
+3.3VA: C108.1, C109.2, R39.1, R41.1, U13.13 (VA); also elsewhere on the board
/AUD_L: C3.1; also elsewhere on the board
/AUD_R: C4.1; also elsewhere on the board
/BCK2: R79.2; also elsewhere on the board
/M0: U13.1 (M0); also elsewhere on the board
/M1: U13.16 (M1); also elsewhere on the board
/SCKI2: U13.2 (MCLK); also elsewhere on the board
/SD2: R75.1, R78.2; also elsewhere on the board
/WS2: U13.8 (LRCK); also elsewhere on the board
GND: C60.2, C61.2, C99.2, C104.2, C106.1, C108.2, C109.1, C110.1, C112.1, C113.2, C114.1, R40.2, R42.2, U13.5 (GND), U13.14 (GND); also elsewhere on the board
unnamed: C3.2, C60.1, R39.2, R40.1, U13.10 (AINL)
unnamed: C4.2, C61.1, R41.2, R42.1, U13.12 (AINR)
unnamed: C99.1, C112.2, U13.15 (FILT+)
unnamed: R79.1, U13.7 (SCLK)
unnamed: R78.1, U13.4 (SDOUT)
unnamed: C110.2, R81.1, U13.6 (VD)
unnamed: C113.1, C114.2, U13.11 (VQ)

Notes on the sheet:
Double speed slave made (96 kHz). To select 48 kHz, M0 needs to be set low. For 192 kHz, both have to be high.
24.576 MHz osc.
Data (SD)
The CS5340 will work on 5V, but not the CJT5340!
for I2S format.
Leave this out next time!
24 Bit ADC CDC5340

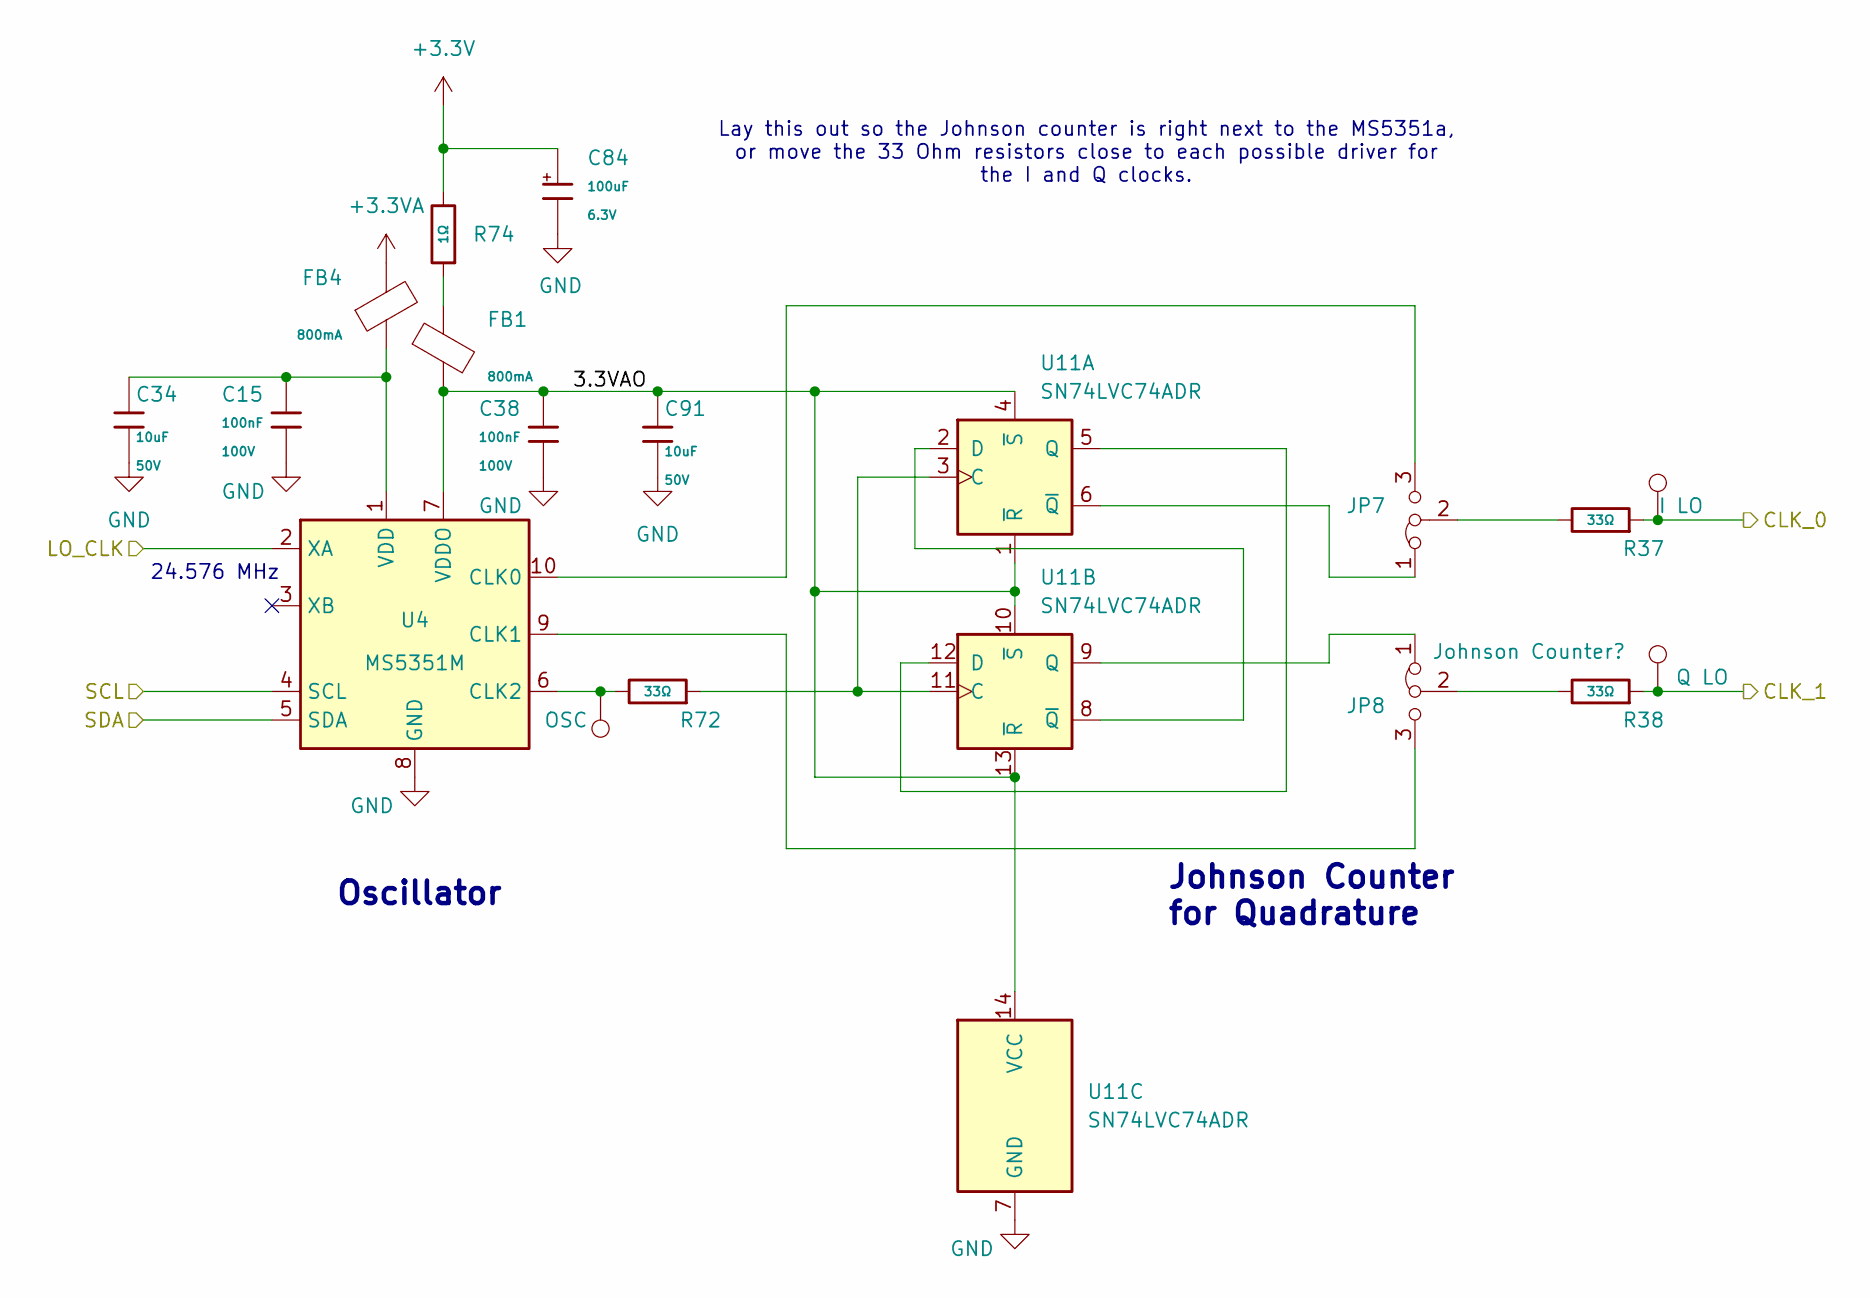
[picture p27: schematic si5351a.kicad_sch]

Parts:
C15, C38: 100nF; C_0805; Voltage Rated 100V; Tolerance ±10%; Part CL21B104KCFNNNE; LCSC C28233
C34, C91: 10uF; C_1206; Voltage Rated 50V; Tolerance ±10%; Part CL31A106KBHNNNE; LCSC C13585
C84: 100uF; C_CASE-B-3528-21(mm); Tolerance ±10%; Rated Voltage 6.3V; Part TAJB107K006RNJ; LCSC C16133
FB1, FB4: FB_0805; Current Rating 800mA; Tolerance ±25%; Part GZ2012D101TF; LCSC C1015
JP7, JP8: Johnson Counter?; SolderJumper-3_P1.3mm_Bridged12_RoundedPad1.0x1.5mm_NumberL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
R37, R38, R72: 33Ω; R_0805; Overload Voltage (Max) 150V; Tolerance ±1%; Part 0805W8F330JT5E; LCSC C17634
R74: 1Ω; R_0805; Overload Voltage (Max) 150V; Tolerance ±1%; Part 0805W8F100KT5E; LCSC C25271
TP3: I LO; TestPoint_THTPad_D2.0mm_Drill1.0mm
TP4: Q LO; TestPoint_THTPad_D2.0mm_Drill1.0mm
TP5: OSC; TestPoint_THTPad_D2.0mm_Drill1.0mm
U4: MS5351M; MSOP-10_3x3mm_P0.5mm; LCSC C1509083
U11: SN74LVC74ADR; SOIC-14_3.9x8.7mm_P1.27mm; LCSC C7864

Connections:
+3.3V: C84.1, R74.2; also elsewhere on the board
+3.3VA: FB4.2; also elsewhere on the board
/CMOS Oscillator/LO_CLK: U4.2 (XA); also elsewhere on the board
/I_CLK: R37.1, TP3.1 (1_1); also elsewhere on the board
/OSC_SCL: U4.4 (SCL); also elsewhere on the board
/OSC_SDA: U4.5 (SDA); also elsewhere on the board
/Q_CLK: R38.1, TP4.1 (1_1); also elsewhere on the board
/Si5351a/3.3VAO: C38.2, C91.1, FB1.2, U4.7 (VDDO), U11.1 (~R), U11.4 (~S), U11.10 (~S), U11.13 (~R), U11.14 (VCC)
GND: C15.1, C34.2, C38.1, C84.2, C91.2, U4.8 (GND), U11.7 (GND); also elsewhere on the board
unnamed: FB1.1, R74.1
unnamed: JP7.1 (A), U11.6 (~Q)
unnamed: JP7.3 (B), U4.10 (CLK0)
unnamed: JP7.2 (C), R37.2
unnamed: JP8.1 (A), U11.9 (Q)
unnamed: JP8.3 (B), U4.9 (CLK1)
unnamed: JP8.2 (C), R38.2
unnamed: R72.2, TP5.1 (1_1), U4.6 (CLK2)
unnamed: C15.2, C34.1, FB4.1, U4.1 (VDD)
unnamed: R72.1, U11.3 (C), U11.11 (C)
unnamed: U11.2 (D), U11.8 (~Q)
unnamed: U11.5 (Q), U11.12 (D)

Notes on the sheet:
Lay this out so the Johnson counter is right next to the MS5351a, or move the 33 Ohm resistors close to each possible driver for the I and Q clocks.
Johnson Counter for Quadrature
24.576 MHz
Oscillator

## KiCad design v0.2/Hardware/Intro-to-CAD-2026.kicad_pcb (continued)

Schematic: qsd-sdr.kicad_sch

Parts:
C1, C20, C23, C30, C31, C32, C52, C81: 100nF; C_0805; Voltage Rated 100V; Tolerance ±10%; Part CL21B104KCFNNNE; LCSC C28233
C14, C16, C19, C22: 10nF; C_0603; Voltage Rated 50V; Tolerance ±5%; LCSC C1664
C18, C28, C93, C94: 330pF; C_0603; Voltage Rated 50V; Tolerance ±5%; Part CL10C331JB8NNNC; LCSC C1664
C21, C29: 1uF; C_0805; Voltage Rated 50V; Tolerance ±10%; Part CL21B105KBFNNNE; LCSC C28323
C33: 10uF; C_1206; Voltage Rated 50V; Tolerance ±10%; Part CL31A106KBHNNNE; LCSC C13585
C82, C83: 100uF; C_CASE-B-3528-21(mm); Tolerance ±10%; Rated Voltage 6.3V; Part TAJB107K006RNJ; LCSC C16133
FB3: FB_0805; Current Rating 500mA; Tolerance ±25%; Part GZ2012D601TF; LCSC C1017
J11: SDR ANT; Conn_Coaxial_Frohne; not fitted
J12: SDR Out; Jack_3.5mm_CUI_SJ-3523-SMT_Horizontal; LCSC C18594
JP1: Turns; SolderJumper-2_P1.3mm_Bridged2Bar_RoundedPad1.0x1.5mm
JP9, JP10: 330pf; SolderJumper-2_P1.3mm_Bridged_RoundedPad1.0x1.5mm
JP86: Filter; SolderJumper-2_P1.3mm_Bridged2Bar_RoundedPad1.0x1.5mm
JP88, JP89: GND_LP_SND; SolderJumper-2_P1.3mm_Open_RoundedPad1.0x1.5mm
Je3: Filter; PinHeader_1x04_P2.54mm_Vertical; LCSC C2718488; not fitted
R1, R4: 10kΩ; R_0805; Overload Voltage (Max) 150V; Tolerance ±1%; Part 0805W8F1002T5E; LCSC C17414
R8, R9: 47Ω; R_0805; Overload Voltage (Max) 150V; Tolerance ±1%; Part 0805W8F470JT5E; LCSC C17714
R11: 1Ω; R_0805; Overload Voltage (Max) 150V; Tolerance ±1%; Part 0805W8F100KT5E; LCSC C25271
R12, R13: 1.5kΩ; R_0402; Overload Voltage (Max) 50V; Tolerance ±1%; Part 0402WGF1501TCE; LCSC C25867
R30: 10Ω; R_0603; Overload Voltage (Max) 75V; Tolerance ±1%; Part 0603WAF100JT5E; LCSC C22859
R58, R59, R60, R61: 10Ω; R_0402; Overload Voltage (Max) 50V; Tolerance ±1%; Part 0402WGF100JTCE; LCSC C25077
TP6: 180; TestPoint_THTPad_D2.0mm_Drill1.0mm
TP7: 270; TestPoint_THTPad_D2.0mm_Drill1.0mm
TP10, TP12: GND; TestPoint_THTPad_D2.0mm_Drill1.0mm
TP11: VA/2; TestPoint_THTPad_D2.0mm_Drill1.0mm
TP14: 0; TestPoint_THTPad_D2.0mm_Drill1.0mm
TP16: 90; TestPoint_THTPad_D2.0mm_Drill1.0mm
TP17: I; TestPoint_THTPad_D2.0mm_Drill1.0mm
TP18: Q; TestPoint_THTPad_D2.0mm_Drill1.0mm
TR1: H1102NLT; XFMR_H1102NLT; LCSC C20623173
U5, U8: OPA1612AxD; SOIC-8_3.9x4.9mm_P1.27mm; LCSC C94590
U7: SN74CBT3253DBQR; DBQ0016A-IPC_A; LCSC C2674552
e5: Groundloop_Insurance; SolderJumper-2_P1.3mm_Bridged_RoundedPad1.0x1.5mm

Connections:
/I: C29.2, J12.R; also elsewhere on the board
/I_CLK: U7.14 (S0); also elsewhere on the board
/Q: C21.1, J12.T; also elsewhere on the board
/Q_CLK: U7.2 (S1); also elsewhere on the board
GND: C14.2, C16.2, C19.2, C20.1, C22.2, C23.1, C30.1, C31.1, C32.1, C33.2, C52.1, C82.2, JP89.1 (A), R4.1, R30.2, TP10.1 (1_1), TP12.1 (1_1), U5.4 (V-), U7.1 (1~OE), U7.8 (GND), U7.15 (2~OE), U8.4 (V-), e5.1 (A); also elsewhere on the board
unnamed: C33.1, R11.2
unnamed: J11.2 (Ext), JP1.1 (A), JP88.1 (A), JP89.2 (B), Je3.2, Je3.3
unnamed: C1.1, J11.1 (In)
unnamed: JP1.2 (B), TR1.7 (C_RD)
unnamed: C18.2, C29.1, JP9.1 (A), R12.2, TP17.1 (1_1), U8.7
unnamed: C93.2, JP9.2 (B)
unnamed: C94.2, JP10.1 (A)
unnamed: C21.2, C28.2, JP10.2 (B), R13.2, TP18.1 (1_1), U8.1
unnamed: C1.2, JP86.1 (A), Je3.1
unnamed: JP86.2 (B), Je3.4, TR1.8 (RD-)
unnamed: JP88.2 (B), TR1.6 (RD+)
unnamed: C20.2, C81.1, C82.1, C83.2, R1.1, R4.2, TP11.1 (1_1), TR1.10 (C_RX)
unnamed: TR1.11 (RX+), U7.9 (2A)
unnamed: TR1.9 (RX-), U7.7 (1A)
unnamed: R61.2, U5.3 (+)
unnamed: R8.1, U5.1, U5.2 (-)
unnamed: R58.2, U5.5 (+)
unnamed: R9.1, U5.6 (-), U5.7
unnamed: C16.1, R60.1, TP14.1 (1_1), U7.6 (1B1), U7.13 (2B4)
unnamed: C14.1, R59.1, TP16.1 (1_1), U7.5 (1B2), U7.12 (2B3)
unnamed: C22.1, R58.1, TP7.1 (1_1), U7.4 (1B3), U7.11 (2B2)
unnamed: C19.1, R61.1, TP6.1 (1_1), U7.3 (1B4), U7.10 (2B1)
unnamed: C23.2, FB3.1, U7.16 (VCC)
unnamed: R59.2, U8.3 (+)
unnamed: C28.1, C94.1, R9.2, R13.1, U8.2 (-)
unnamed: R60.2, U8.5 (+)
unnamed: C18.1, C93.1, R8.2, R12.1, U8.6 (-)
unnamed: C52.2, J12.S, R30.1, e5.2 (B)
VDDA: C30.2, C31.2, C32.2, C81.2, C83.1, FB3.2, R1.2, R11.1, U5.8 (V+), U8.8 (V+); also elsewhere on the board

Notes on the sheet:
We should switch X this transformer so the choke is on the input.
Mixer 1 or 2
Op amps picked for low noise, +/- 2.25 V supply, being in the same package, and only $1 for the package.
External Filter Option
Double check to see we corrected v0.1 mixer error....
The image rejection is vastly superior with all four mixer outputs used. See the simulations. I like the symmetry. The buffer is needed to isolate the inverting sampling capacitors.
Mixer
Scope GND connections
Amplifier/Filter

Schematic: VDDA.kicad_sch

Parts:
C2, C5, C35, C41, C42, C85, C88: 10uF; C_1206; Voltage Rated 50V; Tolerance ±10%; Part CL31A106KBHNNNE; LCSC C13585
C17, C36, C37, C89, C90: 100uF; C_CASE-B-3528-21(mm); Tolerance ±10%; Rated Voltage 6.3V; Part TAJB107K006RNJ; LCSC C16133
C40, C87: 4.7pF; C_0603; Voltage Rated 50V; Part 0603CG4R7C500NT; LCSC C1669
C43, C55, C86: 0.1u; C_0805_2012Metric; LCSC C49678
D1, D2, D3: SS14; D_SMA; Forward Voltage (Vf@If) 550mV@1A; Reverse Voltage (Vr) 40V; Part SS14; LCSC C2480
FB2: FB_0805; Current Rating 500mA; Tolerance ±25%; Part GZ2012D601TF; LCSC C1017
FB5, FB6, FB8, FB9: FB_0805; Current Rating 800mA; Tolerance ±25%; Part GZ2012D101TF; LCSC C1015
J5: Conn_01x02; PinHeader_1x02_P2.54mm_Vertical; not fitted
JP2: +0.3V; SolderJumper-2_P1.3mm_Open_RoundedPad1.0x1.5mm
Q1: AO3401A; Q_SOT-23; Part AO3401A; LCSC C15127
R5: 33kΩ; R_0805; Overload Voltage (Max) 150V; Tolerance ±1%; Part 0805W8F3302T5E; LCSC C17633
R6: 12kΩ; R_0805; Overload Voltage (Max) 150V; Tolerance ±1%; Part 0805W8F1202T5E; LCSC C17444
R7, R20, R21, R25, R73: 1Ω; R_0805; Overload Voltage (Max) 150V; Tolerance ±1%; Part 0805W8F100KT5E; LCSC C25271
R10: 27kΩ; R_0805; Overload Voltage (Max) 150V; Tolerance ±1%; Part 0805W8F2702T5E; LCSC C17593
R24: 47kΩ; R_0805; Overload Voltage (Max) 150V; Tolerance ±1%; Part 0805W8F4702T5E; LCSC C17713
R28: 100kΩ; R_0805; Overload Voltage (Max) 150V; Tolerance ±1%; Part 0805W8F1003T5E; LCSC C149504
TP25: +5; TestPoint_THTPad_D2.0mm_Drill1.0mm
TP26: VDDA; TestPoint_THTPad_D2.0mm_Drill1.0mm
TP27: 3.3V_A; TestPoint_THTPad_D2.0mm_Drill1.0mm
U6: L78M05ABDT-TR; TO-252-2_L6.5-W6.1-P4.58-LS10.0-TL; Output Voltage 5V; Part L78M05ABDT-TR; LCSC C58069
e1, e10: SGM2205-ADJXTDB8G/TR; DFN-8-1EP_3x3mm_P0.65mm_EP1.55x2.4mm; LCSC C5152847

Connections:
+3.3VA: C89.1, C90.1, FB9.2, TP27.1 (1_1); also elsewhere on the board
+4.7V: C2.1, D3.1, JP2.2 (B), Q1.3 (D), TP25.1 (1_1); also elsewhere on the board
GND: C2.2, C5.2, C17.2, C35.2, C36.2, C37.2, C41.2, C42.2, C43.2, C55.2, C85.2, C86.2, C88.2, C89.2, C90.2, J5.1, R6.2, R10.2, R28.2, U6.4 (GND), e1.7 (GND), e1.9 (PAD), e10.7 (GND), e10.9 (PAD); also elsewhere on the board
unnamed: C35.1, C40.1, R5.2, R7.1, R20.1, e1.3 (VOUT), e1.4 (VOUT)
unnamed: C42.1, D1.2, R21.1
unnamed: C87.1, C88.1, R24.2, R25.1, R73.1, e10.3 (VOUT), e10.4 (VOUT)
unnamed: D1.1, FB2.2
unnamed: FB5.1, R7.2, R20.2
unnamed: FB9.1, R25.2, R73.2
unnamed: D2.2, J5.2
unnamed: C43.1, D3.2, JP2.1 (A), U6.3 (VOUT)
unnamed: C41.1, D2.1, Q1.1 (G), R21.2, R28.1, U6.1 (VIN)
unnamed: FB2.1, FB6.1, FB8.1, Q1.2 (S)
unnamed: C5.1, C55.1, FB6.2, e1.1 (VIN), e1.2 (VIN), e1.8 (EN)
unnamed: C40.2, R5.1, R6.1, e1.6 (SENSE/ADJ)
unnamed: C85.1, C86.1, FB8.2, e10.1 (VIN), e10.2 (VIN), e10.8 (EN)
unnamed: C87.2, R10.1, R24.1, e10.6 (SENSE/ADJ)
VDDA: C17.1, C36.1, C37.1, FB5.2, TP26.1 (1_1); also elsewhere on the board

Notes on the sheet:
VDDA Regulator
We are running VDDA at 4.5V (minimum allowed).
Clean analog supply (+5 to +15 V)
This powers the Pico when we are not using USB.
This connection goes to VSYS (pico) or Vin (YD-RP2040).

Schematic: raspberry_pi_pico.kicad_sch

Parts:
C39: 10uF; C_CASE-A-3216-18(mm); Tolerance ±10%; Rated Voltage 16V; Part TAJA106K016RNJ; LCSC C7171
J2: Conn_02x20_Counter_Clockwise; PinSocket_2x20_P2.54mm_Vertical_pins1-20; LCSC C2977589
J3: Conn_02x20_Counter_Clockwise; PinSocket_2x20_P2.54mm_Vertical_Counterclockwise_pins21-40; LCSC C2977589
J4: Conn_01x20_Socket; PinSocket_1x20_P2.54mm_Vertical; LCSC C2905423
J7: Conn_01x01_Pin; PinHeader_1x01_P2.54mm_Vertical; not fitted
J10: Conn_01x20_Socket; PinSocket_1x20_P2.54mm_Vertical-pins21-40; LCSC C2905423
JP20, JP21, JP22, JP23, JP24, JP25, JP26, JP27, JP28, JP29, JP30, JP31, JP32, JP33, JP34, JP35, JP36, JP37, JP38, JP39, JP40, JP41, JP42, JP43, JP44, JP45, JP46, JP47, JP48, JP49, JP51, JP52, JP53, JP54, JP55, JP56, JP57, JP58, JP59, JP60, JP61, JP62, JP63, JP64, JP65, JP66, JP67, JP68, JP70, JP71, JP72, JP73, JP74, JP75, JP76, JP77, JP78, JP79, JP80, JP81, JP82, JP83: Jumper_2_Bridged; SolderJumper-2_P1.3mm_Bridged2Bar_RoundedPad1.0x1.5mm
JP50: USB_ONLY; SolderJumper-2_P1.3mm_Bridged2Bar_RoundedPad1.0x1.5mm
R29: 20kΩ; R_0805; Overload Voltage (Max) 150V; Tolerance ±1%; Part 0805W8F2002T5E; LCSC C4328
S1: Tactile Button, 160gf; SW_TS-1088-AR02016; Voltage Rating (Dc) 12V; Part TS-1088-AR02016; LCSC C720477
U3: Pico; RPi_Pico_SMD_TH; not fitted

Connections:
+3.3V: C39.1, J2.3 (Pin_38), J3.30, JP23.1 (A), R29.1; also elsewhere on the board
+4.7V: JP20.1 (A), JP21.1 (A), JP35.2 (B), JP50.1 (A); also elsewhere on the board
/ANG_A: JP29.1 (A); also elsewhere on the board
/ANG_B: JP30.1 (A); also elsewhere on the board
/BCK: JP78.2 (B); also elsewhere on the board
/BCK2: JP75.2 (B); also elsewhere on the board
/BTN: JP82.2 (B); also elsewhere on the board
/CS: JP68.2 (B); also elsewhere on the board
/DATA: JP77.2 (B); also elsewhere on the board
/ECHO: JP27.1 (A); also elsewhere on the board
/INA: JP26.1 (A); also elsewhere on the board
/INB: JP25.1 (A); also elsewhere on the board
/LRCK: JP33.1 (A); also elsewhere on the board
/MISO: JP67.2 (B); also elsewhere on the board
/MOSI: JP71.2 (B); also elsewhere on the board
/OSC_SCL: JP81.2 (B); also elsewhere on the board
/OSC_SDA: JP80.2 (B); also elsewhere on the board
/PICO_MCLK: JP83.2 (B); also elsewhere on the board
/RGB_DIN: JP31.1 (A); also elsewhere on the board
/Raspberry_Pi_Pico/3V3_EN: JP22.1 (A)
/Raspberry_Pi_Pico/ADC_VREF: JP24.1 (A)
/Raspberry_Pi_Pico/RST: J10.30 (Pin_11), R29.2, S1.1 (A), U3.30 (RUN)
/SCLK: JP34.1 (A); also elsewhere on the board
/SD2: JP74.2 (B); also elsewhere on the board
/SDIN: JP32.1 (A); also elsewhere on the board
/SD_CD: JP72.2 (B); also elsewhere on the board
/SPI_CK: JP70.2 (B); also elsewhere on the board
/SW_C: JP73.2 (B); also elsewhere on the board
/TRIG: JP28.1 (A); also elsewhere on the board
/WS: JP79.2 (B); also elsewhere on the board
/WS2: JP76.2 (B); also elsewhere on the board
GND: C39.2, J2.8, J2.13, J2.18, J3.23, J3.28, J3.33 (Pin_8), J3.38 (Pin_3), J4.3, J4.8, J4.13, J4.18, J10.23 (Pin_18), J10.28 (Pin_13), J10.33 (Pin_8), J10.38 (Pin_3), S1.2 (B), U3.3 (GND), U3.8 (GND), U3.13 (GND), U3.18 (GND), U3.23 (GND), U3.28 (GND), U3.33 (AGND), U3.38 (GND); also elsewhere on the board
unnamed: J2.1, JP51.2 (B), JP67.1 (A)
unnamed: J2.2, JP52.2 (B), JP68.1 (A)
unnamed: J2.10, JP58.2 (B), JP75.1 (A)
unnamed: J2.11, JP59.2 (B), JP76.1 (A)
unnamed: J2.12, JP60.2 (B), JP77.1 (A)
unnamed: J2.14, JP61.2 (B), JP78.1 (A)
unnamed: J2.15, JP62.2 (B), JP79.1 (A)
unnamed: J2.16, JP63.2 (B), JP80.1 (A)
unnamed: J2.17, JP64.2 (B), JP81.1 (A)
unnamed: J2.19, JP65.2 (B), JP82.1 (A)
unnamed: J2.20, JP66.2 (B), JP83.1 (A)
unnamed: J2.9, JP57.2 (B), JP74.1 (A)
unnamed: J2.7, JP56.2 (B), JP73.1 (A)
unnamed: J2.6, JP55.2 (B), JP72.1 (A)
unnamed: J2.5, JP54.2 (B), JP71.1 (A)
unnamed: J2.4, JP53.2 (B), JP70.1 (A)
unnamed: J3.40 (Pin_1), JP20.2 (B), JP35.1 (A)
unnamed: J3.39 (Pin_2), JP21.2 (B), JP36.1 (A)
unnamed: J3.31 (Pin_10), JP27.2 (B), JP42.1 (A)
unnamed: J3.29 (Pin_12), JP28.2 (B), JP43.1 (A)
unnamed: J3.27 (Pin_14), JP29.2 (B), JP44.1 (A)
unnamed: J3.26 (Pin_15), JP30.2 (B), JP45.1 (A)
unnamed: J3.25 (Pin_16), JP31.2 (B), JP46.1 (A)
unnamed: J3.24 (Pin_17), JP32.2 (B), JP47.1 (A)
unnamed: J3.22 (Pin_19), JP33.2 (B), JP48.1 (A)
unnamed: J3.21 (Pin_20), JP34.2 (B), JP49.1 (A)
unnamed: J3.32 (Pin_9), JP26.2 (B), JP41.1 (A)
unnamed: J3.34 (Pin_7), JP25.2 (B), JP40.1 (A)
unnamed: J3.35 (Pin_6), JP24.2 (B), JP39.1 (A)
unnamed: J3.36 (Pin_5), JP23.2 (B), JP38.1 (A)
unnamed: J3.37 (Pin_4), JP22.2 (B), JP37.1 (A)
unnamed: J4.1, JP51.1 (A), U3.1 (GPIO0)
unnamed: J4.2, JP52.1 (A), U3.2 (GPIO1)
unnamed: J4.4, JP53.1 (A), U3.4 (GPIO2)
unnamed: J4.5, JP54.1 (A), U3.5 (GPIO3)
unnamed: J4.6, JP55.1 (A), U3.6 (GPIO4)
unnamed: J4.7, JP56.1 (A), U3.7 (GPIO5)
unnamed: J4.9, JP57.1 (A), U3.9 (GPIO6)
unnamed: J4.10, JP58.1 (A), U3.10 (GPIO7)
unnamed: J4.11, JP59.1 (A), U3.11 (GPIO8)
unnamed: J4.12, JP60.1 (A), U3.12 (GPIO9)
unnamed: J4.14, JP61.1 (A), U3.14 (GPIO10)
unnamed: J4.15, JP62.1 (A), U3.15 (GPIO11)
unnamed: J4.16, JP63.1 (A), U3.16 (GPIO12)
unnamed: J4.17, JP64.1 (A), U3.17 (GPIO13)
unnamed: J4.19, JP65.1 (A), U3.19 (GPIO14)
unnamed: J4.20, JP66.1 (A), U3.20 (GPIO15)
unnamed: J7.1 (Pin_1_1), J10.40 (Pin_1), JP50.2 (B), U3.40 (VBUS)
unnamed: J10.39 (Pin_2), JP36.2 (B), U3.39 (VSYS)
unnamed: J10.37 (Pin_4), JP37.2 (B), U3.37 (3V3_EN)
unnamed: J10.36 (Pin_5), JP38.2 (B), U3.36 (3V3)
unnamed: J10.35 (Pin_6), JP39.2 (B), U3.35 (ADC_VREF)
unnamed: J10.34 (Pin_7), JP40.2 (B), U3.34 (GPIO28_ADC2)
unnamed: J10.32 (Pin_9), JP41.2 (B), U3.32 (GPIO27_ADC1)
unnamed: J10.31 (Pin_10), JP42.2 (B), U3.31 (GPIO26_ADC0)
unnamed: J10.29 (Pin_12), JP43.2 (B), U3.29 (GPIO22)
unnamed: J10.27 (Pin_14), JP44.2 (B), U3.27 (GPIO21)
unnamed: J10.26 (Pin_15), JP45.2 (B), U3.26 (GPIO20)
unnamed: J10.25 (Pin_16), JP46.2 (B), U3.25 (GPIO19)
unnamed: J10.24 (Pin_17), JP47.2 (B), U3.24 (GPIO18)
unnamed: J10.22 (Pin_19), JP48.2 (B), U3.22 (GPIO17)
unnamed: J10.21 (Pin_20), JP49.2 (B), U3.21 (GPIO16)

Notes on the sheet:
J2 and J3 allow you to connect Dupont connectors to other external modules.
Students can connect their modules to GPIO7-22.
RST here is redundant if using a YD-RP2040.
V+ (YD-RP2040) VBUS (Pico)
If you are using a real Pico, this jumper bridges a Schottky diode from USB in to Vsys (4.7v with it open, 5.0v from USB port with it soldered)
These jumpers are for changing GPIO pins if necessary. They also allow you to connect modules similar to a breadboard.
For the YD-RP2040 we want the USB Only jumper shorted.
Renumber the footprint pin numbers for J2, J3 and J4.

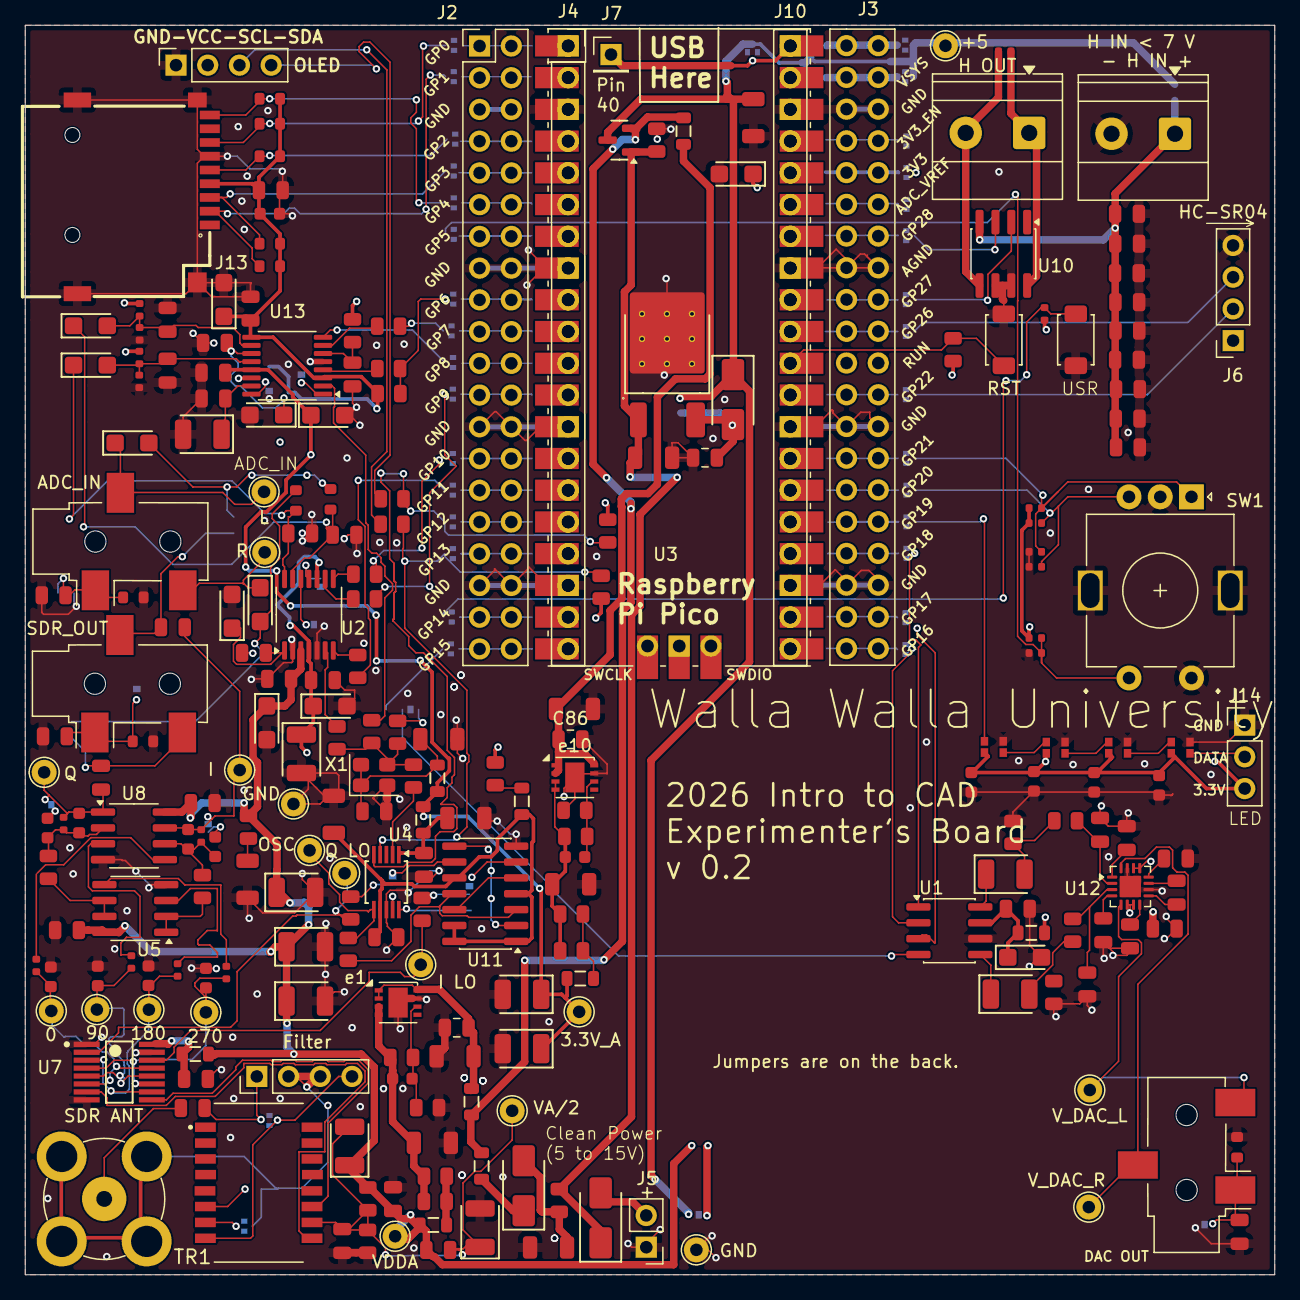
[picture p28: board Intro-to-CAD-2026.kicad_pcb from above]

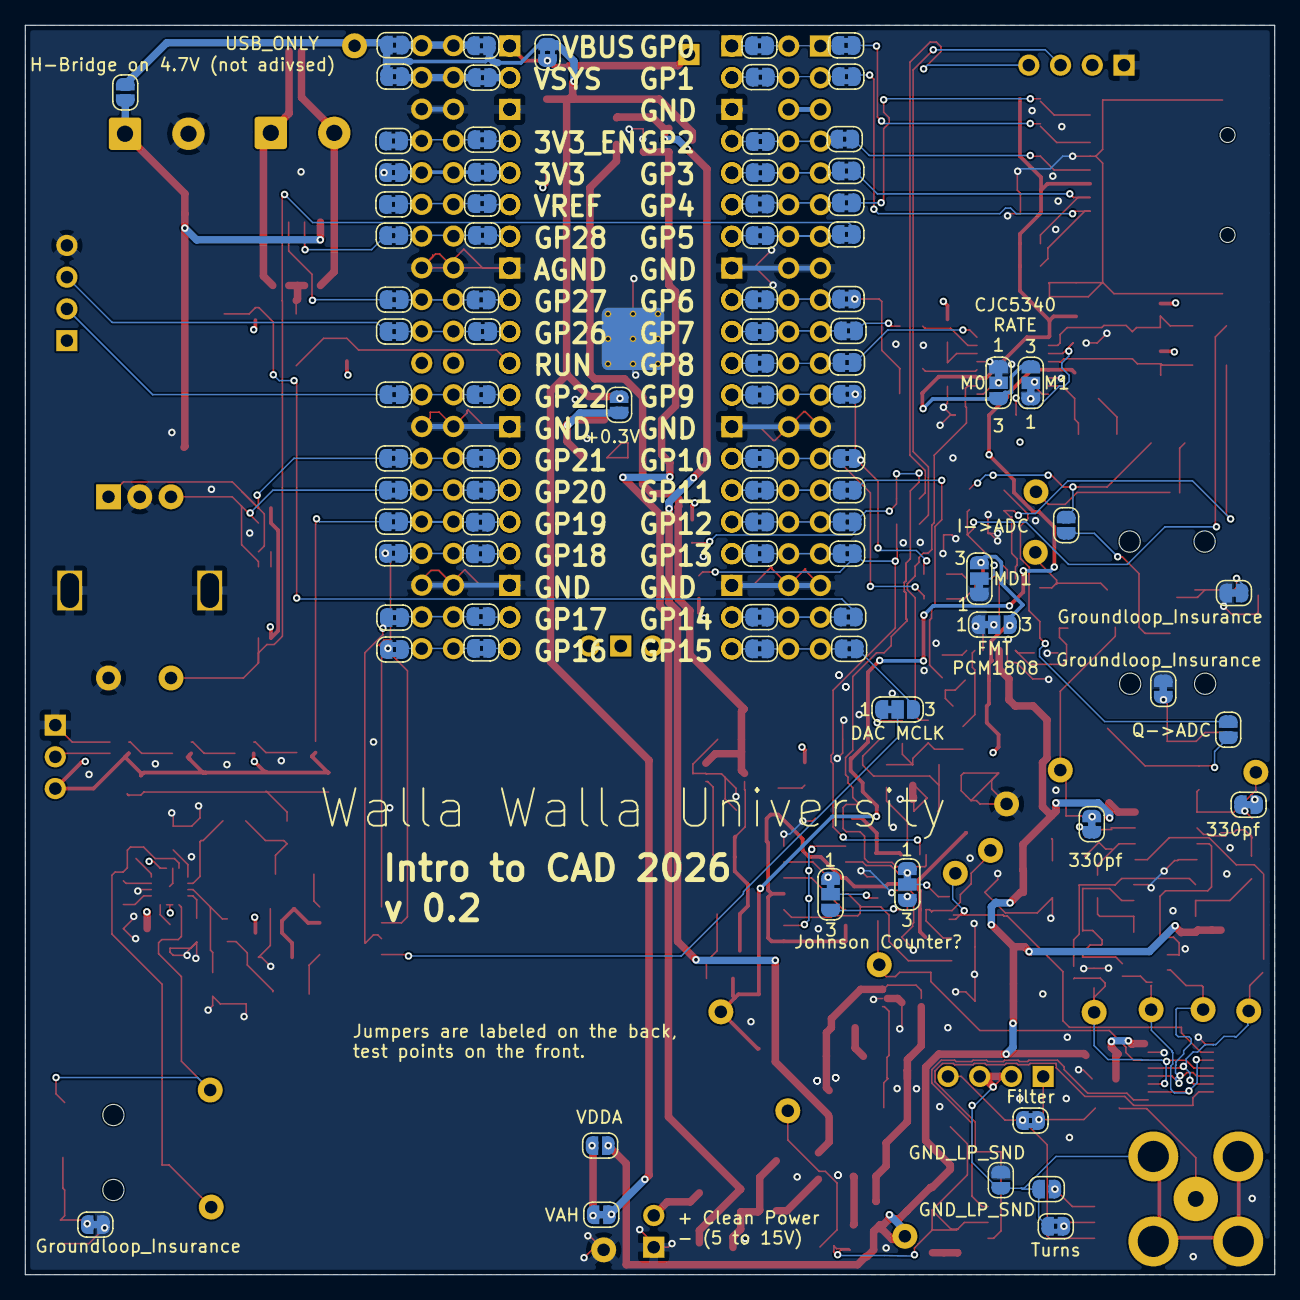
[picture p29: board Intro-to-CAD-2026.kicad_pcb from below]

Board: 4 copper layers, 100.0 x 100.0 mm, 323 parts (85 on the bottom side), 208 nets.

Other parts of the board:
C62: 100nF; C_0402
C64, C65: 10nF; C_0402
C66: 10uF; C_0805
C67, C68, C69, C70, C71: 100nF; C_0603
D8, D9, D10, D11: XL-0807RGBC-2812B; C3646929e
J6: HC-SR04; PinSocket_1x04_P2.54mm_Vertical
J13: Micro_SD-TF_PUSH; TF-SMD_TF-PUSH
J14: Conn_01x03; PinHeader_1x03_P2.54mm_Vertical
R57, R63, R64, R70: 10kΩ; R_0402
R65, R66, R67, R68, R69: 10kΩ; R_0603
S2: Tactile Button, 160gf; SW_TS-1088-AR02016
SW1: RotaryEncoder_Switch_MP; RotaryEncoder_Alps_EC11E-Switch_Vertical_H20mm

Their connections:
+3.3V: C66.1, C67.1, C68.2, C69.2, C70.2, C71.2, D8.4 (VDD), D9.4 (VDD), D10.4 (VDD), D11.4 (VDD), J6.1, J13.4 (VDD), J14.3, R57.1, R63.1, R64.1, R65.2, R66.2, R67.1, R68.1, R69.2, R70.1; also elsewhere on the board
/ANG_A: C64.1, R63.2, SW1.A; also elsewhere on the board
/ANG_B: C65.1, R64.2, SW1.B; also elsewhere on the board
/BTN: R70.2, S2.2 (B); also elsewhere on the board
/CS: J13.2 (DAT3/CS), R68.2; also elsewhere on the board
/ECHO: J6.3; also elsewhere on the board
/MISO: J13.7 (DAT0/SO), R67.2; also elsewhere on the board
/MOSI: J13.3 (CMD/SI), R66.1; also elsewhere on the board
/RGB_DIN: D8.3 (DIN); also elsewhere on the board
/SD_CD: J13.CD (DET), R69.1; also elsewhere on the board
/SPI_CK: J13.5 (CLK), R65.1; also elsewhere on the board
/SW_C: C62.1, R57.2, SW1.S1; also elsewhere on the board
/TRIG: J6.2; also elsewhere on the board
GND: C62.2, C64.2, C65.2, C66.2, C67.2, C68.1, C69.1, C70.1, C71.1, D8.2 (GND), D9.2 (GND), D10.2 (GND), D11.2 (GND), J6.4, J13.6 (VSS), J13.10 (SHIELD), J13.11 (SHIELD), J13.12 (SHIELD), J13.13 (SHIELD), J14.1, S2.1 (A), SW1.C, SW1.MP, SW1.S2; also elsewhere on the board
unnamed: D8.1 (DOUT), D9.3 (DIN)
unnamed: D9.1 (DOUT), D10.3 (DIN)
unnamed: D10.1 (DOUT), D11.3 (DIN)
unnamed: D11.1 (DOUT), J14.2

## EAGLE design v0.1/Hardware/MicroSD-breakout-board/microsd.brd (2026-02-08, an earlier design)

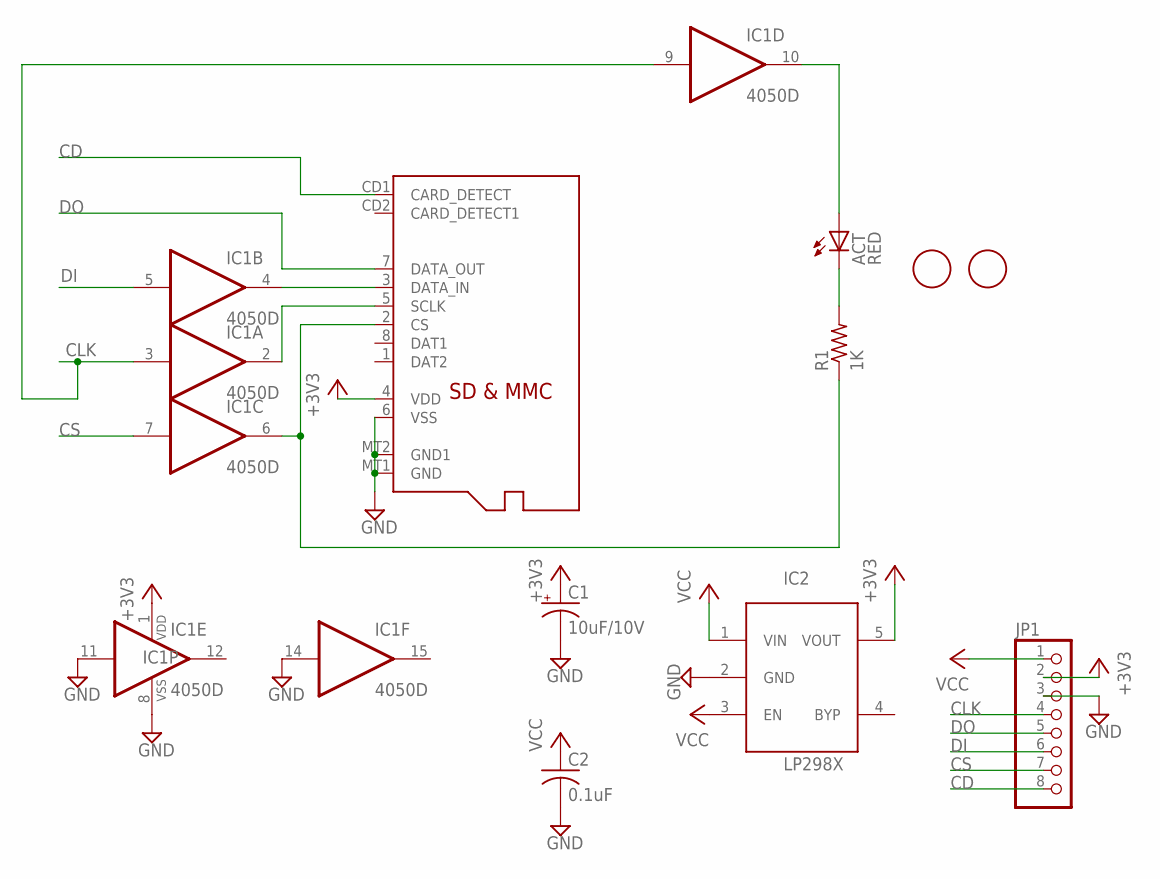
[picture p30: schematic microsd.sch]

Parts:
ACT: RED; CHIP-LED0805
C1: 10uF/10V; A/3216-18R
C2: 0.1uF; C0805K
IC1: 4050D; SO16
IC2: LP298XS; SOT23-5L
JP1: PINHD-1X8BIG; 1X08-BIG
R1: 1K; R0805
U$1, U$2: FIDUCIAL; FIDUCIAL_1MM
X1: MICROSD

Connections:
+3V3: C1.+, IC1.1 (VDD), IC2.5 (VOUT), JP1.2, X1.4 (VDD)
CD: JP1.8, X1.CD1 (CARD_DETECT)
CLK: IC1.3 (I), IC1.9 (I), JP1.4
CS: IC1.7 (I), JP1.7
DI: IC1.5 (I), JP1.6
DO: JP1.5, X1.7 (DATA_OUT)
GND: C1.-, C2.2, IC1.8 (VSS), IC1.11 (I), IC1.14 (I), IC2.2 (GND), JP1.3, X1.6 (VSS), X1.MT1 (GND), X1.MT2 (GND1)
unnamed: ACT.A, IC1.10 (O)
unnamed: IC1.2 (O), X1.5 (SCLK)
unnamed: IC1.6 (O), R1.1, X1.2 (CS)
unnamed: ACT.C, R1.2
unnamed: IC1.4 (O), X1.3 (DATA_IN)
VCC: C2.1, IC2.1 (VIN), IC2.3 (EN), JP1.1

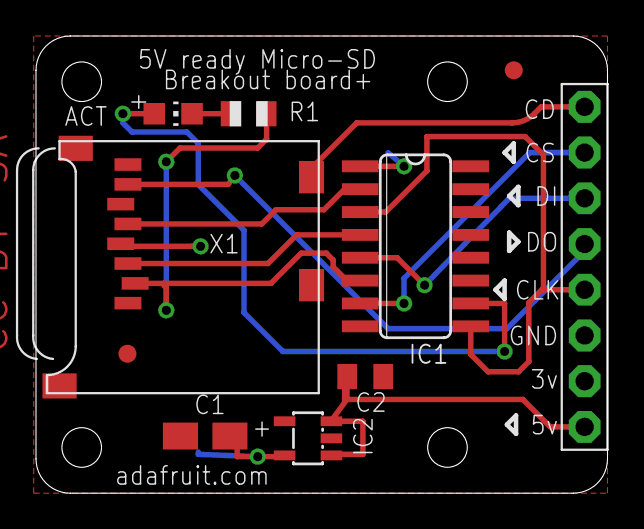
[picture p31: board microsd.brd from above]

Board: 2 copper layers, 31.8 x 25.4 mm, 10 parts (0 on the bottom side), 13 nets.

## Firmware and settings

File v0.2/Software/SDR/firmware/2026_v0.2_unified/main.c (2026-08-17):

/*
 * main.c -- Unified RP2040 / Pico W SDR Firmware (v0.2)
 *
 * Features:
 *   • Dual Streaming: USB Audio Class 1.0 (UAC1) + OpenHPSDR Protocol 1 over WiFi
 *   • Autonomous On-Board Si5351 LO calculation (Golden Integer & Fractional fallback)
 *   • Dual FREQ command support:
 *       1. Legacy Quisk format: FREQ,<hz>,<N>,<a>,<b>,<c>,<P1>,<P2>,<P3>
 *       2. Direct frequency:    FREQ,<hz>  (computes best LO on-chip)
 *   • Sample Rate switching: 48 kHz (M1=0) / 96 kHz (M1=1) dynamically
 *   • TCP Control Server on Port 5000 in parallel with USB CDC
 */

#include <stdio.h>
#include <stdlib.h>
#include <string.h>
#include <stdint.h>

#include "bsp/board_api.h"
#include "tusb.h"

#include "hardware/vreg.h"
#include "hardware/clocks.h"
#include "hardware/i2c.h"
#include "hardware/gpio.h"
#include "hardware/pio.h"
#include "hardware/dma.h"
#include "hardware/irq.h"
#include "hardware/flash.h"
#include "hardware/sync.h"
#include "pico/multicore.h"
#include "pico/cyw43_arch.h"
#include "lwip/tcp.h"

#include "i2s_rx.pio.h"
#include "si5351.h"
#include "openhpsdr.h"
#include "wifi_config.h"

/* GPIO pin assignments */
#define I2C_SDA_PIN    12
#define I2C_SCL_PIN    13
#define MODE_M0_PIN    22   /* PCM1808 MD0: held LOW (I2S format) */
#define MODE_M1_PIN    26   /* PCM1808 MD1: 0=48kHz, 1=96kHz      */

#define PCM_DATA_PIN   9
#define PCM_BCK_PIN    10
#define PCM_WS_PIN     11

#define I2C_SPEED_HZ   100000U
#define BOARD_DIRECT_MODE true

#define MAX_WORDS_PER_BUF  192

static uint32_t buf_a[MAX_WORDS_PER_BUF];
static uint32_t buf_b[MAX_WORDS_PER_BUF];

static volatile uint32_t g_words_per_buf = 96;    /* default 48 kHz */
static volatile uint32_t g_sample_rate   = 48000U;
static uint g_pio_offset = 0;

static int dma_chan_a;
static int dma_chan_b;

/* CDC / TCP line buffer */
#define LINE_BUF_LEN  128
static char    s_line[LINE_BUF_LEN];
static uint8_t s_line_len = 0;
static bool    s_sdr_ready_sent = false;

static uint32_t s_last_hz   = 7050000;
static char     s_last_type = 'G';
static lo_calc_mode_t s_lo_mode = LO_MODE_BEST_INTEGER;

/* UAC1 state */
static uint8_t  s_audio_alt      = 0;
static uint32_t s_sample_rate_hz = 48000U;
static uint8_t  s_mute[3]        = {0, 0, 0};

/* Forward declarations */
static void apply_sample_rate(uint32_t rate);
static void handle_line(const char *line, uint8_t len, void (*reply_fn)(const char *));
static void cdc_write(const char *s);

/* WiFi SSID and Password state */
static char s_wifi_ssid[64] = DEFAULT_WIFI_SSID;
static char s_wifi_pass[64] = DEFAULT_WIFI_PASSWORD;

/* TCP Control Server */
static struct tcp_pcb *s_tcp_server_pcb = NULL;
static struct tcp_pcb *s_active_tcp_client = NULL;

static void tcp_write_str(const char *s) {
    if (s_active_tcp_client) {
        tcp_write(s_active_tcp_client, s, (u16_t)strlen(s), TCP_WRITE_FLAG_COPY);
        tcp_output(s_active_tcp_client);
    }
}

/* ======================================================================
 * Core 1: owns DMA IRQ, handles rate-reconfiguration sentinel
 * ====================================================================== */
static void dma_handler(void) {
    const uint32_t *filled_buf;
    uint32_t wpb = g_words_per_buf;

    if (dma_hw->ints0 & (1u << dma_chan_a)) {
        dma_hw->ints0 = 1u << dma_chan_a;
        filled_buf = buf_a;
        dma_channel_set_write_addr(dma_chan_a, buf_a, false);
        dma_channel_set_trans_count(dma_chan_a, wpb, false);
    } else {
        dma_hw->ints0 = 1u << dma_chan_b;
        filled_buf = buf_b;
        dma_channel_set_write_addr(dma_chan_b, buf_b, false);
        dma_channel_set_trans_count(dma_chan_b, wpb, false);
    }
    multicore_fifo_push_timeout_us((uint32_t)(uintptr_t)filled_buf, 0);
}

static void pio_configure_pcm1808(void) {
    pio_gpio_init(pio0, PCM_DATA_PIN);
    gpio_pull_up(PCM_DATA_PIN);
    pio_gpio_init(pio0, PCM_BCK_PIN);
    gpio_pull_up(PCM_BCK_PIN);
    pio_gpio_init(pio0, PCM_WS_PIN);
    gpio_pull_up(PCM_WS_PIN);

    pio_sm_set_consecutive_pindirs(pio0, 0, PCM_DATA_PIN, 3, false);

    pio_sm_config c = i2s_rx_program_get_default_config(g_pio_offset);
    sm_config_set_in_pins(&c, PCM_DATA_PIN);
    sm_config_set_in_shift(&c, false, true, 32);
    sm_config_set_clkdiv(&c, 1.0f);
    pio_sm_init(pio0, 0, g_pio_offset, &c);
}

static void core1_entry(void) {
    multicore_fifo_drain();

    dma_channel_set_irq0_enabled(dma_chan_a, true);
    dma_channel_set_irq0_enabled(dma_chan_b, true);
    irq_set_exclusive_handler(DMA_IRQ_0, dma_handler);
    irq_set_enabled(DMA_IRQ_0, true);

    dma_channel_start(dma_chan_a);

    while (true) {
        uint32_t msg;
        if (multicore_fifo_pop_timeout_us(0, &msg)) {
            if (msg == 0xFFFFFFFFu) {
                irq_set_enabled(DMA_IRQ_0, false);
                dma_channel_abort(dma_chan_a);
                dma_channel_abort(dma_chan_b);

                pio_sm_set_enabled(pio0, 0, false);
                pio_sm_clear_fifos(pio0, 0);

                pio_configure_pcm1808();

                pio_sm_restart(pio0, 0);
                pio_sm_exec(pio0, 0, pio_encode_jmp(g_pio_offset));
                pio_sm_set_enabled(pio0, 0, true);

                uint32_t wpb = g_words_per_buf;
                dma_channel_set_write_addr(dma_chan_a, buf_a, false);
                dma_channel_set_trans_count(dma_chan_a, wpb, false);
                dma_channel_set_write_addr(dma_chan_b, buf_b, false);
                dma_channel_set_trans_count(dma_chan_b, wpb, false);

                irq_set_enabled(DMA_IRQ_0, true);
                dma_channel_start(dma_chan_a);
                multicore_fifo_push_blocking(0xFFFFFFFEu);
            }
        }
        tight_loop_contents();
    }
}

/* ======================================================================
 * Hardware Reconfiguration
 * ====================================================================== */
static void apply_hardware_config(uint32_t rate) {
    gpio_put(MODE_M0_PIN, 0);
    if (rate >= 96000U) {
        gpio_put(MODE_M1_PIN, 1);
        g_words_per_buf = 192;
        g_sample_rate   = 96000U;
    } else {
        gpio_put(MODE_M1_PIN, 0);
        g_words_per_buf = 96;
        g_sample_rate   = 48000U;
    }
}

static void restart_pio_dma(void) {
    multicore_fifo_push_blocking(0xFFFFFFFFu);
    uint32_t ack = 0;
    while (!multicore_fifo_pop_timeout_us(100000, &ack) || ack != 0xFFFFFFFEu)
        tight_loop_contents();
}

static void apply_sample_rate(uint32_t rate) {
    if (rate != 48000U && rate != 96000U) return;
    if (rate == g_sample_rate) return;
    apply_hardware_config(rate);
    restart_pio_dma();
}

/* ======================================================================
 * Audio Stream Tasks (Core 0: USB + OpenHPSDR)
 * ====================================================================== */
void audio_task(void) {
    uint32_t ptr_val = 0;
    while (multicore_fifo_pop_timeout_us(0, &ptr_val)) {
        if (ptr_val == 0) continue;

        const uint32_t *src = (const uint32_t *)(uintptr_t)ptr_val;
        uint32_t wpb = g_words_per_buf;

        // 1. Stream via OpenHPSDR Protocol 1 if network client is connected
        if (openhpsdr_is_active()) {
            openhpsdr_push_samples(src, wpb);
        }

        // 2. Stream via USB Audio Class 1.0 if USB host is listening
        if (tud_audio_mounted() && s_audio_alt > 0) {
            tu_fifo_t *ff = tud_audio_get_ep_in_ff();
            if (ff) {
                static uint8_t packed[MAX_WORDS_PER_BUF * 3];
                for (uint32_t i = 0; i < wpb; i++) {
                    uint32_t w = src[i] << 1;
                    packed[3*i+0] = (uint8_t)(w >>  8);
                    packed[3*i+1] = (uint8_t)(w >> 16);
                    packed[3*i+2] = (uint8_t)(w >> 24);
                }
                uint32_t bytes = wpb * 3u;
                if (tu_fifo_remaining(ff) >= bytes) {
                    tud_audio_write(packed, (uint16_t)bytes);
                }
            }
        }
    }
}

/* ======================================================================
 * OpenHPSDR Callbacks (Deferred execution to protect lwIP & prevent audio stalls)
 * ====================================================================== */
static volatile uint32_t s_pending_freq_hz = 0;
static volatile uint32_t s_pending_rate_hz = 0;

static void on_hpsdr_freq_change(uint32_t freq_hz) {
    s_pending_freq_hz = freq_hz;
}

static void on_hpsdr_rate_change(uint32_t rate_hz) {
    if (rate_hz == 48000U || rate_hz == 96000U) {
        if (rate_hz != g_sample_rate) {
            s_pending_rate_hz = rate_hz;
        }
    }
}

static void service_hpsdr_pending_tuning(void) {
    if (s_pending_rate_hz != 0) {
        uint32_t rate = s_pending_rate_hz;
        s_pending_rate_hz = 0;
        apply_sample_rate(rate);
    }
    if (s_pending_freq_hz != 0) {
        uint32_t freq = s_pending_freq_hz;
        s_pending_freq_hz = 0;
        if (freq != s_last_hz) {
            lo_candidate_t cand;
            if (si5351_tune_frequency(i2c0, freq, g_sample_rate, BOARD_DIRECT_MODE, LO_MODE_FRACTIONAL_EXACT, &cand)) {
                s_last_hz = freq;
                s_last_type = cand.ptype;
            }
        }
    }
}

/* ======================================================================
 * Command Parser (Handles both USB CDC and TCP Sockets)
 * ====================================================================== */
static void cdc_write(const char *s) {
    tud_cdc_write_str(s);
    tud_cdc_write_flush();
}

static void handle_line(const char *raw_line, uint8_t raw_len, void (*reply_fn)(const char *))
{
    if (raw_len == 0) return;
    
    // Trim leading whitespace/newlines
    uint8_t start = 0;
    while (start < raw_len && (raw_line[start] == ' ' || raw_line[start] == '\t' || raw_line[start] == '\r' || raw_line[start] == '\n')) {
        start++;
    }
    if (start >= raw_len) return;

    // Copy and trim trailing whitespace/CR/LF
    char line[LINE_BUF_LEN];
    uint8_t len = 0;
    for (uint8_t i = start; i < raw_len && len < sizeof(line) - 1; i++) {
        char c = raw_line[i];
        if (c != '\r' && c != '\n') {
            line[len++] = c;
        }
    }
    while (len > 0 && (line[len - 1] == ' ' || line[len - 1] == '\t')) {
        len--;
    }
    line[len] = '\0';
    if (len == 0) return;

    // Create uppercase version for case-insensitive matching
    char upper_line[LINE_BUF_LEN];
    for (uint8_t i = 0; i <= len; i++) {
        char c = line[i];
        upper_line[i] = (c >= 'a' && c <= 'z') ? (c - 32) : c;
    }

    char reply[128];

    if (strncmp(upper_line, "VER", 3) == 0) {
        reply_fn("VER,0.2\r\nOK\r\n");
        return;
    }
    if (strncmp(upper_line, "HELP", 4) == 0 || strcmp(upper_line, "?") == 0) {
        reply_fn("Commands: WIFI?, WIFI,ssid,pass, FREQ,hz, RATE,48000, MODE, VER\r\nOK\r\n");
        return;
    }
    if (strncmp(upper_line, "MODE", 4) == 0) {
        reply_fn(BOARD_DIRECT_MODE ? "MODE,DIRECT\r\nOK\r\n" : "MODE,JOHNSON\r\nOK\r\n");
        return;
    }
    // WiFi Status and Configuration: WIFI? or WIFI or WIFI,SSID,PASS
    if (strncmp(upper_line, "WIFI?", 5) == 0 || strcmp(upper_line, "WIFI") == 0) {
        int status = cyw43_wifi_link_status(&cyw43_state, CYW43_ITF_STA);
        const char *st_str = "DOWN";
        if (status == CYW43_LINK_JOIN) st_str = "JOINING";
        else if (status == CYW43_LINK_NOIP) st_str = "NO_IP";
        else if (status == CYW43_LINK_UP) st_str = "CONNECTED";
        else if (status == CYW43_LINK_FAIL) st_str = "AUTH_FAILED";
        else if (status == CYW43_LINK_NONET) st_str = "NO_NETWORK";
        else if (status == CYW43_LINK_BADAUTH) st_str = "BAD_AUTH";

        uint8_t *ip = (uint8_t*)&(cyw43_state.netif[CYW43_ITF_STA].ip_addr.addr);
        snprintf(reply, sizeof(reply), "WIFI,%s,IP:%u.%u.%u.%u,SSID:%s\r\nOK\r\n",
                 st_str, ip[0], ip[1], ip[2], ip[3], s_wifi_ssid);
        reply_fn(reply);
        return;
    }
    if (strncmp(upper_line, "WIFI,", 5) == 0) {
        // Syntax: WIFI,<SSID>,<PASSWORD> (case sensitive SSID/Password preserved from original line)
        char buf[LINE_BUF_LEN];
        strncpy(buf, line + 5, sizeof(buf) - 1);
        buf[sizeof(buf) - 1] = '\0';
        char *ssid = strtok(buf, ",");
        char *pass = strtok(NULL, ",");
        if (ssid) {
            strncpy(s_wifi_ssid, ssid, sizeof(s_wifi_ssid) - 1);
            s_wifi_ssid[sizeof(s_wifi_ssid) - 1] = '\0';
            if (pass) {
                strncpy(s_wifi_pass, pass, sizeof(s_wifi_pass) - 1);
                s_wifi_pass[sizeof(s_wifi_pass) - 1] = '\0';
            } else {
                s_wifi_pass[0] = '\0';
            }
            uint32_t auth = (s_wifi_pass[0] == '\0') ? CYW43_AUTH_OPEN : CYW43_AUTH_WPA2_AES_PSK;
            const char *pass_param = (s_wifi_pass[0] == '\0') ? NULL : s_wifi_pass;
            cyw43_arch_wifi_connect_async(s_wifi_ssid, pass_param, auth);
            snprintf(reply, sizeof(reply), "WIFI,CONNECTING,%s\r\nOK\r\n", s_wifi_ssid);
            reply_fn(reply);
        } else {
            reply_fn("ERROR,invalid wifi format\r\n");
        }
        return;
    }
    if (strncmp(upper_line, "RATE,", 5) == 0) {
        uint32_t r = (uint32_t)strtoul(line + 5, NULL, 10);
        if (r == 48000U || r == 96000U) {
            apply_sample_rate(r);
            snprintf(reply, sizeof(reply), "RATE,%lu\r\nOK\r\n", (unsigned long)r);
            reply_fn(reply);
        } else {
            reply_fn("ERROR,unsupported rate\r\n");
        }
        return;
    }
    // LO Mode Selection: LOMODE,BEST | LOMODE,MID | LOMODE,WORST | LOMODE,FRAC
    if (strncmp(upper_line, "LOMODE,", 7) == 0) {
        if (strncmp(upper_line + 7, "BEST", 4) == 0) s_lo_mode = LO_MODE_BEST_INTEGER;
        else if (strncmp(upper_line + 7, "MID", 3) == 0) s_lo_mode = LO_MODE_MIDDLE_INTEGER;
        else if (strncmp(upper_line + 7, "WORST", 5) == 0) s_lo_mode = LO_MODE_WORST_INTEGER;
        else if (strncmp(upper_line + 7, "FRAC", 4) == 0) s_lo_mode = LO_MODE_FRACTIONAL_EXACT;
        reply_fn("OK\r\n");
        return;
    }
    // Query current frequency: FREQ, or FREQ
    if (strcmp(upper_line, "FREQ,") == 0 || strcmp(upper_line, "FREQ") == 0) {
        snprintf(reply, sizeof(reply), "%lu\r\nOK,%c,0\r\n", (unsigned long)s_last_hz, s_last_type);
        reply_fn(reply);
        return;
    }
    // Single-parameter Tune Command: FREQ,<hz>  (e.g., FREQ,7050000)
    if (strncmp(upper_line, "FREQ,", 5) == 0) {
        // Count commas to see if it's direct frequency or full register dump
        int commas = 0;
        for (int i = 0; line[i]; i++) if (line[i] == ',') commas++;

        if (commas == 1) {
            uint32_t target_hz = (uint32_t)strtoul(line + 5, NULL, 10);
            lo_candidate_t cand;
            if (si5351_tune_frequency(i2c0, target_hz, g_sample_rate, BOARD_DIRECT_MODE, s_lo_mode, &cand)) {
                s_last_hz = target_hz;
                s_last_type = cand.ptype;
                snprintf(reply, sizeof(reply), "%lu\r\nOK,%c,%ld\r\n",
                         (unsigned long)cand.actual_hz, cand.ptype, (long)cand.offset_hz);
                reply_fn(reply);
            } else {
                reply_fn("ERR\r\n");
            }
            return;
        }

        // Full 8-parameter register format (Legacy Quisk compatibility)
        char buf[LINE_BUF_LEN];
        strncpy(buf, line, LINE_BUF_LEN - 1);
        buf[LINE_BUF_LEN - 1] = '\0';

        char *tok = strtok(buf, ",");  if (!tok) goto bad_freq;
        tok = strtok(NULL, ",");       if (!tok) goto bad_freq;
        uint32_t hz = (uint32_t)strtoul(tok, NULL, 10);
        tok = strtok(NULL, ",");       if (!tok) goto bad_freq;
        uint32_t N  = (uint32_t)strtoul(tok, NULL, 10);
        tok = strtok(NULL, ",");       if (!tok) goto bad_freq;
        tok = strtok(NULL, ",");       if (!tok) goto bad_freq;
        uint32_t b  = (uint32_t)strtoul(tok, NULL, 10);
        tok = strtok(NULL, ",");       if (!tok) goto bad_freq;
        tok = strtok(NULL, ",");       if (!tok) goto bad_freq;
        uint32_t P1 = (uint32_t)strtoul(tok, NULL, 10);
        tok = strtok(NULL, ",");       if (!tok) goto bad_freq;
        uint32_t P2 = (uint32_t)strtoul(tok, NULL, 10);
        tok = strtok(NULL, ",");       if (!tok) goto bad_freq;
        uint32_t P3 = (uint32_t)strtoul(tok, NULL, 10);

        si5351_set_freq_regs(i2c0, N, P1, P2, P3, BOARD_DIRECT_MODE);

        char ptype = (b == 0) ? 'G' : 'F';
        s_last_hz   = hz;
        s_last_type = ptype;

        snprintf(reply, sizeof(reply), "%lu\r\nOK,%c,0\r\n", (unsigned long)hz, ptype);
        reply_fn(reply);
        return;

    bad_freq:
        reply_fn("ERR\r\n");
        return;
    }

    reply_fn("ERR\r\n");
}
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
int main(void)
{
    /* Initialize TinyUSB / Board */
    board_init();

    tusb_rhport_init_t dev_init = {
        .role  = TUSB_ROLE_DEVICE,
        .speed = TUSB_SPEED_AUTO
    };
    tusb_init(BOARD_TUD_RHPORT, &dev_init);

    /* GPIO Setup for Mode Pins */
    gpio_init(MODE_M0_PIN);
    gpio_set_dir(MODE_M0_PIN, GPIO_OUT);
    gpio_put(MODE_M0_PIN, 0);

    gpio_init(MODE_M1_PIN);
    gpio_set_dir(MODE_M1_PIN, GPIO_OUT);
    gpio_put(MODE_M1_PIN, 0);

    /* PIO I2S Pins */
    for (int pin = PCM_DATA_PIN; pin <= PCM_WS_PIN; pin++) {
        pio_gpio_init(pio0, pin);
        gpio_pull_up(pin);
    }
    pio_sm_set_consecutive_pindirs(pio0, 0, PCM_DATA_PIN, 3, false);

    /* I2C & Si5351a */
    i2c_init(i2c0, I2C_SPEED_HZ);
    gpio_set_function(I2C_SDA_PIN, GPIO_FUNC_I2C);
    gpio_set_function(I2C_SCL_PIN, GPIO_FUNC_I2C);
    gpio_pull_up(I2C_SDA_PIN);
    gpio_pull_up(I2C_SCL_PIN);
    si5351_init(i2c0);

    // Initial default LO tune to 7.050 MHz
    lo_candidate_t initial_cand;
    si5351_tune_frequency(i2c0, 7050000, 48000, BOARD_DIRECT_MODE, LO_MODE_BEST_INTEGER, &initial_cand);

    /* PIO Setup */
    g_pio_offset = pio_add_program(pio0, &i2s_rx_program);
    pio_sm_config c = i2s_rx_program_get_default_config(g_pio_offset);
    sm_config_set_in_pins(&c, PCM_DATA_PIN);
    sm_config_set_in_shift(&c, false, true, 32);
    sm_config_set_clkdiv(&c, 1.0f);
    pio_sm_init(pio0, 0, g_pio_offset, &c);
    pio_sm_set_enabled(pio0, 0, true);

    /* DMA Setup */
    dma_chan_a = dma_claim_unused_channel(true);
    dma_chan_b = dma_claim_unused_channel(true);

    dma_channel_config ca = dma_channel_get_default_config(dma_chan_a);
    channel_config_set_transfer_data_size(&ca, DMA_SIZE_32);
    channel_config_set_read_increment(&ca, false);
    channel_config_set_write_increment(&ca, true);
    channel_config_set_dreq(&ca, pio_get_dreq(pio0, 0, false));
    channel_config_set_chain_to(&ca, dma_chan_b);
    dma_channel_configure(dma_chan_a, &ca, buf_a, &pio0->rxf[0], g_words_per_buf, false);

    dma_channel_config cb = dma_channel_get_default_config(dma_chan_b);
    channel_config_set_transfer_data_size(&cb, DMA_SIZE_32);
    channel_config_set_read_increment(&cb, false);
    channel_config_set_write_increment(&cb, true);
    channel_config_set_dreq(&cb, pio_get_dreq(pio0, 0, false));
    channel_config_set_chain_to(&cb, dma_chan_a);
    dma_channel_configure(dma_chan_b, &cb, buf_b, &pio0->rxf[0], g_words_per_buf, false);

    apply_hardware_config(48000U);
    multicore_launch_core1(core1_entry);

    /* Initialize Pico W WiFi (CYW43439) */
    bool wifi_ok = false;
    if (cyw43_arch_init() == 0) {
        wifi_ok = true;
        cyw43_arch_enable_sta_mode();
        // Connect attempt with auto-auth detection (Open vs WPA2-PSK)
        uint32_t auth = (s_wifi_pass[0] == '\0') ? CYW43_AUTH_OPEN : CYW43_AUTH_WPA2_AES_PSK;
        const char *pass_param = (s_wifi_pass[0] == '\0') ? NULL : s_wifi_pass;
        cyw43_arch_wifi_connect_async(s_wifi_ssid, pass_param, auth);

        // Initialize OpenHPSDR UDP server and TCP Control
        openhpsdr_init(on_hpsdr_freq_change, on_hpsdr_rate_change);
        start_tcp_control_server();
    }

    uint32_t last_led_poll = 0;
    while (true) {
        tud_task();
        cdc_task();
        audio_task();
        openhpsdr_task();
        service_hpsdr_pending_tuning();
        if (wifi_ok) {
            cyw43_arch_poll();
        }

        // Continuous Heartbeat LED & Auto-reconnect
        uint32_t now_ms = to_ms_since_boot(get_absolute_time());
        if (wifi_ok && (now_ms - last_led_poll >= 250)) {
            last_led_poll = now_ms;
            int st = cyw43_tcpip_link_status(&cyw43_state, CYW43_ITF_STA);
            if (st == CYW43_LINK_UP) {
                // Heartbeat pulse: blink every 500ms (1 Hz) to show healthy main loop
                bool active = openhpsdr_is_active();
                uint32_t period = active ? 125 : 500; // Fast blink when streaming IQ, steady 1 Hz heartbeat when idle
                cyw43_arch_gpio_put(CYW43_WL_GPIO_LED_PIN, (now_ms / period) % 2);
            } else if (st == CYW43_LINK_JOIN || st == CYW43_LINK_NOIP) {
                cyw43_arch_gpio_put(CYW43_WL_GPIO_LED_PIN, (now_ms / 250) % 2); // Blinking while joining
            } else {
                cyw43_arch_gpio_put(CYW43_WL_GPIO_LED_PIN, (now_ms / 1000) % 2); // Slow pulse when down
                // Auto retry connecting every 10 seconds if link is down
                static uint32_t last_reconnect_ms = 0;
                if (now_ms - last_reconnect_ms >= 10000 && strlen(s_wifi_ssid) > 0) {
                    last_reconnect_ms = now_ms;
                    uint32_t auth = (s_wifi_pass[0] == '\0') ? CYW43_AUTH_OPEN : CYW43_AUTH_WPA2_AES_PSK;
                    const char *pass_param = (s_wifi_pass[0] == '\0') ? NULL : s_wifi_pass;
                    cyw43_arch_wifi_connect_async(s_wifi_ssid, pass_param, auth);
                }
            }
        }
    }
}

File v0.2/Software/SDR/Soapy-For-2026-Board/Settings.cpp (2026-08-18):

// Settings.cpp — Constructor, Si5351a math, frequency/sample-rate control.
//
// The Si5351a computation is a direct C++ port of the Python in
// quisk_conf_2026.py.  The CDC serial protocol is identical to that file.
//
// Protocol summary (115200 8N1, all lines \n-terminated):
//   → VER          ← VER,<version_string>
//   → XTAL         ← XTAL,<hz_float>
//   → MODE         ← MODE,DIRECT  or  MODE,JOHNSON
//   → RATE,<N>     ← OK
//   → FREQ,<si5351_hz>,<N>,<a>,<b>,<c>,<P1>,<P2>,<P3>
//                  ← (one blank/echo line)
//                  ← OK,G,<signed_offset>   (G = integer/golden)
//                  or OK,F,<signed_offset>   (F = fractional)
//   → MODE,DIRECT  ← OK
//   → MODE,JOHNSON ← OK

#include "Soapy2026SDR.hpp"
#include <SoapySDR/Logger.hpp>
#include <stdexcept>
#include <cmath>
#include <cstdlib>
#include <algorithm>
#include <sstream>

// ─── Constructor ─────────────────────────────────────────────────────────────

Soapy2026SDR::Soapy2026SDR(const SoapySDR::Kwargs &args)
    : _johnsonMode(false)
    , _johnsonAvailable(false)
    , _crystalFreq(24576000.0)
    , _centerFreq(7100000.0)
    , _audio(nullptr)
    , _sampleRate(48000.0)
    , _audioDeviceName("WWU SDR")
    , _ringHead(0), _ringTail(0), _ringCount(0), _ringOverflow(false)
{
    // Audio device name can be overridden via args
    if (args.count("audio_label")) {
        _audioDeviceName = args.at("audio_label");
        _audioLabelExplicit = true;
    }

    // ── Open serial port ──────────────────────────────────────────────────
    _serialPath = args.count("serial_port") ? args.at("serial_port") : "";
    if (_serialPath.empty())
        throw std::runtime_error("Soapy2026SDR: no serial_port specified");

    if (!_serial.open(_serialPath, 115200))
        throw std::runtime_error("Soapy2026SDR: cannot open " + _serialPath);

    SoapySDR_logf(SOAPY_SDR_INFO, "2026SDR: opened serial %s", _serialPath.c_str());

    // ── Board reset + ready handshake (mirrors quisk_conf_2026.py) ────────
    char ctrlcd[] = {0x03, 0x04, 0};
    _serial.writeLine(std::string(ctrlcd));
    _serial.flushInput();

    // Wait for "SDR ready"
    for (int i = 0; i < 30; i++) {
        std::string line = _serialReadLine(200);
        if (line.find("SDR ready") != std::string::npos) break;
    }

    // ── Query firmware parameters ─────────────────────────────────────────
    _firmwareVersion = _getParam("VER");
    SoapySDR_logf(SOAPY_SDR_INFO, "2026SDR: firmware %s", _firmwareVersion.c_str());

    std::string xtalStr = _getParam("XTAL");
    double xtal = std::atof(xtalStr.c_str());
    if (xtal > 0.0) _crystalFreq = xtal;
    SoapySDR_logf(SOAPY_SDR_INFO, "2026SDR: crystal %.3f Hz", _crystalFreq);

    std::string modeStr = _getParam("MODE");
    // Firmware returns "JOHNSON" only on v0.2; anything else means DIRECT
    // (older firmware may reply "OK" or not implement MODE at all)
    _johnsonMode      = (modeStr == "JOHNSON");
    _johnsonAvailable = (modeStr == "JOHNSON");
    SoapySDR_logf(SOAPY_SDR_INFO, "2026SDR: mode %s",
                  _johnsonMode ? "JOHNSON" : "DIRECT");

    // ── Set initial sample rate ───────────────────────────────────────────
    _setParam("RATE", std::to_string((int)_sampleRate));

    // ── Pre-allocate ring buffer ──────────────────────────────────────────
    _ring.assign(RING_FRAMES * 2, 0.0f); // *2 for I+Q per frame

    // ── Initialize miniaudio (sets up _audio) ────────────────────────────
    _setupAudio(); // defined in Streaming.cpp
}

Soapy2026SDR::~Soapy2026SDR()
{
    _teardownAudio(); // defined in Streaming.cpp
    _serial.close();
}

// ─── Identification ───────────────────────────────────────────────────────────

std::string Soapy2026SDR::getDriverKey() const   { return "2026SDR"; }

std::string Soapy2026SDR::getHardwareKey() const
{
    return _johnsonAvailable ? "WWU-2026-v0.2" : "WWU-2026-v0.1";
}

SoapySDR::Kwargs Soapy2026SDR::getHardwareInfo() const
{
    SoapySDR::Kwargs info;
    info["firmware"]    = _firmwareVersion;
    info["crystal_hz"]  = std::to_string(_crystalFreq);
    info["mixer_mode"]  = _johnsonMode ? "JOHNSON" : "DIRECT";
    info["johnson_ok"]  = _johnsonAvailable ? "yes" : "no";
    info["serial_port"] = _serialPath;
    info["audio_label"] = _audioDeviceName;
    return info;
}

// ─── Channels ────────────────────────────────────────────────────────────────

size_t Soapy2026SDR::getNumChannels(int direction) const
{
    return (direction == SOAPY_SDR_RX) ? 1 : 0;
}

// ─── Antenna ─────────────────────────────────────────────────────────────────

std::vector<std::string> Soapy2026SDR::listAntennas(int, size_t) const
{ return {"RX"}; }

void Soapy2026SDR::setAntenna(int, size_t, const std::string &) {}

std::string Soapy2026SDR::getAntenna(int, size_t) const { return "RX"; }

// ─── Gain (PCM1808 has no software-adjustable gain) ──────────────────────────

std::vector<std::string> Soapy2026SDR::listGains(int, size_t) const { return {}; }
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

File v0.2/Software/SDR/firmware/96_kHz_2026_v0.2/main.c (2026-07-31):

/*
 * main.c -- Research: 48/96 kHz Dual-Rate UAC1 SDR
 *
 * Extends the Lab 7 firmware with runtime 48/96 kHz switching:
 *
 *   - PCM1808 256fs mode (MD1=HIGH) delivers exactly 96 kHz from the same
 *     24.576 MHz crystal (256 * 96000 = 24 576 000 Hz).
 *   - 48 kHz uses the original 512fs mode (MD1=LOW).
 *   - BCK at 96 kHz = 6.144 MHz; PIO still runs at 125 MHz (32 ns/bit),
 *     well within the 81 ns BCK half-period -- no PIO changes needed.
 *
 * Rate selection:
 *   The USB descriptor advertises both 48 000 Hz and 96 000 Hz as discrete
 *   frequencies.  When Quisk opens the audio stream snd-usb-audio sends a
 *   UAC1 SET_CUR request; tud_audio_set_req_ep_cb() stores g_pending_rate.
 *   The CDC RATE,<hz> command (sent by Quisk during open()) also stores
 *   g_pending_rate.  The actual hardware switch happens in
 *   tud_audio_set_itf_cb() when the host selects alt 1 (stream start).
 *
 * Dual-core DMA reconfiguration:
 *   Core 0 pushes sentinel 0xFFFFFFFF into the inter-core FIFO.
 *   Core 1 detects the sentinel in its tight loop, stops both DMA channels,
 *   updates their trans_count from g_words_per_buf, restarts channel A,
 *   then acknowledges with 0xFFFFFFFE.
 *   Core 0 spins waiting for the ack before returning.
 *
 * USB audio format:
 *   bSubframeSize=3, bBitResolution=24 (S24_3LE).
 *   Each 32-bit DMA word carries the 24-bit sample in bits[31:8]; bits[7:0]
 *   are the PCM1808 zero-pad.  audio_task() packs to 3 bytes per sample:
 *     byte 0 = (w >> 8)  & 0xFF   -- D7..D0
 *     byte 1 = (w >> 16) & 0xFF   -- D15..D8
 *     byte 2 = (w >> 24) & 0xFF   -- D23..D16
 *   This strips the trailing zero byte and presents true S24_3LE to the host.
 *
 * Buffer geometry:
 *   Buffers are allocated for the maximum (96 kHz) size: 192 uint32_t words.
 *   At 48 kHz only the first 96 words are used per DMA transfer.
 *
 * REQUIRES TinyUSB master (pico-sdk bundles 0.18 which has no UAC1):
 *   git clone https://github.com/hathach/tinyusb ~/tinyusb
 *   export PICO_TINYUSB_PATH=$HOME/tinyusb
 *
 * Pin assignments (Intro-to-CAD-2026 v0.2 board, YD-RP2040 module):
 *   GPIO6   FMT  -- PCM1808 FMT (OUT, LOW = I2S standard format)
 *   GPIO8   MD1  -- PCM1808 MD1 (IN, HIGH=256fs/96kHz, LOW=512fs/48kHz)
 *   GPIO12  SDA  -- Si5351a I2C data
 *   GPIO13  SCL  -- Si5351a I2C clock
 *   GPIO9   DATA -- PCM1808 DOUT (PIO in_base)
 *   GPIO10  BCK  -- PCM1808 BCK  (PIO in_base + 1)
 *   GPIO11  WS   -- PCM1808 LRCK (PIO in_base + 2)
 *   GPIO22  DBG  -- DMA ISR toggle (logic analyser probe, ~500 Hz square wave)
 *
 * Protocol (line-oriented ASCII -- matches quisk_conf_96k.py):
 *
 *   VER
 *       -> VER,SDR C firmware 2.0\r\nOK\r\n
 *
 *   XTAL
 *       -> XTAL,24576000\r\nOK\r\n
 *
 *   MODE
 *       -> MODE,DIRECT\r\nOK\r\n
 *
 *   RATE,<hz>    (48000 or 96000)
 *       -> OK\r\n   (rate applied at next stream start)
 *
 *   FREQ,
 *       -> <last_hz>\r\nOK,<type>,0\r\n
 *
 *   FREQ,<hz>,<N>,<a>,<b>,<c>,<P1>,<P2>,<P3>
 *       -> <hz>\r\nOK,G,0\r\n  or  OK,F,0\r\n
 *
 * Startup sentinel: "SDR ready - waiting for precise integer commands...\r\n"
 * Resent on Ctrl-D (0x04).
 */

#include <stdio.h>
#include <stdlib.h>
#include <string.h>

#include "bsp/board_api.h"
#include "tusb.h"

#include "hardware/i2c.h"
#include "hardware/gpio.h"
#include "hardware/pio.h"
#include "hardware/dma.h"
#include "hardware/irq.h"
#include "pico/multicore.h"

#include "i2s_rx.pio.h"
#include "si5351.h"

/* ---- GPIO pin assignments ----------------------------------------- */
#define FMT_PIN       6    /* PCM1808 FMT   -> LOW = I2S standard fmt   */
#define MD1_PIN       8    /* PCM1808 MD1   -> LOW = Master 512fs       */
#define I2C_SDA_PIN   12   /* Si5351a SDA */
#define I2C_SCL_PIN   13   /* Si5351a SCL */
#define DATA_PIN      9    /* PCM1808 DOUT  -> PIO in_base */
#define BCK_PIN       10   /* PCM1808 BCK   -> PIO in_base + 1 */
#define WS_PIN        11   /* PCM1808 LRCK  -> PIO in_base + 2 */
#define DEBUG_PIN     22   /* DMA ISR toggle for logic analyser */

/* 100 kHz: required for the MS5351M clone on the 2026 v0.1 board.
 * Increase to 400000U only after verifying with a scope that ACK is seen. */
#define I2C_SPEED_HZ  100000U

/* Board topology — Intro-to-CAD-2026 v0.1 board uses DIRECT (CLK0->I,
 * CLK1->Q) with CLK1_PHOFF = N for exact 90 deg quadrature.
 * A v0.2 board will support either DIRECT or Johnson counter mode;
 * change this to false and update si5351_set_freq_regs() accordingly. */
#define BOARD_DIRECT_MODE  true

/* ---- Buffer geometry ---------------------------------------------- */
/*
 * Buffers are sized for the maximum rate (96 kHz = 192 words per 1 ms).
 * At 48 kHz only the first 96 words of each buffer are used per transfer.
 * g_words_per_buf is updated at runtime when the rate changes.
 *
 * 48 kHz: 48 frames/ms * 2 ch = 96 words = 288 bytes (3-byte packed)
 * 96 kHz: 96 frames/ms * 2 ch = 192 words = 576 bytes (3-byte packed)
 */
#define MAX_WORDS_PER_BUF   192   /* enough for 96 kHz stereo */

static uint32_t buf_a[MAX_WORDS_PER_BUF];
static uint32_t buf_b[MAX_WORDS_PER_BUF];
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

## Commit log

2026-01-30 Cleaning up unneeded files...
    [Audio_in_usd_sound_rp_pico.kicad_sch, cj4.kicad_sch]
2026-01-31 Placed more parts
    Still need to fix errors in schematic...
    [Frohne.kicad_pcb]
2026-01-31 Fixed a few schematic errors.
    [VDDA.kicad_sch, pcm1808.kicad_sch, qsd-sdr.kicad_sch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]
2026-02-01 More edits...
    [Frohne.kicad_pcb, raspberry_pi_pico.kicad_sch]
2026-02-02 Fixed a few more things and started routing.
    [Frohne.kicad_pcb, Frohne.kicad_sch, VDDA.kicad_sch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]
2026-02-02 Added R37 asd R38
    [Frohne.kicad_pcb, Frohne.kicad_sch, si5351a.kicad_sch]
2026-02-02 More tuning.
    [Frohne.kicad_pcb]
2026-02-03 Added some power traces
    [Frohne-B_Cu.gbr, Frohne-B_Mask.gbr, Frohne-B_Paste.gbr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]
2026-02-03 Routing everything now.
    [Frohne.kicad_pcb, qsd-sdr.kicad_sch]
2026-02-03 Unconnected 29
    [Frohne.kicad_pcb]
2026-02-03 Unconnected 16
    [Frohne.kicad_pcb]
2026-02-03 0 Unconnected 53 Errors
    [Frohne.kicad_pcb]
2026-02-03 0 unconnected, 0 Errors 411+ warnings
    [Frohne.kicad_pcb]
2026-02-04 Checking costs at JLCPCB
    [Frohne-B_Cu.gbr, Frohne-B_Mask.gbr, Frohne-B_Paste.gbr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]
2026-02-06 328 warnings
    [Frohne-B_Cu.gbr, Frohne-B_Mask.gbr, Frohne-B_Paste.gbr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]
2026-02-06 No warnings, errors
    [Frohne.kicad_pcb]
2026-02-06 Added som e3D models...
    [Frohne.kicad_pcb]
2026-02-08 Moved my work to the main directory.
    [Frohne-B_Cu.gbr, Frohne-B_Mask.gbr, Frohne-B_Paste.gbr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]
2026-02-11 Fixed offset on Pico 3D view
    [Intro-to-CAD-2026.kicad_pcb]
2026-02-11 Ignored overlaps, etc.
    Ignored a bunch of stuff that doesn't matter. I checked these earlier.
    [Intro-to-CAD-2026.kicad_pcb]
2026-02-12 An edit for Paola and Shaina
    [dac.kicad_sch]
2026-02-12 Eliminated 4 resistors.
    [dac.kicad_sch]
2026-02-13 Changed C_sample to 10nf
    And added 10 Ohm damping resistors.
    [Intro-to-CAD-2026.kicad_pcb, qsd-sdr.kicad_sch]
2026-02-15 Changed R55-58 values.
    [Intro-to-CAD-2026.kicad_pcb, dac.kicad_sch, qsd-sdr.kicad_sch]
2026-02-19 Moved DAC jack and planes.
    [Intro-to-CAD-2026.kicad_pcb, qsd-sdr.kicad_sch]
2026-02-19 Save to go home.
    [Intro-to-CAD-2026.kicad_pcb]
2026-02-19 Added module schematics.
    [Intro-to-CAD-2026.kicad_sch, Module_Andre.kicad_pcb, Module_Andre.kicad_sch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]
2026-02-19 Imported Student Parts
    Not using Project Instances yet.
    [Intro-to-CAD-2026.kicad_pcb, Intro-to-CAD-2026.kicad_sch, Module_Andre.kicad_sch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]
2026-02-19 Modules iimporoted but not wired.
    [Intro-to-CAD-2026.kicad_pcb, Module_Micah.kicad_pcb]
2026-02-19 Going to school.
    [Intro-to-CAD-2026.kicad_pcb, Intro-to-CAD-2026.kicad_sch, Module_Andre.kicad_sch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]
2026-02-19 No Errors No Warnings
    Some were excluded.
    [Intro-to-CAD-2026.kicad_sch, Module_Andre.kicad_sch, Module_JaronGarbi.kicad_pcb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]
2026-02-20 Beautifying it.
    [EC11-SMD-15F-black.step, Module_JaronGarbi.kicad_sch, Socket Micro SD.STEP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]
2026-02-20 Adding TC118S
    [Intro-to-CAD-2026.kicad_sch, h_bridge.kicad_sch]
2026-02-20 Added H-Bridge PCB Edits
    [Intro-to-CAD-2026.kicad_sch, h_bridge.kicad_sch]
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2026-02-20 Replaced Jaron's LEDs
    They were only for Standard Boards.
    [Frohne-B_Cu.gbr, Frohne-B_Mask.gbr, Frohne-B_Paste.gbr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]
2026-02-20 Four layer now going to six (this is still 4)
    [Intro-to-CAD-2026-B_Cu.gbr, Intro-to-CAD-2026-B_Mask.gbr, Intro-to-CAD-2026-B_Paste.gbr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]
2026-02-22 Fixed DAC
    [Intro-to-CAD-2026.kicad_pcb, Intro-to-CAD-2026.kicad_sch, cmos_oscillator.kicad_sch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]
2026-02-22 Found and replaced 10 buried/blind vias.
    [Intro-to-CAD-2026.kicad_pcb]
2026-02-22 Fixed RST
    [Frohne-B_Cu.gbr, Frohne-B_Mask.gbr, Frohne-B_Paste.gbr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]
2026-02-22 Fixed 3.5mm jack labels
    [Intro-to-CAD-2026.kicad_pcb]
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2026-02-24 Fixed U7 to the right part (C2674552)
    [Intro-to-CAD-2026-B_Cu.gbr, Intro-to-CAD-2026-B_Mask.gbr, Intro-to-CAD-2026-B_Paste.gbr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]
2026-02-24 Finished fix of U7.
    [Intro-to-CAD-2026-B_Cu.gbr, Intro-to-CAD-2026-B_Mask.gbr, Intro-to-CAD-2026-B_Paste.gbr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]
2026-02-24 One more change on U7.
    [Intro-to-CAD-2026.kicad_pcb]
2026-02-24 Fixed pinout error on LEDs.
    [Intro-to-CAD-2026.kicad_pcb, Module_JaronGarbi.kicad_sch]
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2026-02-25 Add .gbr to .gitignore
    [Intro-to-CAD-2026-B_Cu.gbl, Intro-to-CAD-2026-B_Cu.gbr, Intro-to-CAD-2026-B_Mask.gbr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]
2026-02-27 Changed for Resubmission 2-27-2026
    [Intro-to-CAD-2026-B_Cu.gbl, Intro-to-CAD-2026-B_Mask.gbs, Intro-to-CAD-2026-B_Paste.gbp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]
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2026-03-01 Fixed label on DAC schematic.
    [dac.kicad_sch]
2026-04-01 Initial v0.2
    Fixed SCL-SDA swap, 3V3 on encoder, and 3D models for Kicad 10
    [Intro-to-CAD-2026.kicad_pcb, Intro-to-CAD-2026.kicad_sch, Module_Andre.kicad_sch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]
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2026-04-14 Updated errors
    [Intro-to-CAD-2026.kicad_sch, Module_Andre.kicad_sch, VDDA.kicad_sch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]
2026-04-24 Starting a new branch for v0.2
    [Intro-to-CAD-2026.kicad_sch, Module_Andre.kicad_sch, VDDA.kicad_sch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]
2026-04-24 Addid intital pcb commits
    [Intro-to-CAD-2026.kicad_pcb]
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2026-04-30 Fix Cadyn Quisk crystal fallback
    [quisk_conf_cadyn.py]
2026-05-04 Adding fixes:
    LDO for LO. Reduce gain by 10/1.5. Add better bypassing for VDDA/2 and CMOS Oscillator. Added Johnson counter. This is schematic only at the moment.
    [VDDA.kicad_sch, cmos_oscillator.kicad_sch, qsd-sdr.kicad_sch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]
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2026-05-04 Made cutoff about 150 kHz
    [qsd-sdr.kicad_sch]
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2026-05-05 Placed the second ADC
    [CJC5340.kicad_sch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]
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2026-05-06 Fixing unconnected
    [Intro-to-CAD-2026.kicad_pcb]
2026-05-06 Fixing errors 16 unconnected, 24 violations
    [Intro-to-CAD-2026.kicad_pcb]
2026-05-06 Finally 0 errors
    [Intro-to-CAD-2026.kicad_pcb]
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2026-05-06 Jumper text on the back.
    [Intro-to-CAD-2026.kicad_pcb]
2026-05-06 Fixing jumper labels and missing wire
    [Intro-to-CAD-2026.kicad_pcb, pcm1808.kicad_sch, qsd-sdr.kicad_sch]
2026-05-06 Fixed sub-schematic versions
    [CJC5340.kicad_sch, Intro-to-CAD-2026.kicad_pcb, Module_Andre.kicad_sch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]
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2026-05-06 3D Model of LEDs
    [Intro-to-CAD-2026.kicad_pcb, XL-0807RGBC-WS2812B_XLG.step]
2026-05-07 Changed push pull to PAM8908
    [CJC5340.kicad_sch, Intro-to-CAD-2026.kicad_pcb, dac.kicad_sch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]
2026-05-07 fixing labels 0errors
    [Intro-to-CAD-2026.kicad_pcb, qsd-sdr.kicad_sch]
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2026-05-07 Yet more label tweaks
    [Intro-to-CAD-2026.kicad_pcb]
2026-05-07 H IN < 7V
    [Intro-to-CAD-2026.kicad_pcb]
2026-05-07 H-IN on 4.7 V
    [h_bridge.kicad_sch]
2026-05-07 Fixed CJC5340 C Number
    [Intro-to-CAD-2026.kicad_pcb, dac.kicad_sch, h_bridge.kicad_sch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]
2026-05-08 Input circuit for the CJT5340
    [CJC5340.kicad_sch, Intro-to-CAD-2026.kicad_pcb, pcm1808.kicad_sch]
2026-05-08 R43 and R44 to 100 Ohms
    [Intro-to-CAD-2026.kicad_pcb, pcm1808.kicad_sch]
2026-05-08 3D model of the 40 pin connectors.
    [Intro-to-CAD-2026.kicad_pcb, Pin Header - RaspberryPi - Stacking - 2.54mm_V2.step]
2026-05-26 Funny thing, SCXI1 and SCKI2 are mixed up, PCB vs Schematic
    [Intro-to-CAD-2026.kicad_pcb, cmos_oscillator.kicad_sch, dac.kicad_sch]
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2026-06-11 Emergency save - all files are safe
    [Pin Header - RaspberryPi - Stacking - 2.54mm_V2.step, cmos_oscillator.kicad_sch, dac.kicad_sch]
2026-07-15 fixed version and page type
    [CJC5340.kicad_sch, Module_Andre.kicad_sch, Module_JaronGarbi.kicad_sch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]
2026-07-31 chore: move v0.2 board files under v0.2/Hardware
    Relocate the KiCad project, libraries, production outputs, and supporting
    assets into a version-rooted Hardware tree. Keep student Module_* at repo
    root temporarily; MicroPythonSDR remains for the Software move.
    [Amphenol RF 122404.STEP, C18594.step, CJC5340.kicad_sch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]
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2026-07-31 feat: add v0.1 tree, docs, and finish version-split layout
    Import v0.1 Hardware from master; place MicroPythonSDR and Soapy under both
    v0.1 and v0.2 Software/SDR. Point KiCad lib tables at KIPRJMOD. Document
    layout and credits; drop student Module_* from the active tree (recoverable
    from archive/pre-version-split). Note Research firmware restore paths.
    [Amphenol RF 122404.STEP, C18594.step, Download_STEP_150505M173300_rev1.stp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]
2026-07-31 Fix Module References in v0.2
    [Intro-to-CAD-2026.kicad_sch, Module_Andre.kicad_sch, Module_JaronGarbi.kicad_sch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]
2026-07-31 Fixed modules in v0.1
    [Intro-to-CAD-2026.kicad_pcb, Intro-to-CAD-2026.kicad_sch, Module_Andre.kicad_sch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]
2026-08-14 Adding the Spotting and a start on the OpenHPSDR protocol 1
    [tusb_config.h.txt]
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2026-08-18 Fixing it so it works with SDR++ and WiFi
    [Settings.cpp, main.c]
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

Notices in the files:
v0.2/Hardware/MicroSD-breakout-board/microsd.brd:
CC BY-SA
